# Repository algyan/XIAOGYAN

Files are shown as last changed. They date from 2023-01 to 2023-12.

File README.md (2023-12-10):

# XIAOGYAN

IoT ALGYAN 8周年 オリジナルIoTデバイス「XIAOGYAN」のリポジトリです。

IoTをやってみたい人から、バリバリのベテランにも楽しんでもらえるIoTデバイスを目指しています。

* デバイス、ソフトウェア、クラウドの全てにおいて、完成品（クラウドはお試しする場所）を提供するとともに、全てをオープン、カスタマイズ可能に
* 入手しやすい部品（ほぼ全ての部品を秋月電子通商で入手できる）
* 部品代は3000円以内
* 開発PCはWindows, macOS, Linux

ご質問、ご意見は[Discussions](https://github.com/algyan/XIAOGYAN/discussions)や[Issues](https://github.com/algyan/XIAOGYAN/issues)へ。お気軽にどうぞ。

## 構成

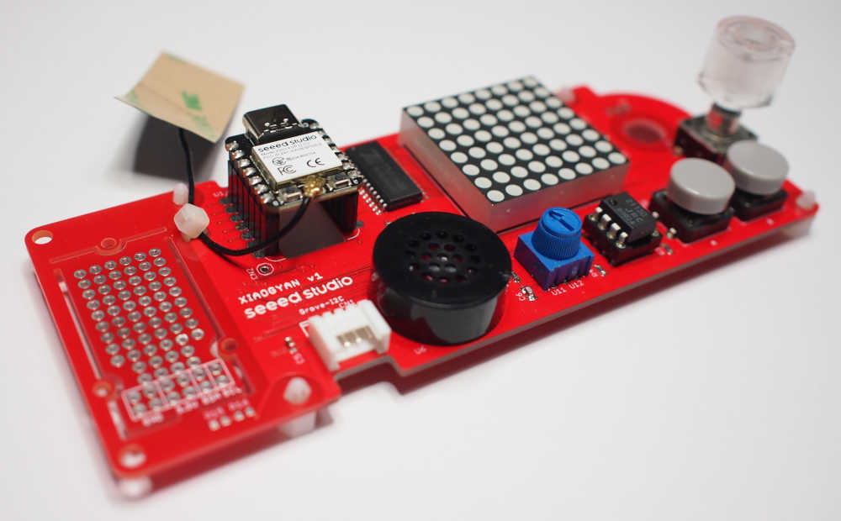
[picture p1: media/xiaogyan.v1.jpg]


```mermaid
flowchart LR
    id1[LEDマトリックス]---id7[LEDドライバ]
    id7-- x2 DO ---id2[マイコン]
    id3[スピーカー]---id11[パワーアンプ]
    id11-- x1 PWM,x1 DO ---id2
    id4[ロータリーエンコーダー]-- x2 DI ---id2
    id8[x1 LED]-- x1 DO ---id2
    id9[x2 ボタン]-- x2 DI ---id2
    id2-- Wi-Fi ---id6[Azure IoT]
    id10[Grove I2C]-- I2C ---id2
```

## マニュアル

* [しおり（手引書）](manuals/guidebook/README.md)
* [部品手配マニュアル](manuals/order/README.md)
* [機材マニュアル](manuals/equipment/README.md)
* [組立マニュアル](manuals/assembly/README.md)
* [動作確認マニュアル](manuals/test/README.md)
* [ソフトウェア開発マニュアル](manuals/software/README.md)

## 事例

* [XIAOGYANやってみたよ！！ユーザー投稿](https://github.com/algyan/XIAOGYAN/discussions/50)
* [XIAOGYANbitLess （XIAOGYANをScratchで使うためのプログラム）](https://github.com/610t/XIAOGYANbitLess)
* [XIAO-ESP32-C3 で AtomVM を動作させたときのメモ](https://gist.github.com/pojiro/ccb9d88dedd0590a8ac6930b37633ee0)
* [XIAOGYANでEagleのグリッド切り替え](https://github.com/lipoyang/GridSwitch)

## リファレンス

* ハードウェア
  * [部品リスト](hardware/xiaogyan.v1.xlsx)
  * [部品貼付台紙](hardware/xiaogyan_pasteboard.v1.pdf)
  * [回路図(v1)](hardware/xiaogyan.v1.pdf)
  * [回路図(v1.1)](hardware/xiaogyan.v1.1.pdf)

* ソフトウェア
  * [サンプルコード](https://github.com/algyan/xiaogyan_examples)
  * [Arduino用ライブラリ](https://github.com/algyan/xiaogyan_arduino)

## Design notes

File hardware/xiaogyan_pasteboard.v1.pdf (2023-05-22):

# 【ALGYAN 8th プリント基板(XIAOGYAN) パーツリスト】

チップ抵抗0Ω
[ R8,R9 ]

チップ抵抗10KΩ
[ R1,R2,R3,R4,R5,R6,R7 ]

チップコンデンサ0.1uF
[ C1 ]

チップコンデンサ1uF
[ C2 ]

チップコンデンサ10uF
[ C3,C4,C5 ]

③
チップコンデンサ1000pF
[ C6 ]
① | ② | ⑯ | ④ | ⑤
LEDドライバIC(TM1640) [ U2 ] 向き注意 ⑥ | アンプIC(NJM2113D) [ U4 ] 向き注意 ⑦ | ボタン・可変抵抗 [ U9,U10,U11 ] ⑧ | スピーカー(UGSM23A) [ U6 ] 向き注意 ⑨ | LEDマトリックス(LTP-12188M-08) [ U3 ] 向き注意 ⑩
Groveコネクタ [ CN1 ] 向き注意 ⑪ | 細ピンヘッダ・分割ロング ピンソケット ⑫ | マイコン(XIAO ESP32C3) [ U1 ] 向き注意 ⑬ | ロータリーエンコーダー (EC12PLRVF) [ U7 ] ⑭ | 基板スペーサー ⑮

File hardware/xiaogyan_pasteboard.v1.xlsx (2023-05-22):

チップ抵抗0Ω [ R8,R9 ] | チップ抵抗10KΩ [ R1,R2,R3,R4,R5,R6,R7 ] | チップコンデンサ0.1uF [ C1 ] | チップコンデンサ1uF [ C2 ] | チップコンデンサ10uF [ C3,C4,C5 ]
 |  | ③
 |  | チップコンデンサ1000pF [ C6 ]
① | ② | ⑯ | ④ | ⑤
LEDドライバIC(TM1640) [ U2 ] | アンプIC(NJM2113D) [ U4 ] | ボタン・可変抵抗 [ U9,U10,U11 ] | スピーカー(UGSM23A) [ U6 ] | LEDマトリックス(LTP-12188M-08) [ U3 ]
向き注意 | 向き注意 |  | 向き注意 | 向き注意
⑥ | ⑦ | ⑧ | ⑨ | ⑩
Groveコネクタ [ CN1 ] | 細ピンヘッダ・分割ロングピンソケット | マイコン(XIAO ESP32C3) [ U1 ] | ロータリーエンコーダー(EC12PLRVF) [ U7 ] | 基板スペーサー
向き注意 |  | 向き注意
⑪ | ⑫ | ⑬ | ⑭ | ⑮

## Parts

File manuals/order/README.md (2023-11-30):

# XIAOGYAN 部品手配マニュアル🛒

XIAOGYANの完成品を入手する方法はありません。ご自身で部品を入手して、組み立てる必要があります。

必要な部品は[部品リスト](../../hardware/xiaogyan.v1.xlsx)に書いてあります。一部の部品を除き、ほとんどの部品は秋月電子通商のWebサイトで購入できます。本マニュアルを参考に、XIAOGYAN基板と部品を入手してください。

---

## 目次

1. [XIAOGYAN基板を入手](#xiaogyan基板を入手)
2. [秋月電子通商から購入](#秋月電子通商から購入)
3. [チップ抵抗（10KΩ）を購入](#チップ抵抗10kωを購入)

---

## XIAOGYAN基板を入手

matsujirushiのBOOTHから購入できます。

* [XIAOGYAN基板（10KΩ抵抗付き）](https://matsujirushi.booth.pm/items/5108023)

> 以前はイベントでXIAOGYAN基板を配布していましたが、[2023/9/2のイベント](https://algyan.connpass.com/event/292100/)を最後に配布は無くなりました。（Seeed株式会社から提供いただいた分が全て配布されました。）

~~XIAOGYAN基板は非売品です。IoT ALGYANコミュニティの特定イベントで配布しています。イベントに参加して入手してください。~~

* ~~[IoT ALGYANコミュニティのイベント](https://algyan.connpass.com/event/)~~

## 秋月電子通商から購入

> ここでは部品を購入しますが、もし機材も購入するなら一緒に注文したほうが送料が抑えられてお得です。  
> 機材について確認、検討いてから注文をオススメします。 -> [機材マニュアル](../equipment/README.md)

1. 秋月電子通商のWebサイトを開いて、部品を買い物かごに入れてください。

    下記リンクをクリックすると、秋月電子通商のWebサイトが表示されて、XIAOGYANの部品が自動的に買い物かごに入ります。

    * [秋月電子通商 部品を買い物かごに入れる](https://akizukidenshi.com/catalog/cart/cart.aspx?goods=R-11619,P-16143,P-16994,P-13161,P-09285,C-12634,M-17454,C-04398,C-10073,I-13225,I-09878,I-11192,P-09797,P-05762,P-09828,P-06110,P-10089,&qty=1,1,1,1,1,1,1,1,1,1,1,1,1,1,2,1,4,)

2. 買い物かごの部品に間違いがないか確認してください。

    商品数は17品、商品小計は2700円（2023/5/9調べ）です。

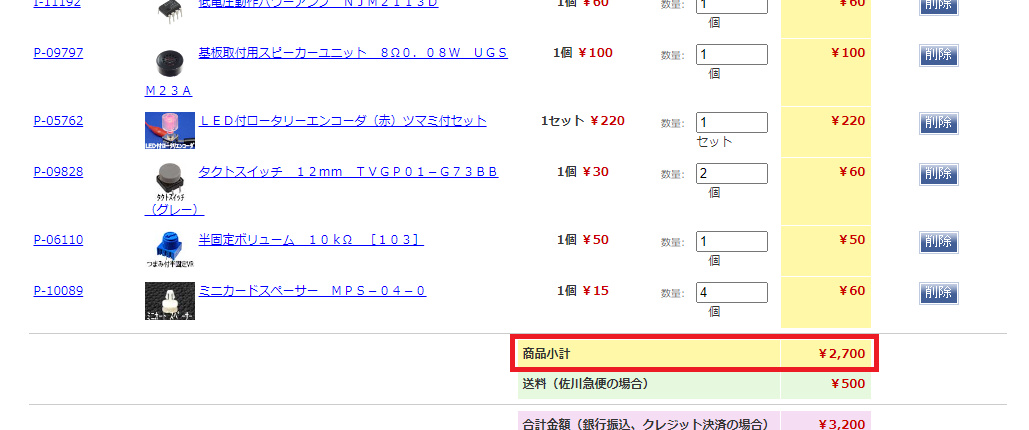
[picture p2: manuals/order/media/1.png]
    

3. 注文してください。

    注文画面へ進み、必要事項を記入して注文してください。

## チップ抵抗（10KΩ）を購入

秋月電子通商はチップ抵抗（10KΩ）をバラ売りしていません。秋月電子通商の5000個入りを購入するか、他店で購入してください。必要数は7個です。

* 秋月電子通商 [チップ抵抗　１／１０Ｗ１０ｋΩ　（５０００個入）](https://akizukidenshi.com/catalog/g/gR-15029/)
* マルツエレック [1608角形チップ抵抗器 RK73H 10kΩ 0.1W ±1%【RK73H1JTTD1002F】](https://www.marutsu.co.jp/pc/i/857775/)
* 共立電子産業 [チップ抵抗(1608) 10kΩ★受注単位有★](https://eleshop.jp/shop/g/gABQ364/)

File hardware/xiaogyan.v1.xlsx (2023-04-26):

 |  |  | 合計 | 2700
Part | Value | 通販コード | 入数 | 価格 | （価格） | 在庫グレード | 通販在庫数(2/2) | 通販在庫数(2/8) | 通販在庫数(3/6) | 通販在庫数(3/27)
R1 | 10K
R2 | 10K | (R1)
R3 | 10K | (R1)
R4 | 10K | (R1)
R5 | 10K | (R1)
R6 | 10K | (R1)
R7 | 10K | (R1)
R8 | 0 | R-11619 | 200 | 100 |  | AAA | 340 | 330 | 306 | 284
R9 | 0 | (R8)
R10 | DNP
R11 | DNP
R12 | DNP
R13 | DNP
R14 | DNP
R15 | DNP
R16 | DNP
C1 | 0.1u | P-16143 | 40 | 110 |  | AAA | 100 | 100 | 100 | 100
 |  | P-05728 | 100 |  | 200 | D,AAA |  | 2437 | 2393 | 2385
C2 | 1u | P-16994 | 20 | 200 |  | AAA | 2960 | 2947 | 2919 | 2898
C3 | 10u | P-13161 | 10 | 150 |  | AAA | 22187 | 22100 | 21869 | 21620
C4 | 10u | (C3)
C5 | 10u | (C3)
C6 | 1000p | P-09285 | 100 | 180 |  | AAA
C7 | DNP
C8 | DNP
CN1 | 4P-2.0 | C-12634 | 10 | 150 |  | AAA | 706 | 690 | 554 | 514
CN2
U1 | XIAO ESP32C3 | M-17454 | 1 | 940 |  | AAA | 2024 | 2005 | 1798 | 1642
 | 細ピンヘッダ | C-04398 | 1 | 20 |  | AA
 | 細ピンソケット | C-10073 | 1 | 80 |  | AAA
U2 | TM1640 | I-13225 | 1 | 80 |  | D,AAA | 3664 | 3664 | 3650 | 3642
U3 | LTP-12188M-08 | I-09878 | 1 | 140 |  | AAA | 561 | 506 | 486 | 482
U4 | NJM2113D | I-11192 | 1 | 60 |  | AA | 257 | 256 | 235 | 232
U5 | NJM2113M | I-10981 | 1 |  | 50 | D,A |  | 2 | 42 | 31
U6 | UGSM23A | P-09797 | 1 | 100 |  | AAA | 2848 | 2844 | 2816 | 2809
U7 | EC12PLRVF | P-05762 | 1 | 220 |  | AAA | 412 | 409 | 399 | 395
U8 | EC12E(Panel) | P-06357 | 1 |  | 80 | A | 0 | 0 | 0 | 0
U9 | TVGP01-G73BB | P-09828 | 1 | 30 |  | AAA | 4278 | 3880 | 2561
U10 | TVGP01-G73BB | P-09828 | 1 | 30 |  | AAA | 4278 | 3880 | 2561
U11 | 10K | P-06110 | 1 | 50 |  | AAA | 2000 | 2000 | 2000
U12 | DNP | P-08012 |  |  | 50 | AAA |  |  | 10454
U13 | DNP
JP1
JP2
JP3
 | MPS-04-0 | P-10089 | 1 | 15 |  | AAA
 | MPS-04-0 | P-10089 | 1 | 15 |  | AAA
 | MPS-04-0 | P-10089 | 1 | 15 |  | AAA
 | MPS-04-0 | P-10089 | 1 | 15 |  | AAA

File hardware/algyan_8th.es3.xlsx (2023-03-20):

 |  |  |  |  |  |  | 合計 | 2360
Part | Value | 通販コード | 在庫グレード | 通販在庫数(2/2) | 通販在庫数(2/8) | 通販在庫数(3/6) | 入数 | 価格 | （価格） | v1
C1 | 10u | P-13161 | AAA | 22187 | 22100 | 21869 | 10 | 150 |  | C3
C2 | 0.1u | P-16143 | AAA | 100 | 100 | 100 | 40 | 110 |  | C1
 |  | P-05728 | D,AAA |  | 2437 | 2393 | 100 |  | 200
C3 | DNP |  |  |  |  |  |  |  |  | C6
C5 | 1u | P-16994 | AAA | 2960 | 2947 | 2919 | 20 | 200 |  | C2
C6 | 10u | (C1) |  |  |  |  |  |  |  | C4
C7 | DNP |  |  |  |  |  |  |  |  | C7
C8 | DNP |  |  |  |  |  |  |  |  | C8
C9 | 10u | (C1) |  |  |  |  |  |  |  | C5
CN1 | 4P-2.0 | C-12634 | AAA | 706 | 690 | 554 | 10 | 150 |  | CN1
JP1 |  |  |  |  |  |  |  |  |  | JP1
JP2 |  |  |  |  |  |  |  |  |  | JP3
JP3 |  |  |  |  |  |  |  |  |  | CN2
JP5 |  |  |  |  |  |  |  |  |  | JP2
LED1 | DNP |  |  |  |  |  |  |  |  | U13
R1 | 10K |  |  |  |  |  |  |  |  | R1
R2 | 10K | (R1) |  |  |  |  |  |  |  | R2
R3 | 10K | (R1) |  |  |  |  |  |  |  | R3
R4 | 10K | (R1) |  |  |  |  |  |  |  | R4
R5 | 0 | R-11619 | AAA | 340 | 330 | 306 | 200 | 100 |  | R7
R7 | 10K | (R1) |  |  |  |  |  |  |  | R5
R8 | DNP |  |  |  |  |  |  |  |  | R10
R9 | DNP |  |  |  |  |  |  |  |  | R11
R10 | 0 | (R5) |  |  |  |  |  |  |  | R8
R11 | 0 | (R5) |  |  |  |  |  |  |  | R9
R12 | DNP |  |  |  |  |  |  |  |  | R12
R13 | DNP |  |  |  |  |  |  |  |  | R13
R14 | DNP |  |  |  |  |  |  |  |  | R14
R15 | DNP |  |  |  |  |  |  |  |  | R15
R16 | DNP |  |  |  |  |  |  |  |  | R16
R18 | 10K | (R1) |  |  |  |  |  |  |  | R6
U1 | XIAO | M-17454 | AAA | 2024 | 2005 | 1798 | 1 | 940 |  | U1
U2 | TM1640 | I-13225 | D,AAA | 3664 | 3664 | 3650 | 1 | 80 |  | U2
U4 | LTP-12188M-08 | I-09878 | AAA | 561 | 506 | 486 | 1 | 140 |  | U3
U5 | NJM2113D | I-11192 | AA | 257 | 256 | 235 | 1 | 60 |  | U4
U3 | NJM2113M | I-10981 | D,A |  | 2 | 42 | 1 |  | 50 | U5
U6 | UGSM23A | P-09797 | AAA | 2848 | 2844 | 2816 | 1 | 100 |  | U6
U7 | EC12PLRVF | P-05762 | AAA | 412 | 409 | 399 | 1 | 220 |  | U7
U10 | EC12E(Panel) | P-06357 | A | 0 | 0 | 0 | 1 |  | 80 | U8
U8 | TVGP01-G73BB | P-09828 | AAA | 4278 | 3880 | 2561 | 1 | 30 |  | U9
U9 | TVGP01-G73BB | P-09828 | AAA | 4278 | 3880 | 2561 | 1 | 30 |  | U10
VR1 | 10K | P-06110 | AAA | 2000 | 2000 | 2000 | 1 | 50 |  | U11
VR2 | 10K | P-08012 | AAA |  |  | 10454 |  |  | 50 | U12

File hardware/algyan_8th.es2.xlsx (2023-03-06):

 |  |  |  |  |  | 合計 | 2480
Part | Value | 通販コード | 在庫グレード | 通販在庫数(2/2) | 通販在庫数(2/8) | 入数 | 価格 | （価格）
C1 | 10u | P-13161 | AAA | 22187 | 22100 | 10 | 150
C2 | 0.1u | P-16143 | AAA | 100 | 100 | 40 | 110
 |  | P-05728 | AAA |  | 2437 | 100 |  | 200
C3 | DNP
C5 | 1u | P-16994 | AAA | 2960 | 2947 | 20 | 200
C6 | 10u | (C1)
C7 | DNP
C8 | DNP
C9 | 10u | (C1)
CN1 | 4P-2.0 | C-12634 | AAA | 706 | 690 | 10 | 150
JP1
JP2
JP3
JP5
LED1 | LED5MM | I-11580 | AAA | 2411 | 2406 | 10 | 120
R1 | 100K
R2 | 100K | (R1)
R3 | 10K
R4 | 10K | (R3)
R5 | 0 | R-11619 | AAA | 340 | 330 | 200 | 100
R6 | 0 | (R5)
R7 | ?
R8 | DNP
R9 | DNP
R10 | 0 | (R5)
R11 | 0 | (R5)
R12 | 10K | (R3)
R13 | DNP
R14 | DNP
R15 | DNP
R16 | DNP
R17 | 0 | (R5)
U1 | XIAO | M-17454 | AAA | 2024 | 2005 | 1 | 940
U2 | TM1640 | I-13225 | D,AAA | 3664 | 3664 | 1 | 80
U3 | NJM2113M | I-10981 | D,A |  | 2 | 1 |  | 50
U4 | LTP-12188M-08 | I-09878 | AAA | 561 | 506 | 1 | 140
U5 | NJM2113D | I-11192 | AA | 257 | 256 | 1 | 60
U6 | UGSM23A | P-09797 | AAA | 2848 | 2844 | 1 | 100
U7 | EC12PLRVF | P-05762 | AAA | 412 | 409 | 1 | 220
U8 | TVGP01-G73BB | P-09828 | AAA | 4278 | 3880 | 1 | 30
U9 | TVGP01-G73BB | P-09828 | AAA | 4278 | 3880 | 1 | 30
U10 | EC12E(Panel) | P-06357 | A | 0 | 0 | 1 |  | 80
VR1 | 10K | P-06110 | AAA | 2000 | 2000 | 1 | 50
VR2 | 10K | P-08012 | AAA

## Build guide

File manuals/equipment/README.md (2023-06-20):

# XIAOGYAN 機材マニュアル

## 1. 機材（極力、お安い構成） - 6000円未満

| 品名 | 型番 | 販売店 |
| :-- | :-- | :-- |
| はんだごて | CXR-41 | 秋月電子通商 T-02542 |
| こて台 | ST-77 | 秋月電子通商 T-06870 |
| 糸はんだ | SD-62 | 秋月電子通商 T-02594 |
| はんだ吸い取り線 | CP-3015 | 秋月電子通商 T-02539 |
| ニッパー | | 100円ショップ |
| ピンセット | | 100円ショップ |
| マスキングテープ | | 100円ショップ |
| テスター | DT-830B.3L | 秋月電子通商 M-08366 |

## 2. 機材（少し良いモノ構成） - 10000円未満

| 品名 | 型番 | 販売店 |
| :-- | :-- | :-- |
| はんだごて | FX600-02 | 秋月電子通商 T-14456 |
| こて台 | FH300-81 | 秋月電子通商 T-14458 |
| 糸はんだ | SD-62 | 秋月電子通商 T-02594 |
| はんだ吸い取り線 | CP-3015 | 秋月電子通商 T-02539 |
| はんだ吸い取り器 | GS-158 | 秋月電子通商 T-17386 |
| ニッパー | | 100円ショップ |
| ピンセット | TS-15 | 秋月電子通商 T-02541 |
| マスキングテープ | | 100円ショップ |
| テスター | DT-830B.3L | 秋月電子通商 M-08366 |

## 3. 機材（松岡の場合）

| 品名 | 製品 | こだわり |
| :-- | :-- | :-- |
| はんだごて | FX-600 + T18-C08 + M19-03 | 温調付き。 |
| こて台 | 不明 |  |
| 糸はんだ | SF-A0404 + FS600-02 | 0.4mmと0.8mm。付けにくいけど安心な鉛フリー。 |
| はんだ吸い取り線 | CP-2515 |  |
| はんだ吸い取り器 | SC-7000 | 電動。 |
| ニッパー | NS-03 | 開き量が設定できるので手が疲れない。 |
| ピンセット | PT-21 + P-640-J + 不明 | SMDチップ部品対応品。 |
| マスキングテープ | 243J Plus + MT-15P | プッシュカット便利。 |
| テスター | 753603 | |

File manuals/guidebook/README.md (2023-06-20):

# XIAOGYAN しおり🔖

ようこそ！XIAOGYANプロジェクトへ！

近年、電子工作がマジでお手軽になりましたね。ネットでポチれば数日で手元にくるし、高機能なマイコンやセンサーなども1個でも買うことができるようになりました。しかもお小遣い程度の金額で。数百万円出さないと使えなかった開発ツールは同等のものがタダで手に入ります。やる気と行動力さえあれば「わたしの欲しかったわたしのためのデバイス」を作って動かすことができちゃいます。
最近は、M5StackやreTerminalのようなディスプレイやボタンが付いているケース入りの製品で、センサーなどをコネクタで繋いでソフトウェアをチョイと書いてパッと仕上げること可能です。

便利になった反面、ちょっと寂しいなと思うところがあります。はんだ付けがうまくできたとかできなかったとか、部品壊れた悲しいとか。一喜一憂する電子工作の楽しさが減ってしまっているような気がしています。

そこで、オリジナルIoTデバイス**XIAOGYAN**をALGYANコミュニティで先導（扇動？）することにしました。

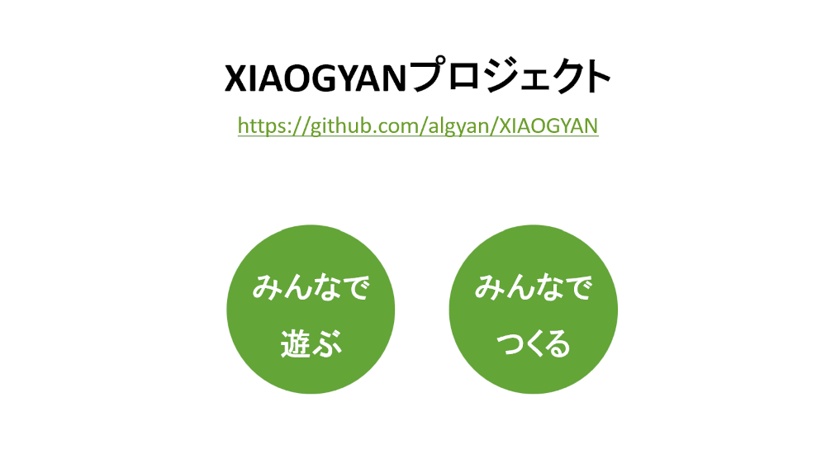
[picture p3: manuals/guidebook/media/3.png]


[「XIAOGYAN」への思い（動画）](https://www.youtube.com/watch?v=LFgrQTpkMbk&t=739s)

* デバイス、ソフトウェア、クラウドの全てをオープン、カスタマイズ可能に
* 入手しやすい部品
* 部品代は3000円以内
* 開発PCはWindows, macOS, Linux
* プロジェクトの進行もオープンに

見ているだけではダメです！
XIAOGYANプロジェクトに参加して、ぜひ一緒に楽しみましょう。

## XIAOGYANデバイス

XIAOGYANプロジェクトで用意したデバイスがこちらです。

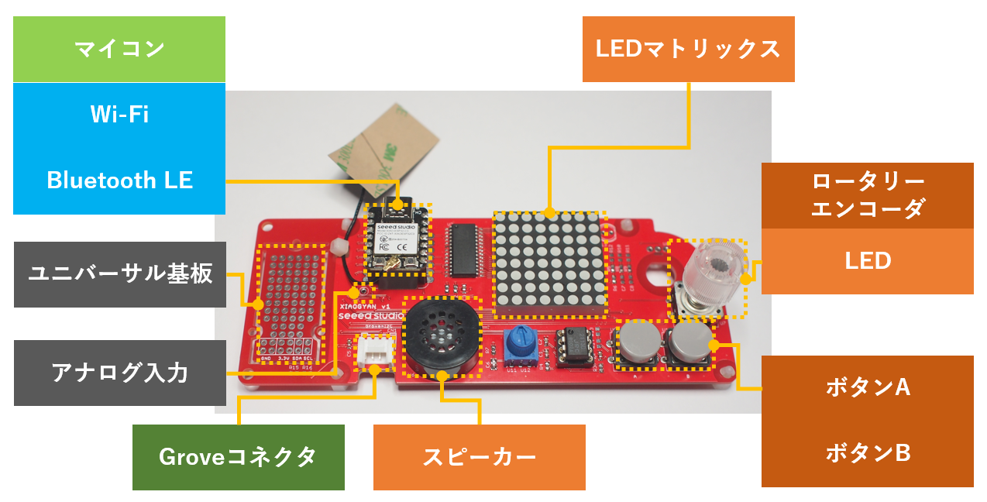
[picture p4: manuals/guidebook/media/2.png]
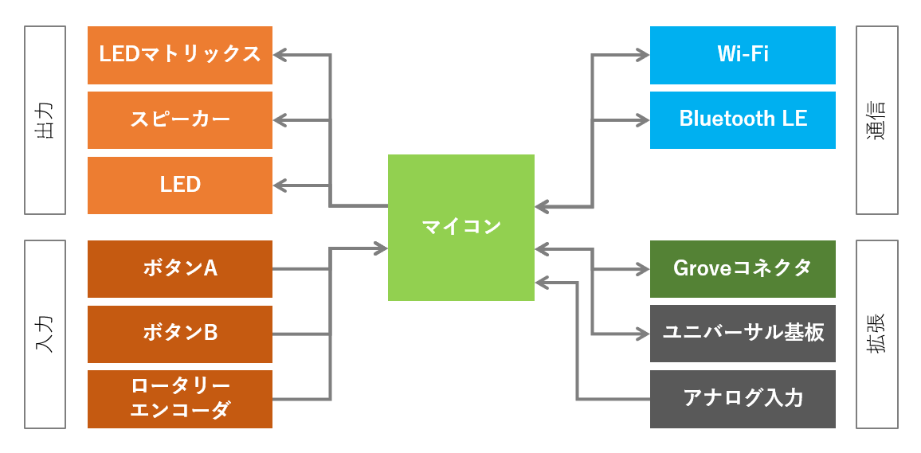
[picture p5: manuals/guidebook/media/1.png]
 

心臓部となるマイコンに[Seeed Studio XIAO ESP32C3](https://wiki.seeedstudio.com/XIAO_ESP32C3_Getting_Started)を採用しました。
このマイコンはWi-FiやBluetooth LEでクラウドやスマートフォンと通信することができます。アンテナが外付けなのでやり場に困るのですが、基板に結束バンドで固定できるようにしました。

そして、マイコンにそこそこ楽しめそうな電子部品を追加しました。

* 出力
    * LEDマトリックス

        ちょっとした表示（8x8ドットのLED）ができます。  
        液晶ディスプレイのほうがドットが多くて表示の自由度が高いのですが、ここはあえてLEDマトリックスにしました。このLEDマトリックスは各ドットに赤と緑のLEDが内蔵されていて、赤色,緑色,オレンジ色,消灯の4つを状態を表示できます。

    * スピーカー

        音が出せます。  
        オーディオパワーアンプを付けたので、結構な音量で出せます。FM音源LSIなどは載せていませんが、ソフトウェアをがんばって作れば凝った音が出せるかも？

    * LED

        ロータリーエンコーダの中央を赤色に点灯できます。  
        ソフトウェアのデバッグ用。

* 入力
    * ボタンA, ボタンB

        ボタン入力できます。2個。

    * ロータリーエンコーダ

        グルグルとノブを回す入力ができます。  
        この電子部品が好きなので載せました。グルグル回せるのが気持ちいいですね。右/左とか、増やす/減らすといった操作に最適です。

## 楽しみ方

### XIAOGYANを作って、動かして、改造する

1. はんだ付け🌶️
    * 電子部品販売店に部品を注文して入手
    * 基板に部品をはんだ付けして組み立て
    * ソフトウェアを書き込んで動作確認
2. ケースに入れる🌶️
    * 既製品のケースに収納、固定する
3. 部品を変える🌶️🌶️
    * 互換性を維持しつつ部品を交換する
4. ソフトウェアを入れる🌶️
    * サンプルのソフトウェアを入れる
5. ソフトウェアをいじる🌶️🌶️
    * ソフトウェアのソースコードを変更する
    * 新しくソフトウェアを作る
6. 機能を拡張する🌶️🌶️🌶️
    * Groveモジュールにセンサーを接続する
    * ソフトウェアを変更する

### XIAOGYANをやってみて感じたこと、得たことを発信する

1. SNS（Facebook, Twitter, Instagramなど）🌶️
2. 情報共有サイト（Qiita, Zennなど）🌶️🌶️
3. イベント登壇（ALGYANなど）🌶️🌶️🌶️

### XIAOGYANを報告、提案、改善する

1. [Discussions](https://github.com/algyan/XIAOGYAN/discussions)🌶️
2. [Issues](https://github.com/algyan/XIAOGYAN/issues)🌶️🌶️
3. [Pull requests](https://github.com/algyan/XIAOGYAN/pulls)🌶️🌶️🌶️

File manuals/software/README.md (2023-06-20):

# XIAOGYAN ソフトウェア開発マニュアル

## 1. はじめに

XIAOGYANのサンプルのソフトウェアは[PlatformIO](https://platformio.org/)で開発しています。
PlatformIO開発環境はみんな大好きVisual Studio Codeの拡張機能でも提供されていて、これを使うと簡単に開発環境を用意できます。

* [Visual Studio Code](https://azure.microsoft.com/ja-jp/products/visual-studio-code)
* [PlatformIO IDE for VSCode](https://marketplace.visualstudio.com/items?itemName=platformio.platformio-ide)

また、XIAOGYANのサンプルのソフトウェアはGitHubで管理しています。GitとVisual Studio Code拡張機能のGit Graphも使えるようになりましょう。

* [Git](https://git-scm.com/)
* [Git Graph extension for Visual Studio Code](https://marketplace.visualstudio.com/items?itemName=mhutchie.git-graph)

## 2. 開発ツールのインストール

### 2.1. Visual Studio Code

1. ブラウザで[Download Visual Studio Code](https://code.visualstudio.com/download)ページを開いてください。
2. `Windows`をクリックしてください。インストールファイルがダウンロードされます。
3. インストールファイルを実行してください。Visual Studio Codeのセットアップ画面が表示されます。
4. 画面の指示にしたがってセットアップを完了してください。
    * **使用許諾契約書の同意** - `同意する`を選択
    * **追加タスクの選択** - `PATHへの追加(再起動後に使用可能)`を選択

> [画面ショット](screenshot/install/vscode.md)

### 2.2. Git

1. ブラウザで[Download Git](https://git-scm.com/downloads)ページを開いてください。
2. `Windows`をクリックしてください。Download for Windowsページが表示されます。
3. `64-bit Git for Windows Setup`をクリックしてください。インストールファイルがダウンロードされます。
4. インストールファイルを実行してください。Gitのセットアップ画面が表示されます。
5. 画面の指示にしたがってセットアップを完了してください。
    * **Select Components** - `Git LFS`と`Scalar`を選択
    * **Choosing the default editor used by Git** - `Use Visual Studio Code as Git's default editor`を選択
    * **Adjusting your PATH environment** - `Git from the command line and also from 3rd-party software`を選択

> [画面ショット](screenshot/install/git.md)

### 2.3. Visual Studio Code拡張

1. Visual Studio Codeを起動してください。
2. EXTENSIONS画面で`MS-CEINTL.vscode-language-pack-ja`（Japanese Language Pack for Visual Studio Code）を検索してインストールしてください。
3. Visual Studio Codeを再起動してください。
4. 拡張機能画面で`mhutchie.git-graph`（Git Graph）を検索してインストールしてください。
5. 拡張機能画面で`platformio.platformio-ide`（PlatformIO IDE）を検索してインストールしてください。
6. Visual Studio Codeを再起動してください。

> [画面ショット](screenshot/install/vscodeext.md)

## 3. サンプルのソフトウェアをビルド、書き込み

1. ソース管理画面で`リポジトリのクローン`をクリックして実行してください。
    * **リポジトリのURL** - `https://github.com/algyan/xiaogyan_examples`
    * **複製するフォルダー** -- デスクトップを指定
2. 「クローンしたリポジトリを開きますか？画面で`開く`をクリックしてください。
3. ファイルの作成者を信頼する確認画面が表示されたときは`はい、作成者を信頼します`をクリックしてください。
4. ソース管理画面にある`View Git Graph`ボタンをクリックして、コミット一覧が表示されることを確認してください。
5. PLATFORMIO画面で`Pick a folder`をクリックして、`platformio/HardwareTest`フォルダーを選択してください。
6. XIAOGYANをUSB接続しておき、PLATFORMIO画面で`seeed_xiao_esp32c3/General/Upload`をクリックしてください。

> [画面ショット](screenshot/install/upload.md)

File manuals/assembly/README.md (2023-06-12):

# XIAOGYAN 組立マニュアル

「XIAOGYAN」の組立手順です．

## 1. はじめに

ハードウェア構成のイメージを持った後に，**部品の確認**と**機材の確認**を行いましょう！

### 1.1. ハードウェア構成の理解

  

XIAOGYANの構成は，マイコン(XIAO ESP32C3)を中心に，入力としてロータリーエンコーダー，ボタン×2と，出力としてLEDマトリックス，スピーカーを有します．
また，ロータリーエンコーダーには，LEDが内蔵されています．この内蔵LEDの制御信号(D6)は分岐しており，基板上のLED(U13・未実装)にも接続されています．

加えて，I2Cの信号線が繋がるGroveコネクタも用意されており，任意のGroveモジュール(3.3V駆動品)を拡張する事も可能です．
I2Cの制御信号は，基板左のユニバーサル基板の区画にも伸びています．このユニバーサル基板に回路を拡張すればすべてオンボードとすることも可能です．

### 1.2. 完成品を見ておこう

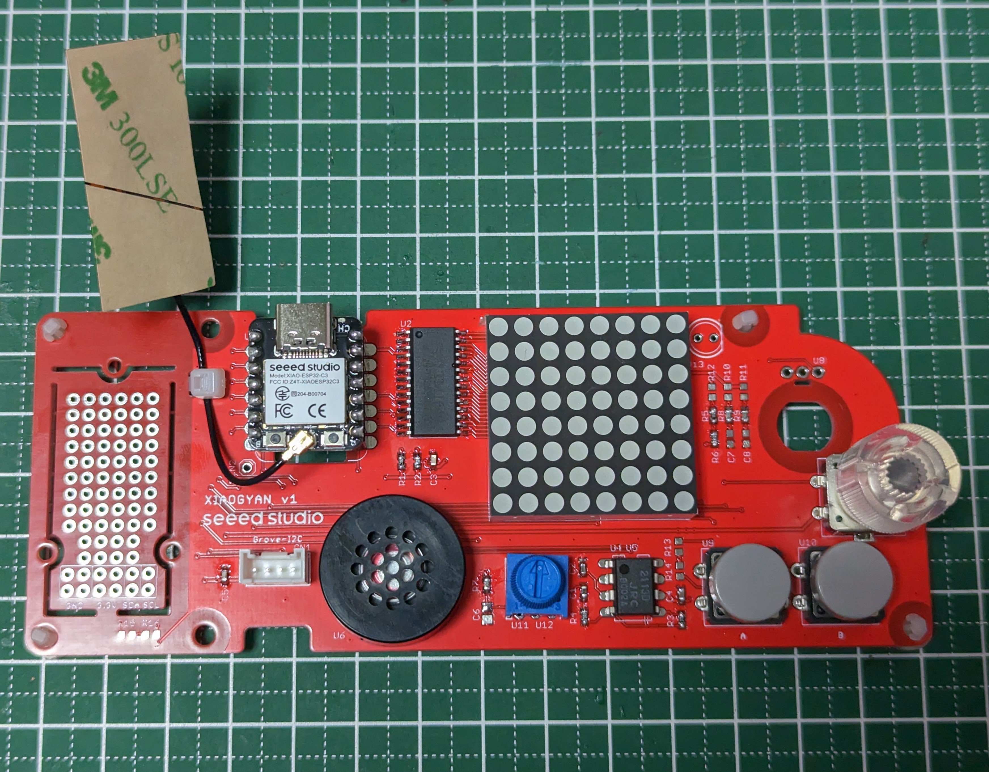
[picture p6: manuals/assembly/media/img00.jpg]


先に完成したXIAOGYANを見ておきましょう！
沢山，はんだ付けする部品があるように見えますが，1つ1つ取り組んでいけばバッチリ組み上がります．頑張っていきましょう！

### 1.3. 部品の確認

それでは，まず上記の[部品貼付台紙](../../hardware/xiaogyan_pasteboard.v1.pdf)をダウンロード＆印刷し，部品を並べることで部品の不足が無いことを確認しましょう．

1. チップ抵抗やチップコンデンサは，袋から取り出すと，容量の確認が非常に困難です．袋から取り出す際には必ず容量(10KΩ，0.1uFなど)を紙テープに書き込みましょう．
2. 部品の確認表に**赤字で「向き注意」** と書かれている部品は，**取り付けに向きがあります．** はんだ付けの際には注意しましょう．
3. それでは部品貼付台紙に部品を並べましょう！



実際に並べると上記のようになります．

### 1.4. 機材の確認

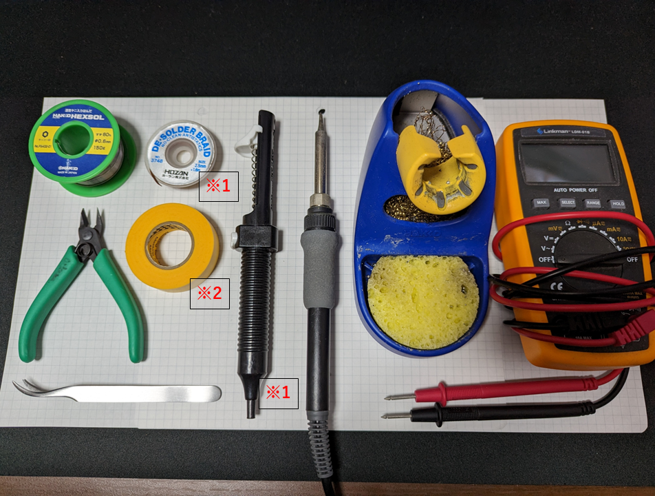
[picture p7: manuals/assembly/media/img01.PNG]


上記に組立に必要な機材のリストを示します．機材は手元に揃っていますか？
**※** マークのついた部品は，オプションです．手元に無くとも組立は可能です．

| 必須／オプション | 品名 | メモ |
| :---: | --- | --- |
| 必須 | はんだごて，こて台 |  |
| 必須 | 糸はんだ | 今回は鉛入り，ヤニ入り，φ0.6mmを使用 |
| 必須 | ニッパー，ピンセット | 部品の足をカットしたり，細かい部品を掴んだり |
| 必須 | テスター | 主に動作確認で使用 |
| ※1 | はんだ吸い取り線 or はんだ吸い取り器 | はんだを付け間違えた際のリカバリで使用します．どちらかあった方が無難 |
| ※2 | マスキングテープ | はんだ付け時に，部品の固定が難しい場合に使いましょう！ |

### 1.5. 組立＆動作確認の流れ

以降でXIAOGYANの組立＆動作確認を行います．組立は手慣れた人で1～2時間程度かと思われます．
流れは以下の通りです．

* 組立作業
    * 基板表面：表面実装品のはんだ付け
    * 基板裏面：ショートジャンパのはんだ付け
    * 基板表面：挿入実装品のはんだ付け
    * 足の取り付け
    * アンテナの固定
* チェック
    * ショートチェック

## 2. 組立作業

### 2.1. はんだ付けの経験が無い/浅い方へ

ichiken_handa (https://www.youtube.com/watch?v=dQ7AUjb1tkA)

YouTuberのイチケンさんの[はんだ付け動画](https://www.youtube.com/watch?v=dQ7AUjb1tkA)が分かりやすいです．
はんだ付けの経験が無い/浅い方は，一度ご覧の上で以降の作業に進むことをオススメします．表面実装の経験が無い方もぜひ！

### 2.2. 基板の確認

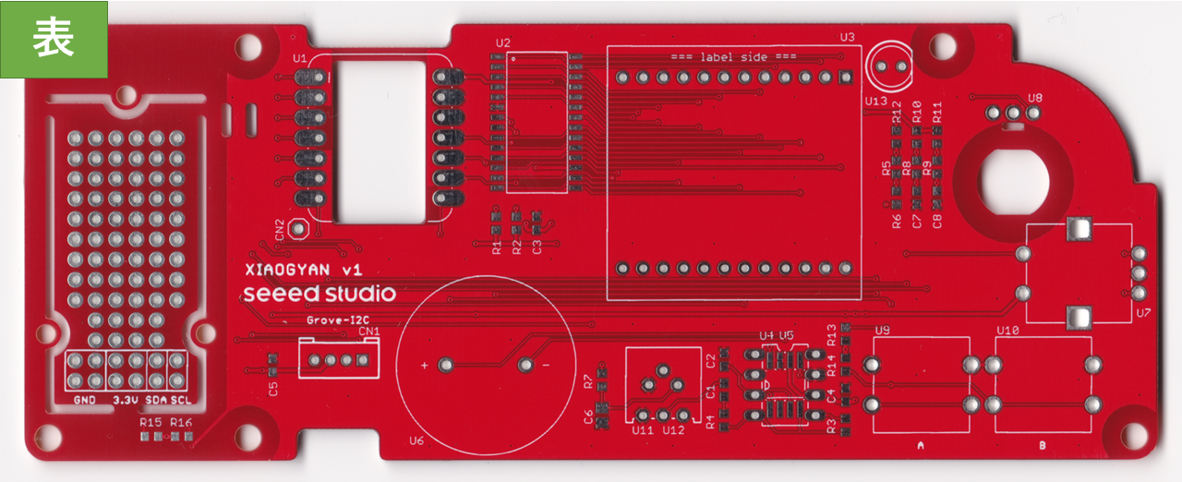
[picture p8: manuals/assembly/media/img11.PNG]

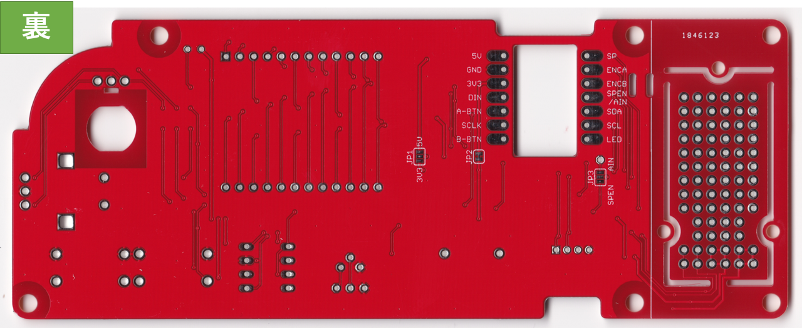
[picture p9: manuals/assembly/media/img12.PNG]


基板の表裏を確認します．部品はすべて表面に乗ることになります．

### 2.3. 基板表面：表面実装品のはんだ付け

基板の**表面**へのはんだ付けからスタートです．まずは表面実装品です．

表面実装品でも挿入実装品でも **背の低い部品** からはんだ付けしていく事が鉄則です．以下の流れに沿って進めましょう．

#### 2.3.1. チップ抵抗・チップコンデンサのはんだ付けの仕方

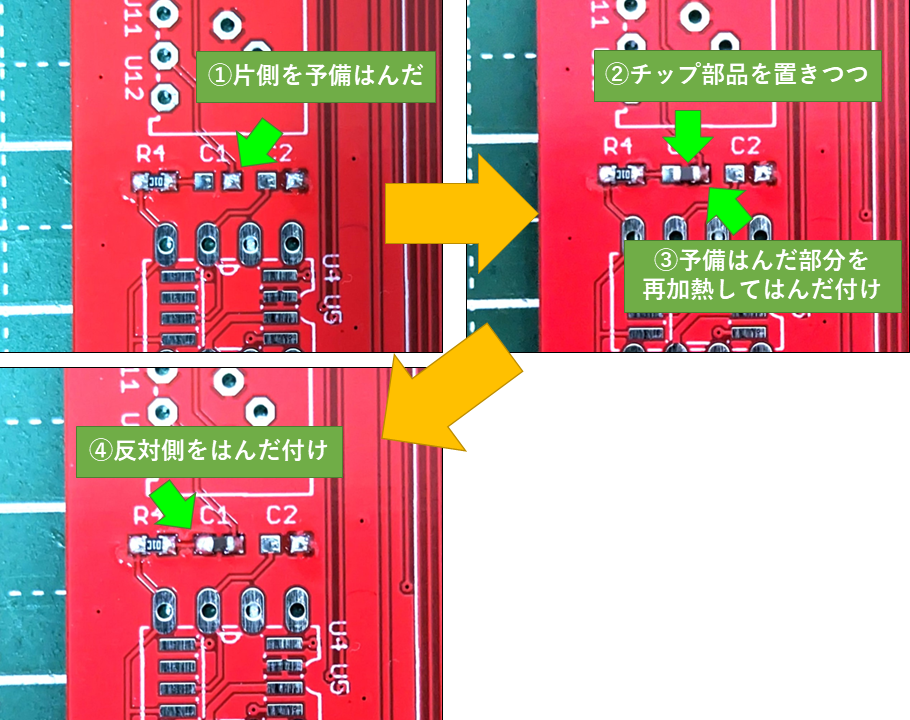
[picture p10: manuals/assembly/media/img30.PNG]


上記のように，手順を踏んではんだ付けすると綺麗にはんだ付けできます．
②と③は，ピンセットでチップ部品を持ちつつ，もう片方の手ではんだごてを扱うことで実現できます．（難しいですね

#### 2.3.2. チップ抵抗(0Ω)のはんだ付け

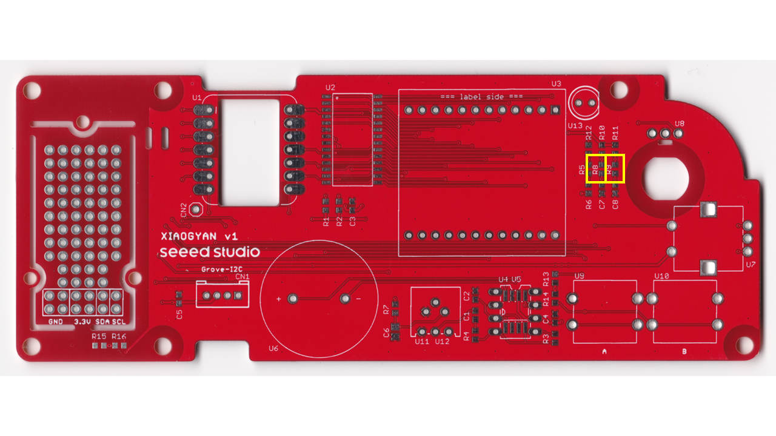
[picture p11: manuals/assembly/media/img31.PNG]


リスト①のチップ抵抗(0Ω)のはんだ付けを行います．黄枠で囲った箇所 **[R8,R9]** にはんだ付けを行って下さい．

#### 2.3.3. チップ抵抗(10KΩ)のはんだ付け

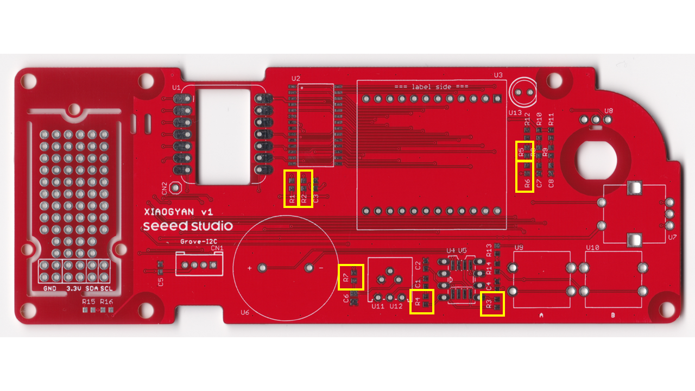
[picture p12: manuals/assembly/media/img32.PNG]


リスト②のチップ抵抗(10KΩ)のはんだ付けを行います．黄枠で囲った箇所 **[R1,R2,R3,R4,R5,R6,R7]** にはんだ付けを行って下さい．

#### 2.3.4. チップコンデンサ(0.1uF)のはんだ付け

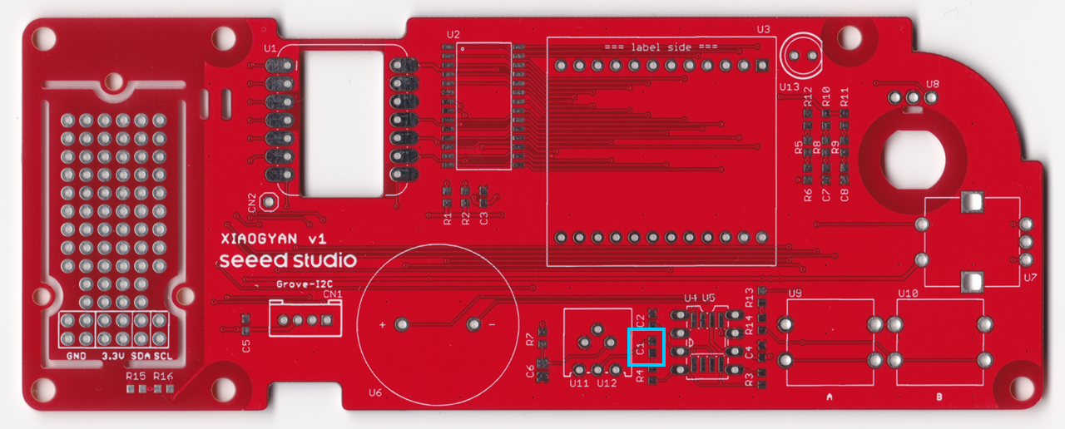
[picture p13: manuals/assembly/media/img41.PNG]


続いてチップコンデンサを実装します．0.1uF, 1uF, 10uF, 1000pFの4種類のチップコンデンサを使用します．
まずはリスト③の0.1uFのコンデンサ **[C1]** を実装します．青枠で囲った箇所にはんだ付けして下さい．

#### 2.3.5. チップコンデンサ(1uF)のはんだ付け

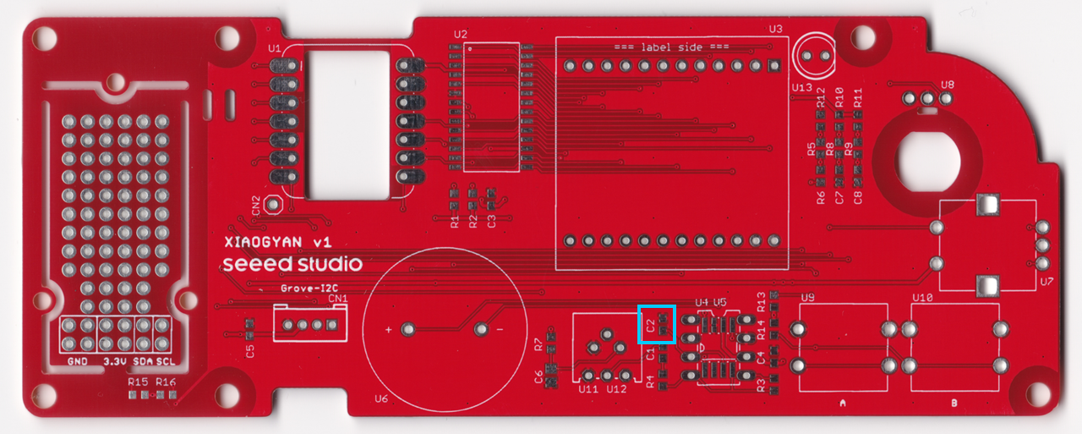
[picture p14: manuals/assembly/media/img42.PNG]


リスト④の1uFのコンデンサ **[C2]** を実装します．青枠で囲った箇所にはんだ付けして下さい．

#### 2.3.6. チップコンデンサ(10uF)のはんだ付け

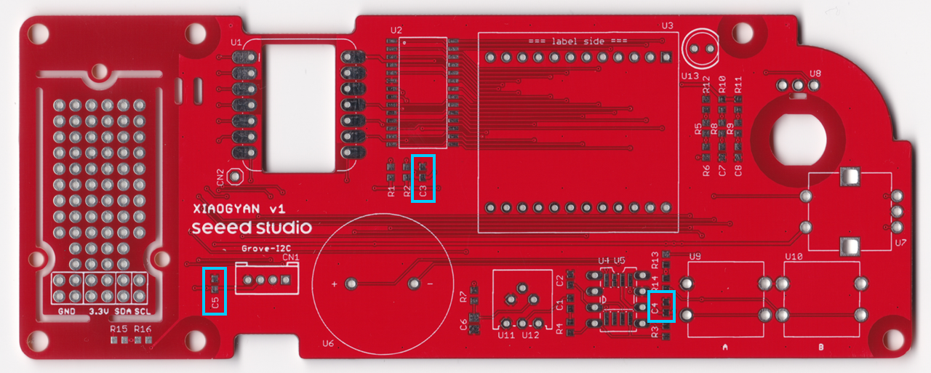
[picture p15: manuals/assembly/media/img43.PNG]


リスト⑤の10uFのコンデンサ **[C3,C4,C5]** を実装します．青枠で囲った箇所にはんだ付けして下さい．

#### 2.3.7. チップコンデンサ(1000pF)のはんだ付け

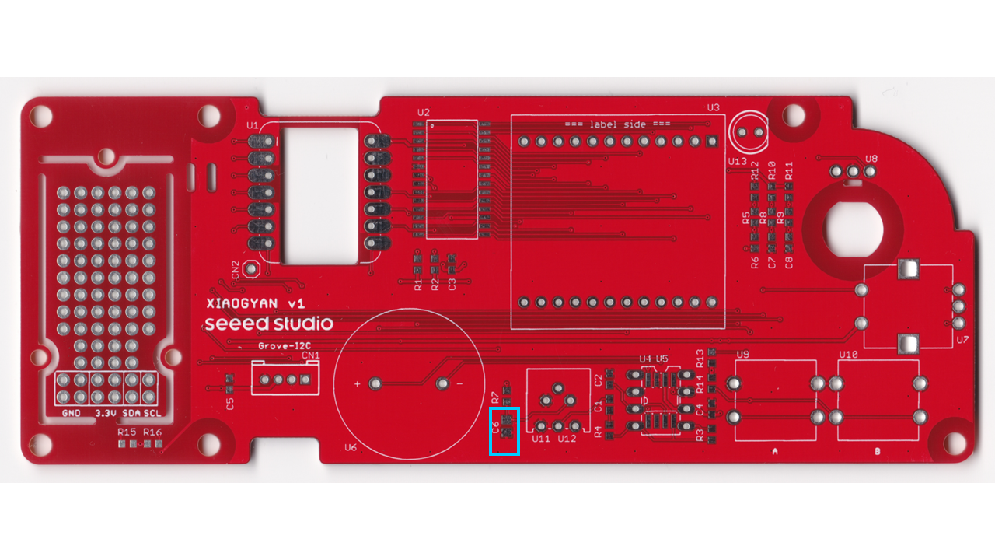
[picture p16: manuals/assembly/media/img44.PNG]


リスト⑯の1000pFのコンデンサ **[C6]** を実装します．青枠で囲った箇所にはんだ付けして下さい．

#### 2.3.8. チップ抵抗＆チップコンデンサの実装確認

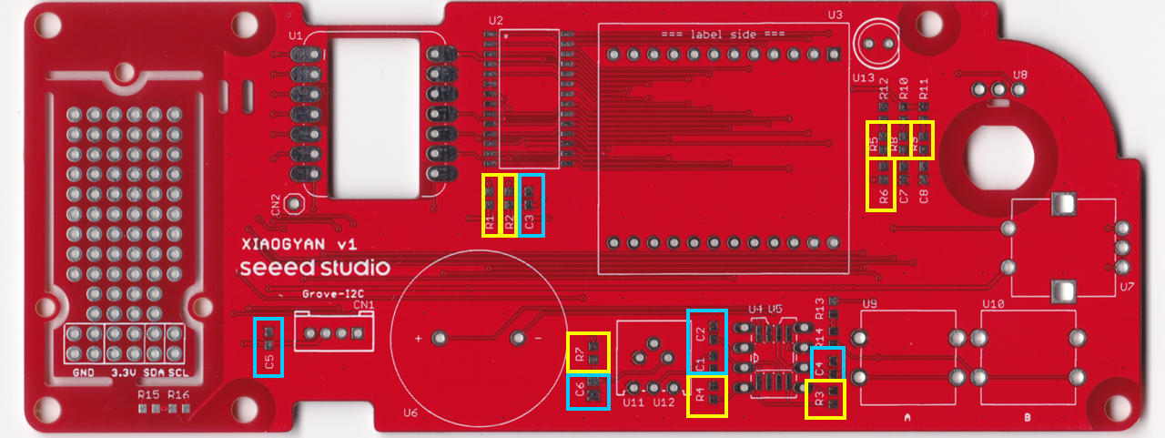
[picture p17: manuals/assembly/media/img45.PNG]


実装漏れはありませんか？あとで漏れに気づいてはんだ付けするには大変です．上図のマークアップ部分にチップ抵抗orチップコンデンサが実装されているか確認をしましょう！

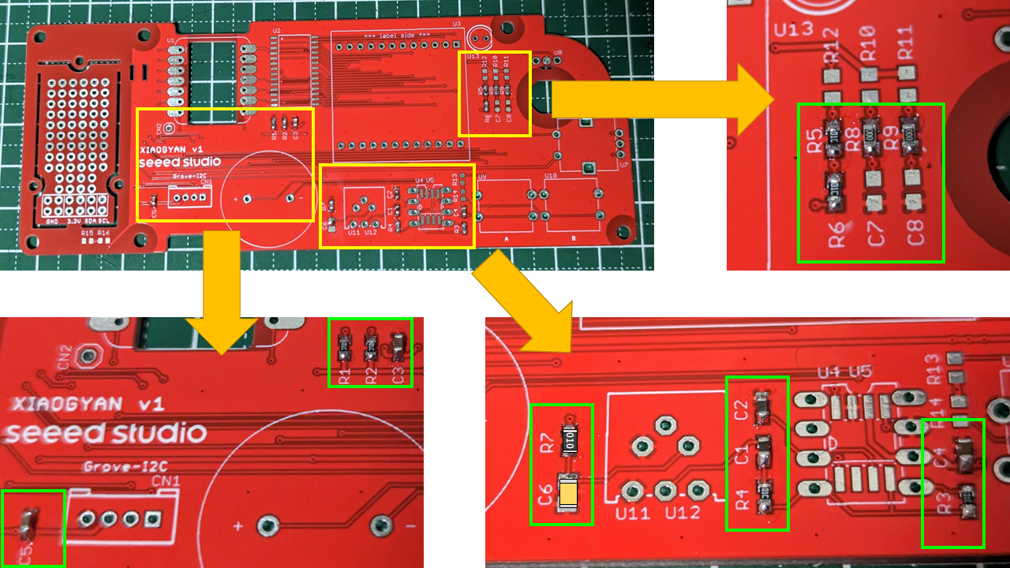
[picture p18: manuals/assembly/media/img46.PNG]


実際には上記のようにはんだ付けがなされていればOKです．

#### 2.3.9. LEDドライバIC(TM1640)のはんだ付け

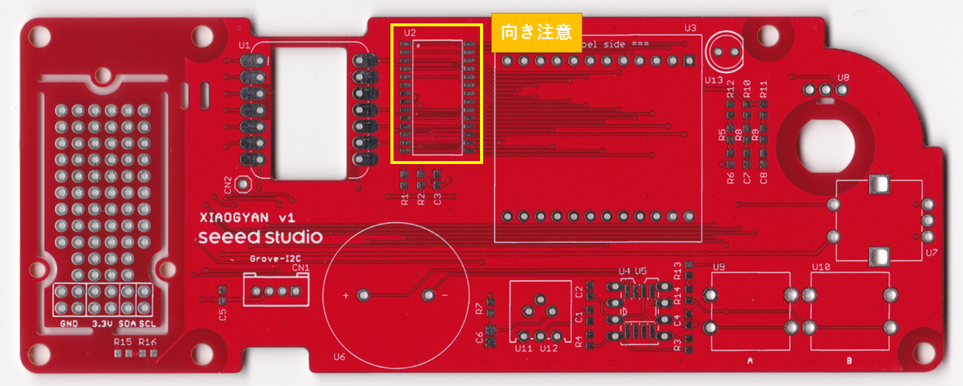
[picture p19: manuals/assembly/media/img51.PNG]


最後の表面実装です．リスト⑥のLEDドライバIC **[U2]** を実装します．黄枠で囲った箇所にはんだ付けして下さい．
尚，**本部品には取り付け向きがあります．** 注意してください．

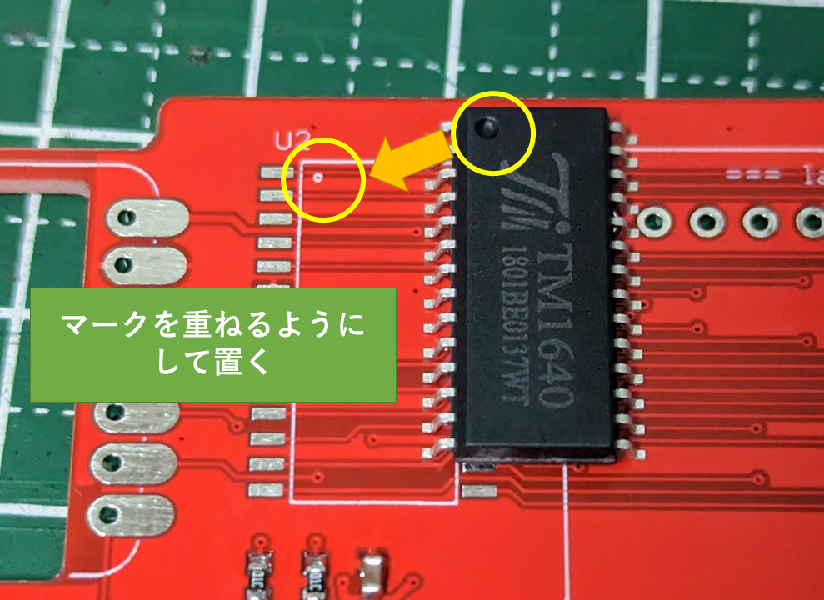
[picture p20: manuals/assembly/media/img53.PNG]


基板のU2の●にICの●が重なるように配置してください．

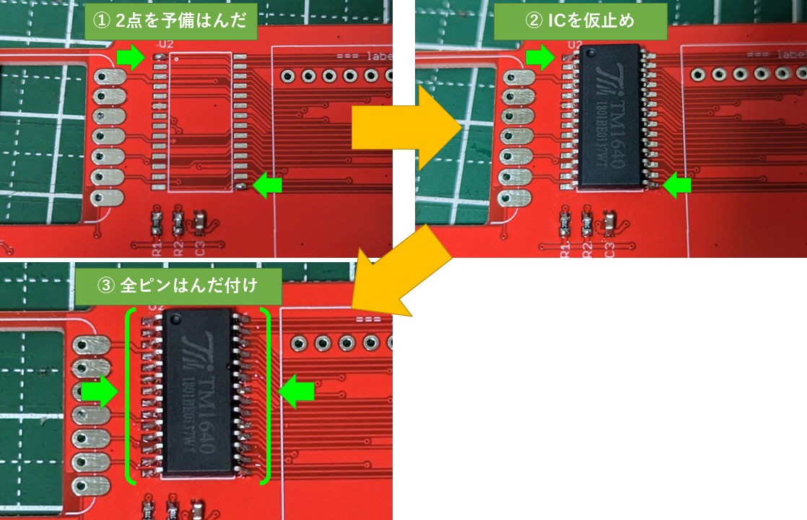
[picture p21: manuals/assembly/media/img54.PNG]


表面実装のICは上記のような手順ではんだ付けを行うと，はんだ付けが行いやすいです．

### 2.4. 基板裏面：ショートジャンパのはんだ付け

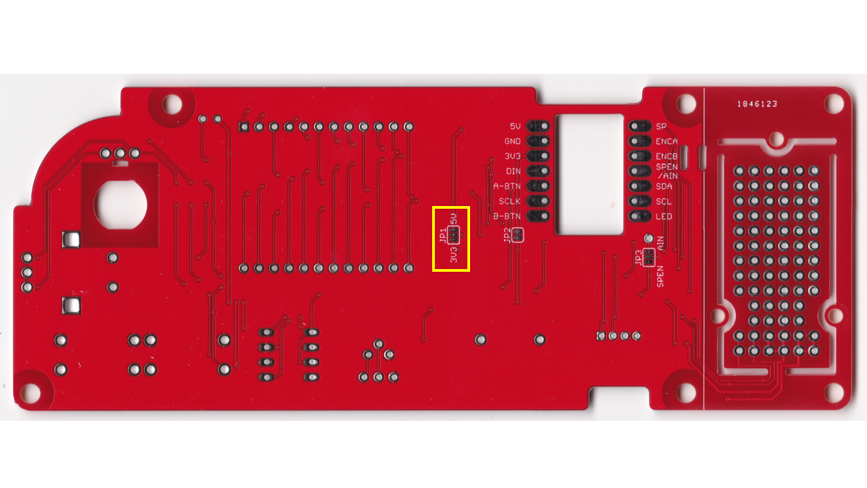
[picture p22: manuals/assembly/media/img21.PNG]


続いて基板の**裏面**へのはんだ付けです．

基板の裏面には3箇所(JP1～JP3)ほど，はんだ付けでショートさせる事によって回路を変更できる箇所があります．

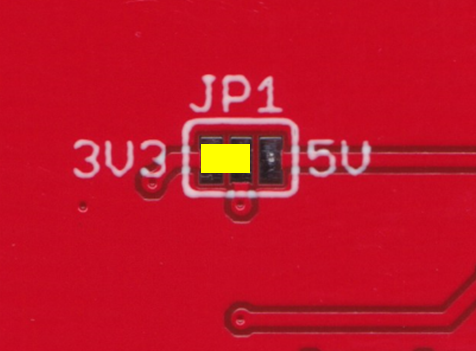
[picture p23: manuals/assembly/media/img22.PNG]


今回の組立では，**JP1のみショート**させます．
JP1は，LEDマトリックスを制御するドライバIC(TM1640)の動作電圧を選択する為のものです．
今回は3.3Vで動作させますので，3V3側にショートさせます．黄色の部分をはんだでショートさせて下さい．

以上で表面実装部品のはんだ付けは完了です．
ひとやすみした後に挿入実装品のはんだ付けへ進んで下さい．

### 2.5. 基板表面：挿入実装品のはんだ付け

再び基板の**表面**へのはんだ付けになります．今度は挿入実装品です．

挿入実装品でも **背の低い部品** からはんだ付けしていく事が鉄則です．以下の流れに沿って進めましょう．

#### 2.5.1. アンプIC(NJM2113D)のはんだ付け

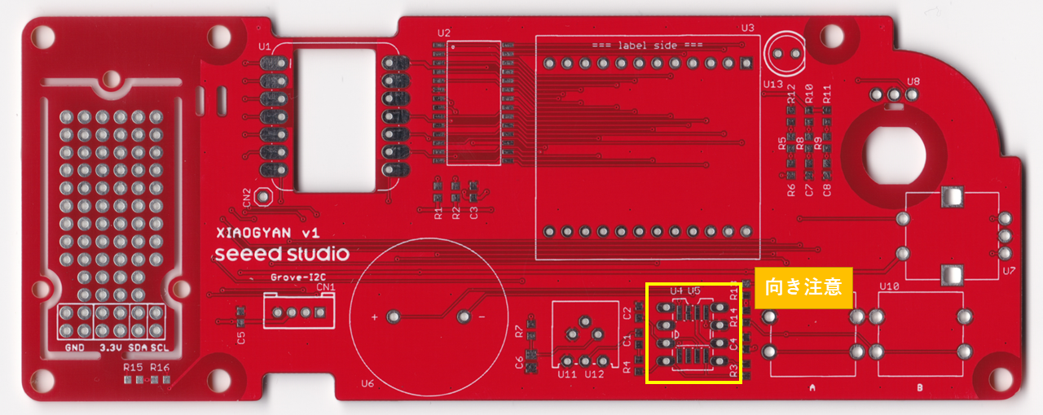
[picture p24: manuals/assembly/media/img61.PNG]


リスト⑦のアンプIC **[U4]** を実装します．黄枠で囲った箇所にはんだ付けして下さい．
尚，**本部品には取り付け向きがあります．** 注意してください．

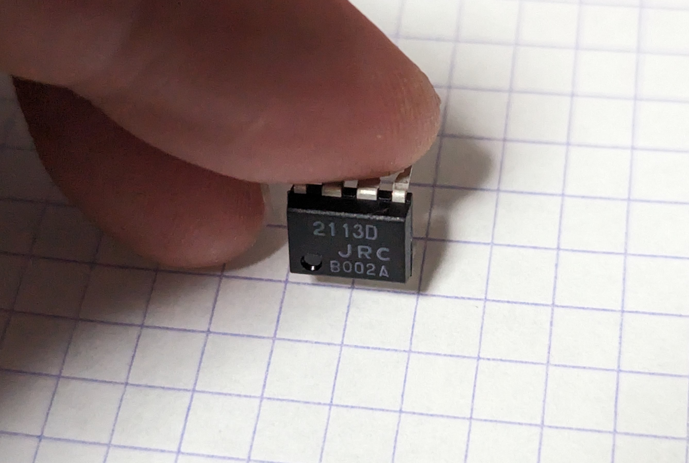
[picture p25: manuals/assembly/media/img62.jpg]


新品のICは，足がハの字に広がっている為に基板へ挿しづらいです．上記の図のように平らな面に指で押しつけて両足をやや内側に曲げた後に挿してください．

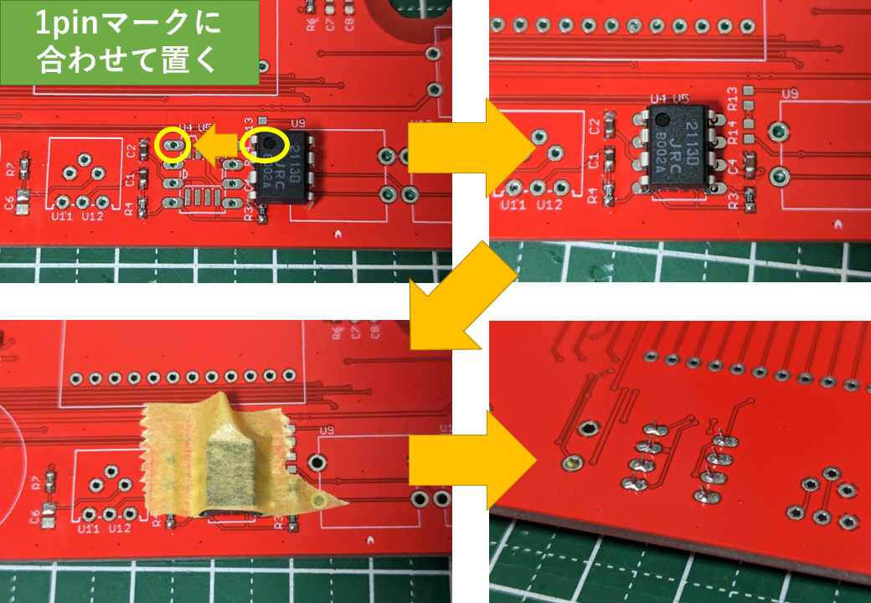
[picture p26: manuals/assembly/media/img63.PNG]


ICには取り付け向きがあります．切り欠きの向きが一致するように取り付けてください．
はんだ付けの時に，ICが抜け落ちてしまう場合は，マスキングテープで固定するとはんだ付けがやりやすいです．

#### 2.5.2. ボタン・可変抵抗のはんだ付け

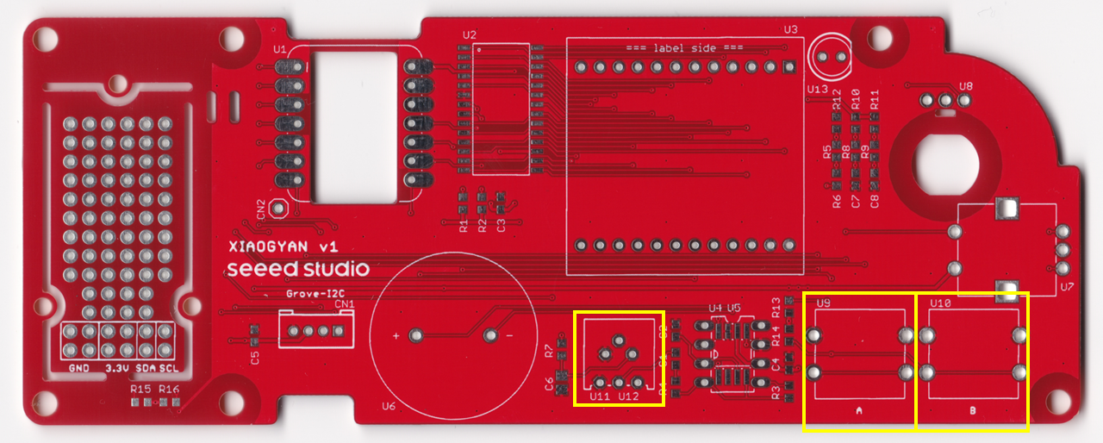
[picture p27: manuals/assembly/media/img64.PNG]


リスト⑧のボタン **[U9,U10]** ・可変抵抗 **[U11]** を実装します．黄枠で囲った箇所にはんだ付けして下さい．

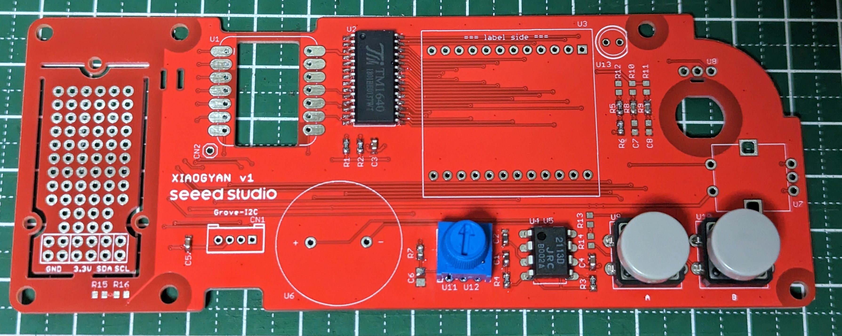
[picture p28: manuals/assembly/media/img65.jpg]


実際に取り付けると，上記の図のようになります．

#### 2.5.3. スピーカー・LEDマトリックスのはんだ付け

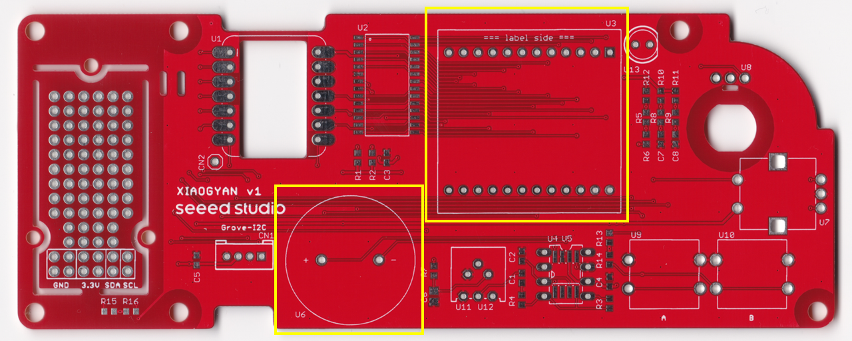
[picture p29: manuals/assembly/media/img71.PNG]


リスト⑨のスピーカー **[U6]** とリスト⑩のLEDマトリックス **[U3]** を実装します．黄枠で囲った箇所にはんだ付けして下さい．
尚，**2つの部品には取り付け向きがあります．** 注意してください．

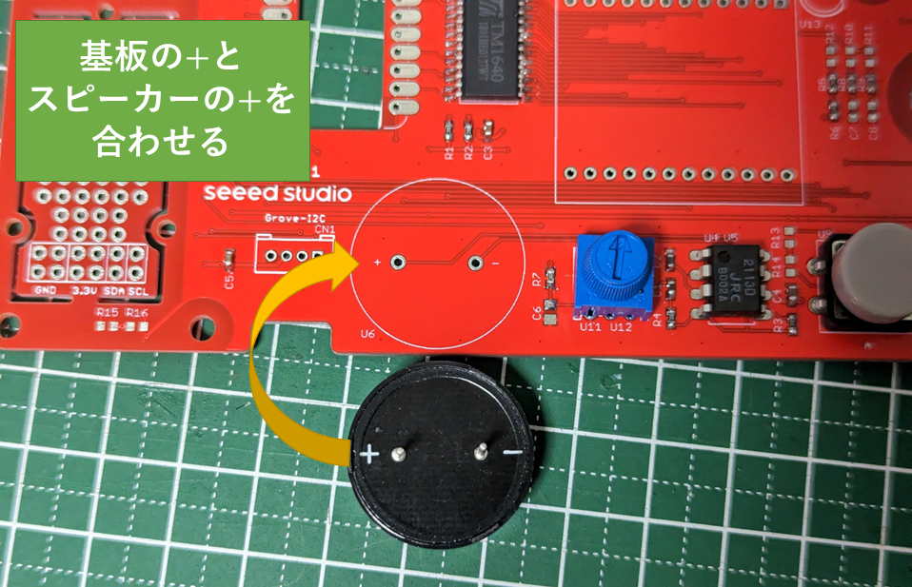
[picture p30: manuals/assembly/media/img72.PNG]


スピーカーの場合，部品裏面にある+と-が，基板の+と-に一致するように取り付けてください．
また，はんだ付け時に固定が難しい場合はマスキングテープを使いましょう！

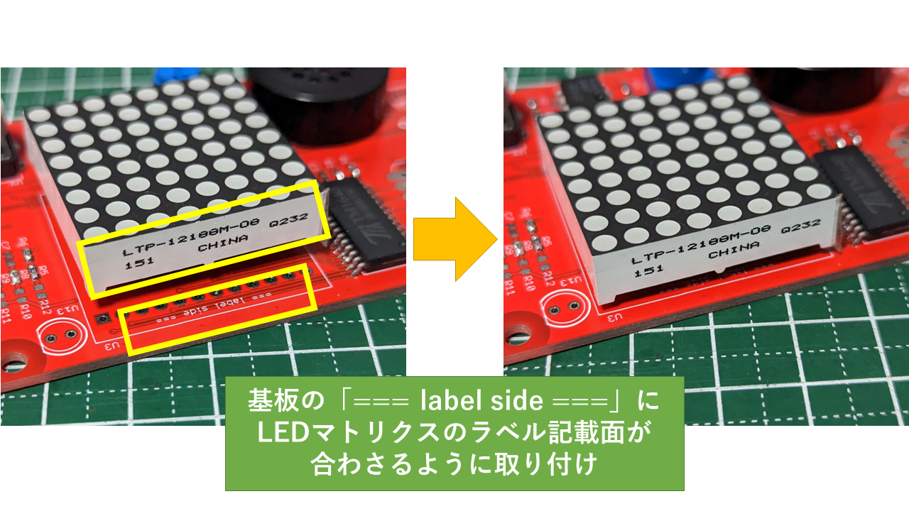
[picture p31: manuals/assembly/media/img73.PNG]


LEDマトリックスの場合，側面に印字された「型番ラベル」と基板に印字された「=== label side ===」が，一致するように取り付けてください．
また，はんだ付け時に固定が難しい場合はマスキングテープを使いましょう！

#### 2.5.4. Groveコネクタのはんだ付け

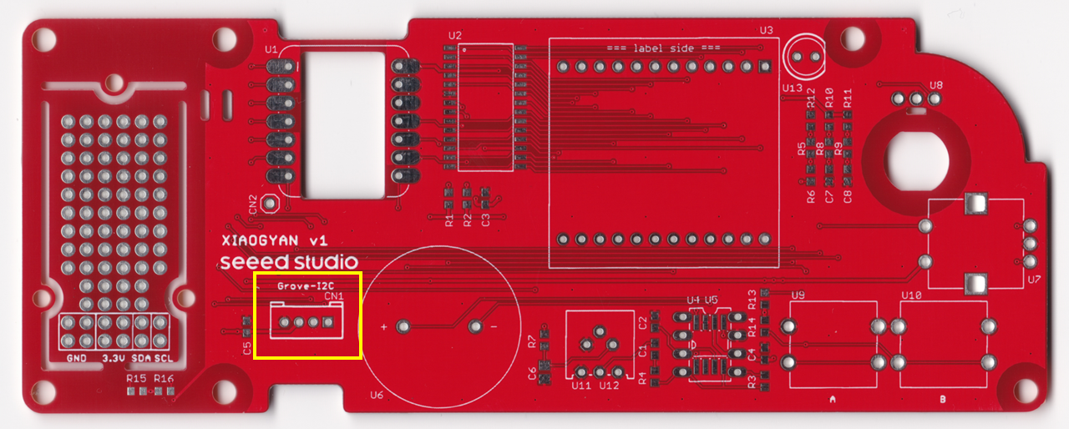
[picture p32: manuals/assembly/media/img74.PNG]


リスト⑪のGroveコネクタ **[CN1]** を実装します．黄枠で囲った箇所にはんだ付けして下さい．
尚，**本部品には取り付け向きがあります．** 注意してください．

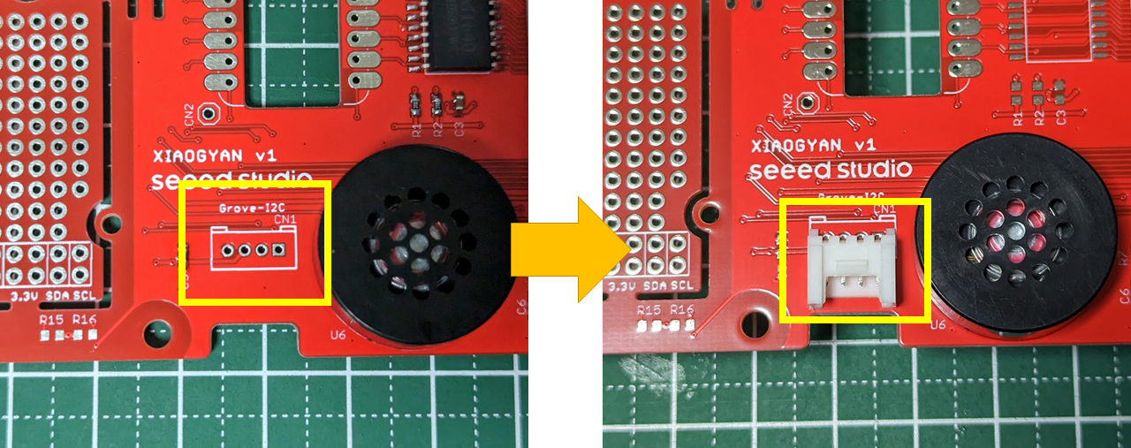
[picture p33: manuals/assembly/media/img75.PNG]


コネクタの突起が基板のシルクと一致するような向きで取り付けてください．
また，はんだ付け時に固定が難しい場合はマスキングテープを使いましょう！

#### 2.5.5. マイコンの取り付け

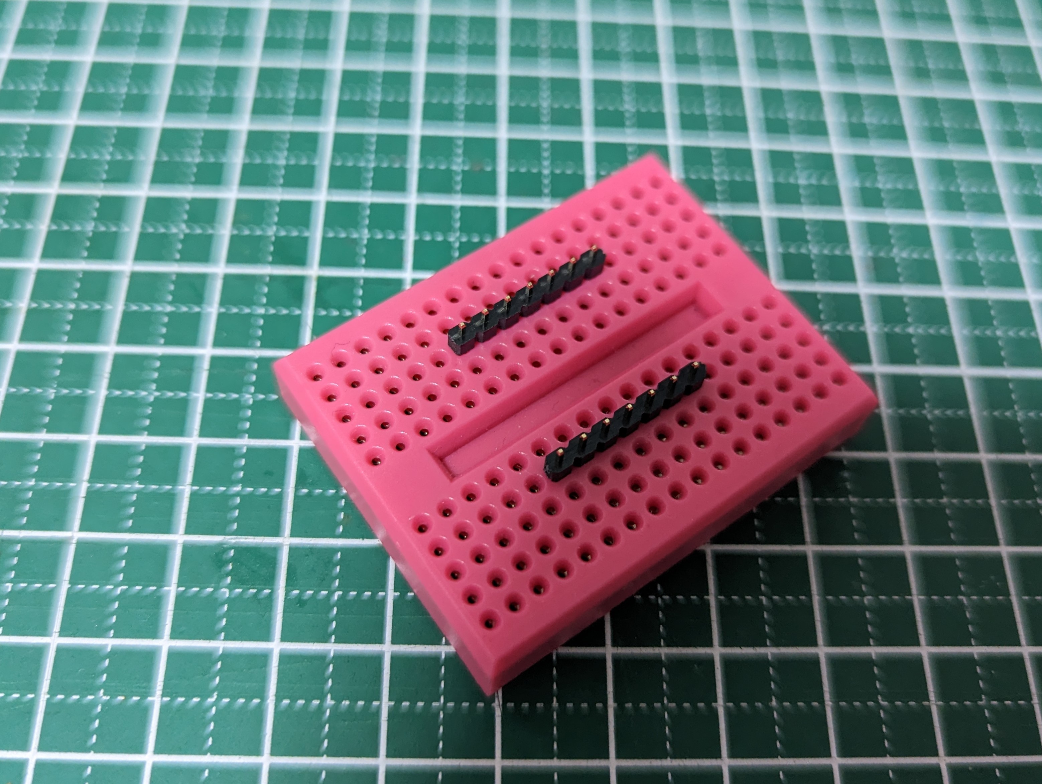
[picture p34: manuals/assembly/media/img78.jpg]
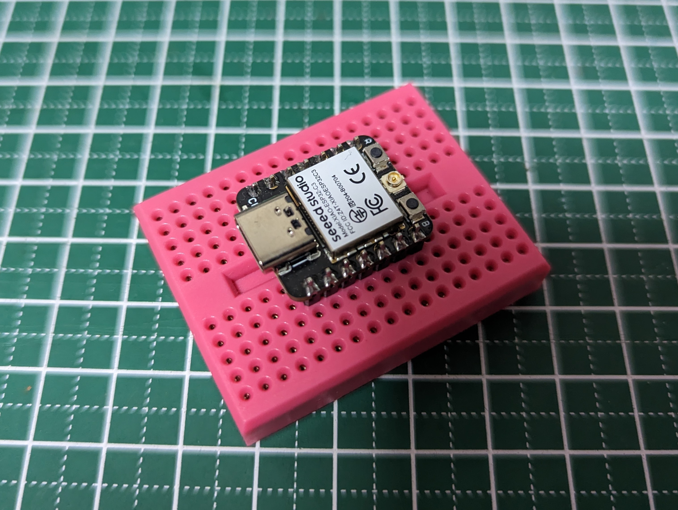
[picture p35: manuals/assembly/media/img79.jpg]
  

リスト⑬のマイコンに対して，リスト⑫の細ピンヘッダを実装します．上記の図のようにお手持ちのブレッドボードに細ピンヘッダを挿して固定した後にはんだ付けを行うと楽です．
尚，この細ピンヘッダを実装する事により，マイコンをXIAOGYANから取り外すことが可能となり他のXIAOシリーズのマイコンに置き換えることが可能となります．

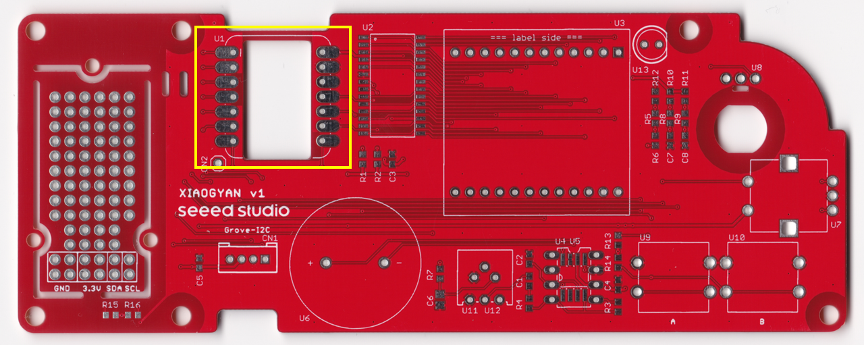
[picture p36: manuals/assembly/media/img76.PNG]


リスト⑫の分割ロングピンソケットを実装します．黄枠で囲った箇所にはんだ付けして下さい．
はんだ付け時に固定が難しい場合はマスキングテープを使いましょう！

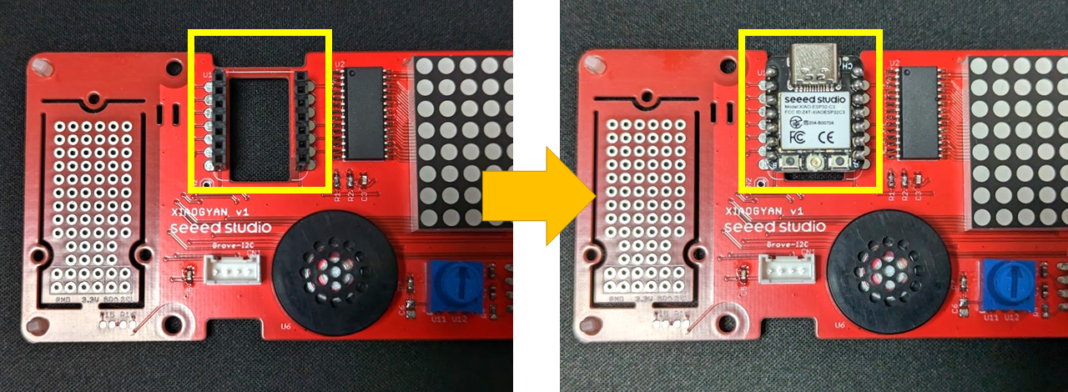
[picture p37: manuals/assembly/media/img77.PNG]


はんだ付けの終了後は，ピンソケットにマイコンを刺して下さい．

#### 2.5.6. ロータリーエンコーダーのはんだ付け

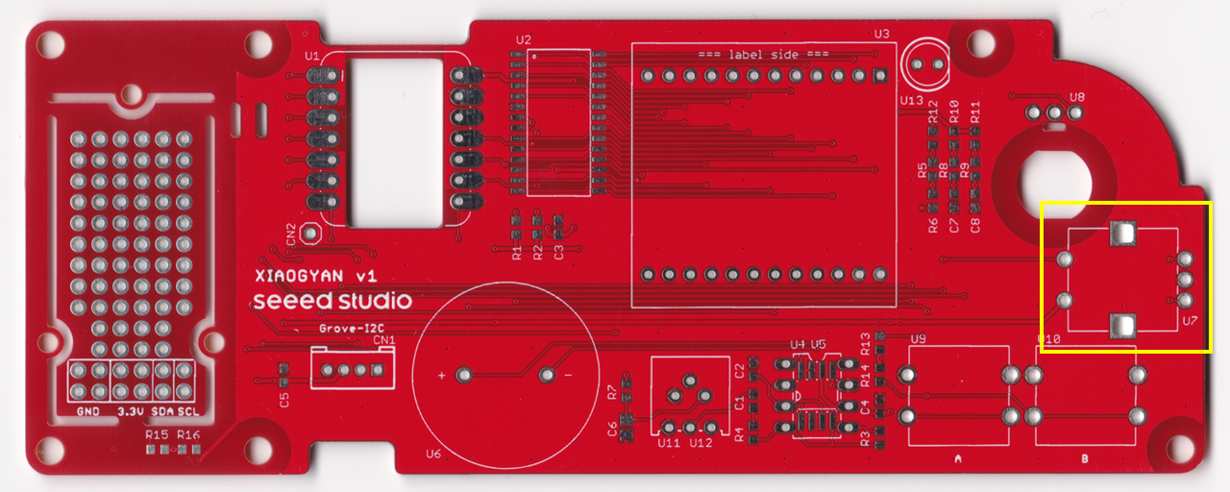
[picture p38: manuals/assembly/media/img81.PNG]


リスト⑭のロータリーエンコーダー **[U7]** を実装します．黄枠で囲った箇所にはんだ付けして下さい．

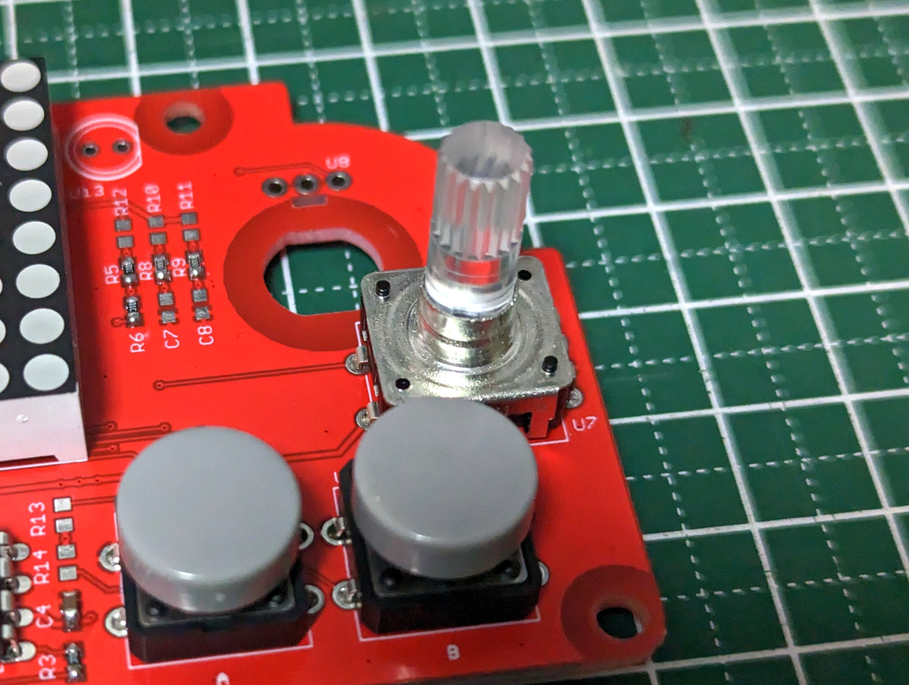
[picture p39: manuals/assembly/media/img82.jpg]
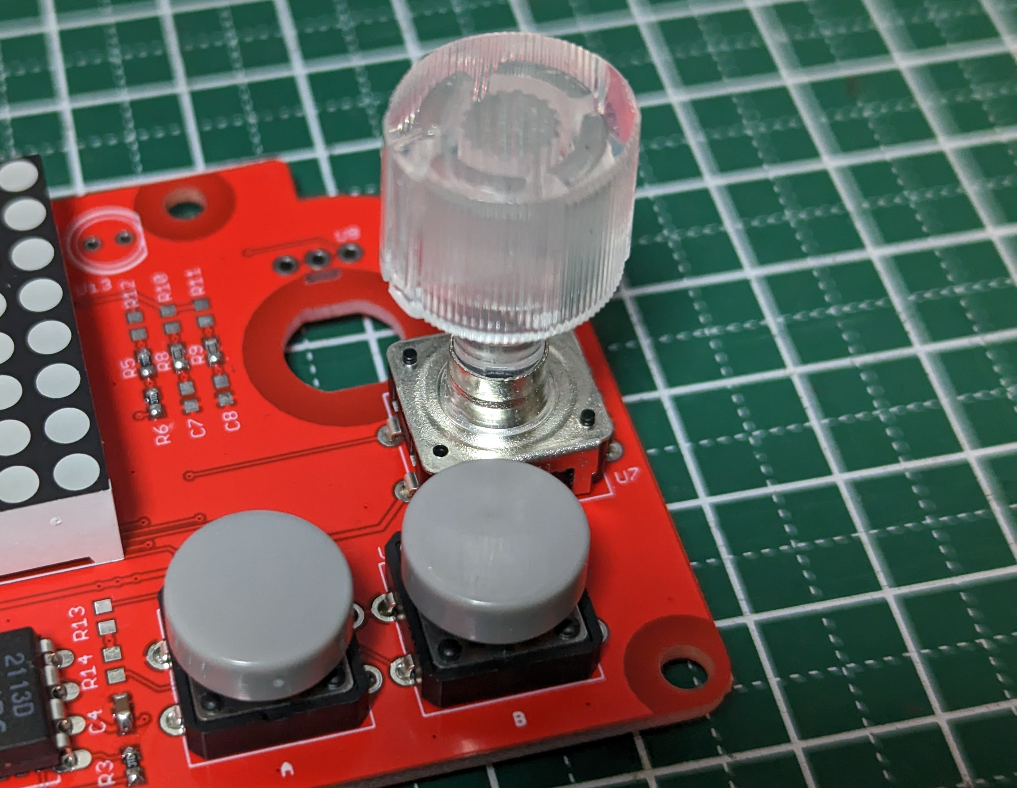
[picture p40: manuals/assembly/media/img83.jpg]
  

実際の取り付けると上記の図のようになります．
キャップは最後に取り付けると良いでしょう．(キャップは一度取り付けると，取り外しが困難である為，注意ください）

### 2.6. 足の取り付け

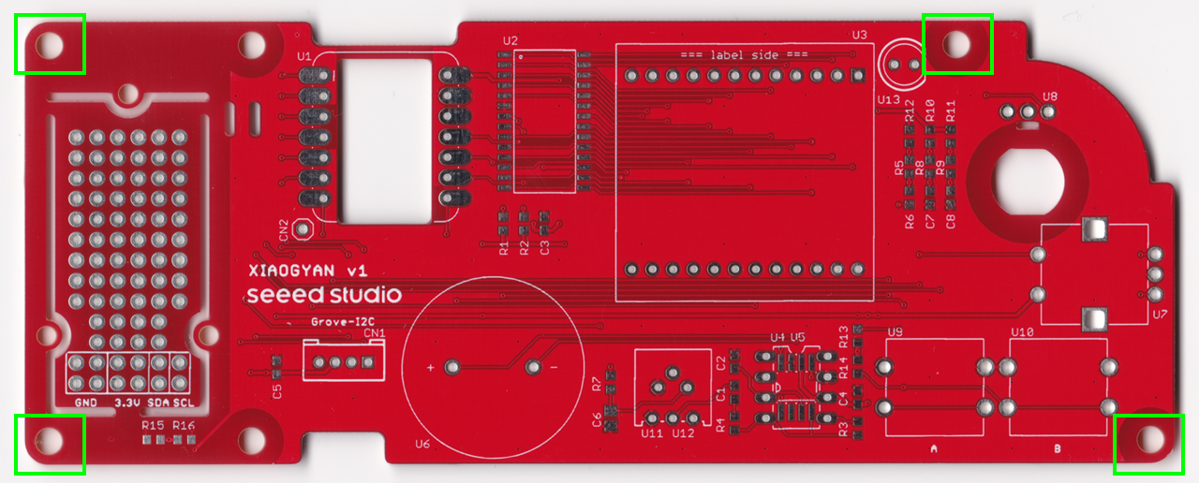
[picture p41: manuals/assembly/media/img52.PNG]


基板の裏面が不用意にショートして故障とならないよう足を取り付けましょう．
リスト⑮の基板スペーサ―を，黄枠で囲った4箇所に取り付けて下さい．

### 2.7. アンテナの固定

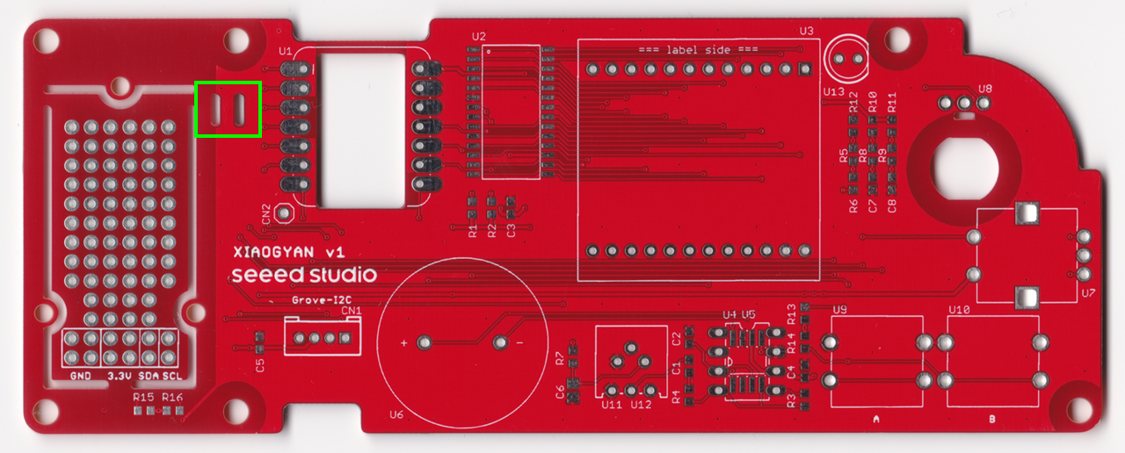
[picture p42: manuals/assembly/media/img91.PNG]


緑枠の箇所にケーブルタイを通すことで，マイコン(Seeeduino XIAO ESP32C3)のアンテナを固定する事ができます．
お好みで固定してください．



このように固定できます．

### 2.8. 基板の左部分のユニバーサル基板について



XIAOGYANにセンサ等を拡張したい時に使用できるユニバーサル基板です．
自由に活用ください．



以上で組立作業は完了です．お疲れ様でした．
再度ひとやすみをした後に，基板の動作確認を行っていきます．

## 3. チェック

### 3.1. ショートチェック

基板に火を入れる(通電する)前に，致命的なミスが無いか最低限のチェックを行います．

これより電源ラインのショートチェックを行います．
マイコンのXIAO ESP32C3には5Vおよび3.3Vの2つの電源系統が存在します．(XIAOGYANでは3.3V電源しか使用していませんが)

電源とGND間の抵抗値が低い場合，基板のどこかに短絡の可能性があり，このまま通電すると高い確率で壊れます．

そこで，テスターを抵抗レンジに設定し，測定ポイントのA～Cの抵抗値をそれぞれ計測します．



| 測定ポイント | 参考値 |
| --- | --- |
| A-B(5V-GND) | 数十kΩ以上 |
| C-B(3.3V-GND) | 数MΩ以上 |
| A-C(5V-3.3V) | 数十kΩ以上 |

測定ポイント間の抵抗値が参考値を大幅に下回る場合は，はんだ付けを見直してみて下さい．
(部品の取り付け向きや，意図しないショートなど)

## 4. 完了

以上でXIAOGYANの組立は完了です．お疲れ様でした！！１































































































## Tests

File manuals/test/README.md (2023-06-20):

# XIAOGYAN 動作確認マニュアル

## 書き込みツールesptoolをインストール

* Windows

    1. 下記リンクにある最新の`esptool-vX.X.X-win64.zip`をダウンロードして解凍してください。

        * [espressif / esptool / Releases / latest](https://github.com/espressif/esptool/releases/latest)

* Linux

    1. Python 3.7以降が必須です。バージョンを確認して、必要に応じてインストール、アップグレードしてください。

        ```
        python3 --version
        ```

    2. esptoolをインストールしてください。

        ```
        sudo pip3 install esptool
        ```

    3. esptoolが起動できるか確認してください。

        ```
        sudo esptool version
        ```

* macOS

    1. Python 3.7以降が必須です。バージョンを確認して、必要に応じてインストール、アップグレードしてください。

        ```
        python3 --version
        ```

    2. esptoolをインストールしてください。

        ```
        pip3 install esptool
        ```

    3. esptoolが起動できるか確認してください。

        ```
        esptool version
        ```

## サンプルのソフトウェアをダウンロード

サンプルのソフトウェア`HardwareTest.bin`をダウンロードしてください。

* [HardwareTest.bin](HardwareTest.bin)

## サンプルのソフトウェアを書き込む

XIAOGYANとPCをUSBで接続しておき、下記コマンドを実行してください。  
書き込みでエラーが発生したときは、XIAO ESP32C3をブートローダーモードに変更（BOOTボタンを押さえながらRESETボタンをクリック）して、下記コマンドを実行してみてください。

* Windows

    ```
    esptool write_flash 0x0 HardwareTest.bin
    ```

* Linux

    ```
    sudo esptool.py write_flash 0x0 HardwareTest.bin
    ```

* macOS

    ```
    esptool.py write_flash 0x0 HardwareTest.bin
    ```

## 動作確認

1. LEDマトリックスが、赤、緑、オレンジ色が流れるように点灯します。
2. ロータリーエンコーダの中央のLEDが点滅します。
3. ロータリーエンコーダを回すと、LEDマトリックスの点灯の速さが変わります。
4. ボタンAやボタンBを押すと、スピーカーから音が出ます。（音が出ないときは、可変抵抗（青色）を回してみてください。）

## Appendix

<details>
<summary>マージバイナリの作成</summary>

```
esptool --chip esp32c3 merge_bin -o HardwareTest.bin -ff 80m -fm dio -fs 4MB 0x0000 bootloader.bin 0x8000 partitions.bin 0xe000 boot_app0.bin 0x10000 firmware.bin
```

</details>

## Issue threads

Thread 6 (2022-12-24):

ES基板のIssue

matsujirushi, 2022-12-24:
## 動作確認

- [x] LEDマトリックス（黄色、3.3V）
- [x] LEDマトリックス（2色、3.3V）
- [x] スピーカー
- [x] エンコーダー
- [x] LED
- [x] ボタン
- [x] Grove I2C

## 気になったこと

### LEDマトリックス

- [ ] U2のパッド幅が小さい？
- [x] C1がU2に近すぎる
- [x] C1=10u(P-13161)
- [x] C1のパッドが大きすぎる
- [x] R1=100K
- [x] R2=100K

### スピーカー

- [x] C5のパッドが大きすぎる
- [x] R5=0
- [x] C6のパッドが大きすぎる
- [x] C3=DNP
- [x] VR1=10K
- [ ] パワーアンプENABLE時に破裂音がする（ https://github.com/algyan/algyan_8th/discussions/14 ）

### ロータリーエンコーダー

- [x] R8=DNP
- [x] R9=DNP
- [x] R10=0
- [x] R11=0
- [x] C7=DNP
- [x] C8=DNP

### LED

- [x] LED1=I-11580 + I-00641
- [x] R12=10K（ちょっと暗いけど、部品種類を減らすためにこれ）
- [x] リセット直後、LED1が点灯してしまう（U0TXDはリセット直後、output enabled, pull-up registor enabled）
- [x] LED1をアクティブLOWに変更（ https://github.com/algyan/algyan_8th/issues/6#issuecomment-1367884332 ）→ES2を改修

### ボタン

- [x] R13=DNP
- [x] R14=DNP
- [x] ボタンはアクティブLOWに変更（U1.D9はBOOTボタンと併用で、10Kでプルアップされている（ https://github.com/algyan/algyan_8th/issues/6#issuecomment-1366648034 ））→ES2を改修
- [ ] **ES基板のU9は実装するな！**（BOOTボタンと同時押しすると3V3-GND貫通）

### Grove I2C

- [x] C9=10u(P-13161)
- [x] 省電力向けの電源カット回路を忘れてた
  * 電源カット回路は改造して遊んでもらう事項に

### その他

- [x] JP3の下に、不要なVIA

matsujirushi, 2022-12-25:
### LEDマトリックス

**SCLK:**

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

**GRID1:**

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

tatsu1225, 2022-12-27:
ES1基板を頂きましたので，とりま手持ちの部品で可能な所まで組み立てました．
・VRの抵抗値はいくつがベターですか？-VINを0～1.15Vで変化させたいと思われましたので，とりあえず10K～100KでOKですかね？
・チップ抵抗・コンデンサの大きさは，0603/0804だと初学者には厳しそうｗ が，あえて小さいパーツで楽しんでもらうという趣向であればOKだと思いました

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

matsujirushi, 2022-12-28:
@tatsu1225

> VRの抵抗値はいくつがベターですか？

記入漏れていました。ご指摘ありがとうございます。手元は**VR1=10K**にしています。（ https://github.com/algyan/algyan_8th/issues/6#issue-1510063566 に追加しました）

> チップ抵抗・コンデンサの大きさは，0603/0804だと初学者には厳しそうｗ

入手性考えると、リード部品かチップ部品1608(mm)と思いますが、手元在庫が1608なのでw
Discussionページ立てました。
https://github.com/algyan/algyan_8th/discussions/10

tatsu1225, 2022-12-28:
あー、eagleだとinch表記で表示されるんで0603(1608(mm))すね。ふだん、チップ抵抗使わないので勘違いしとりました🙇(お恥ずかしい、pad見ればわかるやん😇

matsujirushi, 2022-12-28:
@tatsu1225
あるあるですねw（インチ<->ミリ）

あと、LEDマトリックスは2種類を動かしてみた感触では、2色のほうが良さそうなのでそちらを採用しようと思っています。（フットプリントはコスト上がらないので両方用意）

1. そちらで使っているボタンの通販コード、教えてもらえませんか？（秋月じゃない？）
2. XIAO SAMD21ってことは、もしかしてスピーカー辺りを試してくれようとしている？😍

tatsu1225, 2022-12-28:
LEDマトリックスは2色ありだと思います。弊学でも(別の先生が)実習で使っている様子を見てますが、表現の幅が広がる印象持ってます。

タクトスイッチは秋月ですが10個パックです。
通販コードは P-02561

XIAO ESP32の手持ちが尽きてしまったので、ひとまず無印XIAOを刺してみただけ。なんて言えない😇
(スピーカーは同じものが手元にない&秋月も年末年始モードなので、 P-12494 でひとまず試してみようかと。

matsujirushi, 2022-12-28:
### U1.D7はPULLDOWNできるが、U1.D9はPULLDOWNできない

* U1.D7 ... ESP32C3のPin27(U0RXD)
* U1.D9 ... ESP32C3のPin15(GPIO9) - BOOTボタンにも接続、BOOTボタンが10Kでプルアップされている。

matsujirushi, 2022-12-30:
### LED1をアクティブLOWに変更

1. LED1のアノードとカソードを反対にする（R12側がアノード）
2. R12を左パッドだけに付ける
3. R12の空き側を3V3に接続

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

matsujirushi, 2022-12-30:
### パワーアンプENABLEの効果

DISABLEにすると、2.78mA -> 167uAに下がる。（つまり、効果あり）

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

matsujirushi, 2022-12-31:
### Grove I2Cの波形

ちょっと立ち上がりが遅いのが気になるけど、Groveモジュール側の話なので、、、問題ないと判断。

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

tatsu1225, 2023-01-29:
・JP4のピンヘッダは実装＆ショートジャンパ必須
→ 3.3Vが各回路へ供給されない．どうも電流計測用のジャンパとのこと
　 ES2では削除予定(と聞きました
・以下のサンプルの動作確認ができました:-)
　－ButtonAndLed
　－Encoder
　－LedMatrixTM1640
　－Speaker2

matsujirushi, 2023-02-02:
> JP4のピンヘッダは実装＆ショートジャンパ必須

PADにして、デフォルトをショートにしました。

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

Closed 2023-03-19.

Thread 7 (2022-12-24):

お手伝い募集

matsujirushi, 2022-12-24:

610t, 2022-12-24:
ハードウエアはあまり強くありません。
XIAOシリーズは好きで、よく使っています。
XIAO ESP32C3を使うのであれば、Scratchと一緒に遊べればいいなと思っています。
よろしくお願いします。

tatsu1225, 2022-12-25:
お、最近，ESP32 XIAOに手を出してるのもある＆matsujirushi さんの仕事っぷりを間近で眺めたいので手伝いまっす！
ハード，ファーム周りが生業ですが， matsujirushi さんと比べると浅めです
手伝いやすいところでいえば，手元に電子パーツ類や実装の為の環境はそこそこあるので，検証用の回路試作やら動作確認用ファームなど

motojinc25, 2022-12-26:
IoT Edge系があれば、どうですか？
よろしくお願いいたします。

atkogure, 2022-12-27:
企画＆設計の全体像・方向性に関する意見、電子部品の選定や入手性などなど、私でお役に立てそうな場面があれば、何なりとお声かけくださいませ。

matsujirushi, 2022-12-28:
https://github.com/algyan/algyan_8th/issues/7#issuecomment-1364596872
@610t さん、ご連絡ありがとうございます！
Scratchと連動いいですね！（わたし自身、やったことない．．．）
現時点は、機能面を見ていただいて、Discussionにご意見いただけると嬉しいです。（○○はいらないとか、○○がほしいとか）
ハード周りが落ち着いたら、サンプル基板を送ろうと思います。しばしお待ちを。

https://github.com/algyan/algyan_8th/issues/7#issuecomment-1364651277
@tatsu1225 さん、ご連絡ありがとうございます！
マニュアル作りとアプリケーションあたりで手伝ってもらいたいです。
動作確認も手伝っていただけるようなので、、、ES基板を送りました。気づいた点があれば https://github.com/algyan/algyan_8th/issues/6 にコメント願います。

https://github.com/algyan/algyan_8th/issues/7#issuecomment-1364863945
@motojinc25 さん、ご連絡ありがとうございます！
クラウド側は、、、まだイメージできていない状況です（汗）
IoT Edge絡めて、どんな使い方ができそうか考えてもらえないでしょうか？（可能なら、Discussionに投稿ください。）

https://github.com/algyan/algyan_8th/issues/7#issuecomment-1365691205
@atkogure さん、ご連絡ありがとうございます！
パーツセットや完成品の販売を確立してほしいです！！！
（Seeedでやれよと思うところはありますが、なかなかに難しいのでお手伝いいただきたく）

y-ohe, 2022-12-28:
得意なことを考えているうちに出遅れてしまいました。
一応、回路設計、基板設計から簡単なソフト実装や3Dプリンタでのケース設計まで一通り何でもこなせるつもりです(クラウドまわりはあまり強くないですが、なんとなくぐらいはできます)。
EAGLEの部品ライブラリ整備なんて所もお手伝いできます。
何かお手伝いすることがあれば、割り振って下さい。

matsujirushi, 2022-12-28:
https://github.com/algyan/algyan_8th/issues/7#issuecomment-1366556129
@y-ohe さん、ご連絡ありがとうございます！
早速で恐縮なのですが、、、Seeed Studio XIAO ESP32C3の、裏のパッド付きのEAGLEライブラリが欲しいです！！（スタンパーの信号は、表面実装とスルーホールの両方実装できる感じで）

TakSan0, 2023-01-01:
見た時、ウルトラビジー状態だったので、後で回答と思っててすっかり出遅れました。
組み込み系 SE なので、ハード周りのソフトなら手伝えますかね。
時期によっては忙しいかもですが…
ちなみに、ANGYAN５周年及び６周年基板で、はんだ付けもくもく会用のハードチェックソフトとか作った実績あります。

KentaMatsumoto-2021, 2023-01-03:
nRF52840 なら手伝っても良いよ。

matsujirushi, 2023-01-07:
https://github.com/algyan/algyan_8th/issues/7#issuecomment-1368525541
@TakSan0 さん、ご連絡ありがとうございます！
ES2基板が出来上がったタイミングに、ES2基板+Seeed Studio XIAO nRF52840の組み合わせで一通り動作するか確認してほしいです！（2月中旬頃の見込み）
出来そうでしょうか？

https://github.com/algyan/algyan_8th/issues/7#issuecomment-1369755449
@KentaMatsumoto-2021 さん、ご連絡ありがとうございます！
nRF52840はちょっと先になりますが、そのときに相談させていただきます。

TakSan0, 2023-01-09:
@matsujirushi さん、了解です。
２月中くらいまで別件で忙しく、微妙にそれが伸びる気もしますが、その後３月にかけては大丈夫かと思います。
XIAOシリーズは、AMD21、nRF52840、 ESP32C3 いずれも持っていますが、積んでいる（放置）状態になっているので、それまでに、ちょっといじってみようかなと思います。

matsujirushi, 2023-03-06:
ES3基板で、ようやく改変が収まりました。
https://github.com/algyan/XIAOGYAN/blob/main/hardware/algyan_8th.es3.pdf

@610t @tatsu1225 @y-ohe @TakSan0
試してもらいたいので、ES3基板を郵送しようと思います。
matsujirushi@live.jp まで、送付先を送っていただけませんか？

matsujirushi, 2023-03-10:
@610t @tatsu1225 @y-ohe @TakSan0
配布基板の製造着手を4/3に決めました。
https://github.com/algyan/XIAOGYAN#%E3%82%BF%E3%82%A4%E3%83%A0%E3%83%A9%E3%82%A4%E3%83%B3

そのため、**ES3基板のフィードバック受付期限が3/26**です。
よろしくお願いします。

TakSan0, 2023-03-15:
ハード大体組みあがったので試してみようかと意気込んでましたが、
githubにある ALGYAN 8周年基板用のデモソフト  [xiaogyan_examples](https://github.com/algyan/xiaogyan_examples) は XIAO ESP32C3 向けなのですね。アナログ出力のところで ledc とか ESP32 にしかないライブラリを使っていますし。

なので、XIAO nRF52840 で試すとそこでエラーとなり、そこをコメントアウトしても、他にライブラリ側で大量にエラーが出てコンパイル通りませんでした。
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
まぁ、コンパイルスイッチもないので ESP32C3 専用にしか整備できていないんだと思っていますが、
一つ一つ解決していく必要ありそうです。

長い闘いになりそうです・・・

とりま、実績のありそうな XIAO ESP32C3 でハードが問題無いかだけ動かしてみようかなと、
コンパイルかけてみるとなんか D10 が無いとか？のピン定義でそんなエラーを見たことないのでちょっとよくわかりませんが…

こちらも、はまりそうな予感です・・・
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

以上、初見の状況でした。いきなりの地雷でつまづきつつあります。

TakSan0, 2023-03-15:
> コンパイルかけてみるとなんか D10 が無いとか？のピン定義でそんなエラーを見たことないのでちょっとよくわかりませんが…

単に D10 -> 10 の様に数値にするだけでコンパイルは通りました。
とりあえず、MATRIX LED が付くのは確認できました。
なぜか音の出力とスイッチ入力がまだ確認できません。部品付け忘れか何かか、調べてみます。

matsujirushi, 2023-03-16:
@TakSan0
お試しありがとうございます！

issueを2つ起票しました。
不足があれば、issueを起票願います。

matsujirushi, 2023-03-16:
@TakSan0
以下のissueをご確認願います。
#32 #33

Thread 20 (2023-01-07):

ES->ES2基板のリワーク

matsujirushi, 2023-01-07:
1. [U8とU9をアクティブLOWに変更](https://github.com/algyan/algyan_8th/issues/6#issuecomment-1366648034)
2. [LED1をアクティブLOWに変更](https://github.com/algyan/algyan_8th/issues/6#issuecomment-1367884332)
3. U1のD3とD6を入れ替え
4. U1のD7とD9を入れ替え

Closed 2023-03-19.

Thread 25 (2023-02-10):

[ES2] 回路図のU5-1、Pin2接続が間違っている

matsujirushi, 2023-02-10:
### Discussed in https://github.com/algyan/algyan_8th/discussions/24

<div type='discussions-op-text'>

<sup>Originally posted by **y-ohe** February 10, 2023</sup>
es2基板のスピーカー用オペアンプ部の回路図ですが、U5-1のピン4とピン2がショートしています。
誤記じゃないでしょうか？
基板のパターンとガーバーデータでは繋がっていないので、大丈夫だと思われます。
(DRCチェックでAirWireのエラーが出ます。)
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
</div>

matsujirushi, 2023-02-10:
### 調査

**ES2 EAGLE .schファイル:**

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

**ES2 EAGLE .brdファイル:**

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

**ES1 EAGLE .schファイル:**

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

### 結論

* ES2 .schのU5-1、Pin2接続が間違い。（余分）
* ES2 PCBへの影響は無し。（ES2 .brdのPin2接続が未結線なので。）

Closed 2023-02-10.

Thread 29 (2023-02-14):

[ES2] プログラム書き込み時にスピーカーから雑音

matsujirushi, 2023-02-14:
* プログラム書き込み時にD6/A6/TXピンを使用している
* D6/A6/TXピンはSPEAKER-ENABLEに割り当て
* SPEAKER-ENABLEがHIGH時に破裂音( #14 )

ダサい。なんとかしたい。

matsujirushi, 2023-02-15:
D6/A6/TXピンをLEDに変更する。（つまり、ESの配線に戻す。）

**ES:**
* D3/A3 ... SPEAKER-ENABLE
* D6/A6/TX ... ENC-LED or LED1

**ES2:**
* D3/A3 ... LED or AnalogIn
* D6/A6/TX ... SPEAKER-ENABLE

**変更後:**
* D3/A3 ... SPEAKER-ENABLE or AnalogIn
* D6/A6/TX ... LED

（SPEAKER-ENABLEが常設にならないが、、、代案が無いのでこれで。）

matsujirushi, 2023-02-16:
ES3に反映した。

Closed 2023-02-16.

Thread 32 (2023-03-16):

デモソフトxiaogyan_examplesが対象にしているXIAOがどれか分からない

matsujirushi, 2023-03-16:
> [元記事](https://github.com/algyan/XIAOGYAN/issues/7#issuecomment-1470078660)

githubにある ALGYAN 8周年基板用のデモソフト [xiaogyan_examples](https://github.com/algyan/xiaogyan_examples) は XIAO ESP32C3 向けなのですね。アナログ出力のところで ledc とか ESP32 にしかないライブラリを使っていますし。

matsujirushi, 2023-03-16:
現状、ハードウェア、ソフトウェアとも、マイコンは**Seeed Studio XIAO ESP32C3**で動作確認しています。
他のXIAOによる確認は、

* Seeed Studio XIAO SAMD21 ... ESの頃に、アナログ出力を確認したのみ。ES3は未確認。
* Seeed Studio XIAO RP2040 ... 未確認。
* Seeed Studio XIAO nRF52840 ... 基板設計時に机上で考慮。実機では未確認。

です。

当面、わたしはSeeed Studio XIAO ESP32C3についてフォローしようと考えています。
他のXIAOも出来れば対応したいので、issueやpull requestをお願いします。

TakSan0, 2023-03-16:
了解しました。
ESP32C3版のサンプルプログラムがどのような動きをするかの確認が出来次第、他のシリーズへのポーティング試してみます。
まずは nRF52840 から。コンパイルエラー対処からボチボチと。

Seeed Studio XIAO RP2040 は持っていませんが、 SAMD21 はどこかにあったはずですね。探せば出てくるかも。余裕あれば。

TakSan0, 2023-03-16:
XIAO_nRF52840 で使う際の問題点２か所特定できました。

### 1. 線形代数ライブラリ [Eigen](http://eigen.tuxfamily.org/index.php?title=Main_Page) がXIAO nRF52840 に未対応
　　D0 ～ D3 を使用している箇所でコンパイルエラーが多数出ていました。
　　これらはピン定義なので XIAO nRF52840 では数値で定義しているのに、ライブラリ側は '&' をつけて数値の入った変数の
　　アドレスを参照する造りとなっていたからでした。
　　ライブラリの git 更新差分で似たようなエラーを修正した差分があったのでそれをまねることで治りました。
　　具体的には
`<Library Path>/ArduinoEigen/ArduinoEigenCommon.h`
の最後の方に、

```
#ifdef D0
#undef D0
static constexpr size_t D0 {0};
#endif
#ifdef D1
#undef D1
static constexpr size_t D1 {1};
#endif
#ifdef D2
#undef D2
static constexpr size_t D2 {2};
#endif
#ifdef D3
#undef D3
static constexpr size_t D3 {3};
#endif

```
を追加しました。
但し、ライブラリ内のことなので、皆がコンパイルできるようにする為には、
ライブラリ作者に pullリク 出すか、正式に対応依頼しないといけないと思います。　　

### 2. Speaker.cpp のサイン波出力部　
ESP32 系 では Tone() 関数が使えないのが理由で、ledcWriteTone() 関数を使って出力しているかと思いますが、
逆に ESP32 ではない場合は、Arduino標準の Tone() の方が使えるはずと思ってやってみたら、ちゃんと出力できました。
▽こんな感じで修正してみました。

```
void Speaker::begin()
{
    pinMode(speakerEnablePin_, OUTPUT);
    digitalWrite(speakerEnablePin_, HIGH);
#if defined(ARDUINO_XIAO_ESP32C3)
    ledcAttachPin(speakerPin_, ledControlChannel_);
#endif
}

void Speaker::setPowerSupply(bool on)
{
    digitalWrite(speakerEnablePin_, on ? LOW : HIGH);
}

void Speaker::setTone(int frequency)
{
#if defined(ARDUINO_XIAO_ESP32C3)
    ledcWriteTone(ledControlChannel_, frequency);
#elif defined(ARDUINO_Seeed_XIAO_nRF52840) || defined(ARDUINO_Seeed_XIAO_nRF52840_Sense)
    if (frequency) tone(speakerPin_, frequency);
    else noTone(speakerPin_);
#endif
}

```

一応両方できるようにコンパイルスイッチで分けてみてます。

本来 pullリク出さないといけないのですが、大昔にやったっきりしばらく pullリク出していないので、
ちょっとリハビリ必要な感じです。明日できたらやってみます。
特に 1. の方の pullリクは、ちょっとハードル高いですね ^^

[取り急ぎのご報告まで。[](url)](url)

matsujirushi, 2023-03-16:
@TakSan0
ご確認ありがとうございます。
Seeed Studio XIAO nRF52840対応のDiscussionを起票して転記しました。 #34

TakSan0, 2023-03-17:
XIAO AMD21 ボードはまだ発掘できていないのですが、先ずはコンパイル通るかを確認してみました。
ボード定義 "Seeeduino XIAO" を選択して試しています。

こちらは、ピンの定義自体が無いらしく Xiaogyan 辺りで D0～D10 や A0 ～ A10 の使用箇所でエラーが出るのと、
Eigen ライブラリコンパイル時に、別のエラーが多数出ますね。

#35
でおっしゃっていた 「案3. ArduinoEigenの使用をやめる。」　も検討しないといけないかもですね。
個々にエラーの詳細は確認できていませんが、こんな感じです。

別の issue 立てるべきかなとは思いますが、取り急ぎの報告です。

```
d:\DEVELOP\XXXXXXXXX\Arduino\libraries\ArduinoEigen-master/ArduinoEigen/Eigen/src/SparseLU/SparseLU_gemm_kernel.h: In function 'void Eigen::internal::sparselu_gemm(Eigen::Index, Eigen::Index, Eigen::Index, const Scalar*, Eigen::Index, const Scalar*, Eigen::Index, Scalar*, Eigen::Index)':
d:\DEVELOP\XXXXXXXXX\Arduino\libraries\ArduinoEigen-master/ArduinoEigen/Eigen/src/SparseLU/SparseLU_gemm_kernel.h:31:3: error: expected primary-expression before 'enum'
   enum {
   ^~~~
d:\DEVELOP\XXXXXXXXX\Arduino\libraries\ArduinoEigen-master/ArduinoEigen/Eigen/src/SparseLU/SparseLU_gemm_kernel.h:40:20: error: 'RK' was not declared in this scope
   Index d_end = (d/RK)*RK;    // number of columns of A (rows of B) suitable for full register blocking
                    ^~
d:\DEVELOP\XXXXXXXXX\Arduino\libraries\ArduinoEigen-master/ArduinoEigen/Eigen/src/SparseLU/SparseLU_gemm_kernel.h:41:20: error: 'RN' was not declared in this scope
   Index n_end = (n/RN)*RN;    // number of columns of B-C suitable for processing RN columns at once
                    ^~
d:\DEVELOP\XXXXXXXXX\Arduino\libraries\ArduinoEigen-master/ArduinoEigen/Eigen/src/SparseLU/SparseLU_gemm_kernel.h:41:20: note: suggested alternative: '_N'
   Index n_end = (n/RN)*RN;    // number of columns of B-C suitable for processing RN columns at once
                    ^~
                    _N
d:\DEVELOP\XXXXXXXXX\Arduino\libraries\ArduinoEigen-master/ArduinoEigen/Eigen/src/SparseLU/SparseLU_gemm_kernel.h:58:30: error: 'BM' was not declared in this scope
   for(Index ib=i0; ib<m; ib+=BM)
                              ^~
d:\DEVELOP\XXXXXXXXX\Arduino\libraries\ArduinoEigen-master/ArduinoEigen/Eigen/src/SparseLU/SparseLU_gemm_kernel.h:58:30: note: suggested alternative: 'B'
   for(Index ib=i0; ib<m; ib+=BM)
                              ^~
                              B
d:\DEVELOP\XXXXXXXXX\Arduino\libraries\ArduinoEigen-master/ArduinoEigen/Eigen/src/SparseLU/SparseLU_gemm_kernel.h:61:37: error: 'SM' was not declared in this scope
     Index actual_b_end1 = (actual_b/SM)*SM;                   // actual number of rows suitable for peeling
                                     ^~
d:\DEVELOP\XXXXXXXXX\Arduino\libraries\ArduinoEigen-master/ArduinoEigen/Eigen/src/SparseLU/SparseLU_gemm_kernel.h:61:37: note: suggested alternative: 'SS'
     Index actual_b_end1 = (actual_b/SM)*SM;                   // actual number of rows suitable for peeling
                                     ^~
                                     SS
In file included from d:\DEVELOP\XXXXXXXXX\Arduino\libraries\ArduinoEigen-master/ArduinoEigen/Eigen/SparseLU:28:0,
                 from d:\DEVELOP\XXXXXXXXX\Arduino\libraries\ArduinoEigen-master/ArduinoEigen/Eigen/Sparse:29,
                 from d:\DEVELOP\XXXXXXXXX\Arduino\libraries\ArduinoEigen-master/ArduinoEigen/Eigen/Eigen:2,
                 from d:\DEVELOP\XXXXXXXXX\Arduino\libraries\ArduinoEigen-master/ArduinoEigen.h:10,
                 from D:\DEVELOP\XXXXXXXXX\Arduino\ESP32\ALGYAN_Board\ALGYAN8_ES3_Test\LedMatrix.hpp:11,
                 from D:\DEVELOP\XXXXXXXXX\Arduino\ESP32\ALGYAN_Board\ALGYAN8_ES3_Test\LedMatrixAGFX.cpp:11:
d:\DEVELOP\XXXXXXXXX\Arduino\libraries\ArduinoEigen-master/ArduinoEigen/Eigen/src/SparseLU/SparseLU_gemm_kernel.h: In function 'void Eigen::internal::sparselu_gemm(Eigen::Index, Eigen::Index, Eigen::Index, const Scalar*, Eigen::Index, const Scalar*, Eigen::Index, Scalar*, Eigen::Index)':
d:\DEVELOP\XXXXXXXXX\Arduino\libraries\ArduinoEigen-master/ArduinoEigen/Eigen/src/SparseLU/SparseLU_gemm_kernel.h:31:3: error: expected primary-expression before 'enum'
   enum {
   ^~~~
d:\DEVELOP\XXXXXXXXX\Arduino\libraries\ArduinoEigen-master/ArduinoEigen/Eigen/src/SparseLU/SparseLU_gemm_kernel.h:40:20: error: 'RK' was not declared in this scope
   Index d_end = (d/RK)*RK;    // number of columns of A (rows of B) suitable for full register blocking
                    ^~
d:\DEVELOP\XXXXXXXXX\Arduino\libraries\ArduinoEigen-master/ArduinoEigen/Eigen/src/SparseLU/SparseLU_gemm_kernel.h:41:20: error: 'RN' was not declared in this scope
   Index n_end = (n/RN)*RN;    // number of columns of B-C suitable for processing RN columns at once
                    ^~
d:\DEVELOP\XXXXXXXXX\Arduino\libraries\ArduinoEigen-master/ArduinoEigen/Eigen/src/SparseLU/SparseLU_gemm_kernel.h:41:20: note: suggested alternative: '_N'
   Index n_end = (n/RN)*RN;    // number of columns of B-C suitable for processing RN columns at once
                    ^~
                    _N
d:\DEVELOP\XXXXXXXXX\Arduino\libraries\ArduinoEigen-master/ArduinoEigen/Eigen/src/SparseLU/SparseLU_gemm_kernel.h:58:30: error: 'BM' was not declared in this scope
   for(Index ib=i0; ib<m; ib+=BM)
                              ^~
In file included from d:\DEVELOP\XXXXXXXXX\Arduino\libraries\ArduinoEigen-master/ArduinoEigen/Eigen/SparseLU:28:0,
                 from d:\DEVELOP\XXXXXXXXX\Arduino\libraries\ArduinoEigen-master/ArduinoEigen/Eigen/Sparse:29,
                 from d:\DEVELOP\XXXXXXXXX\Arduino\libraries\ArduinoEigen-master/ArduinoEigen/Eigen/Eigen:2,
                 from d:\DEVELOP\XXXXXXXXX\Arduino\libraries\ArduinoEigen-master/ArduinoEigen.h:10,
                 from D:\DEVELOP\XXXXXXXXX\Arduino\ESP32\ALGYAN_Board\ALGYAN8_ES3_Test\LedMatrix.hpp:11,
                 from D:\DEVELOP\XXXXXXXXX\Arduino\ESP32\ALGYAN_Board\ALGYAN8_ES3_Test\Xiaogyan.hpp:14,
                 from D:\DEVELOP\XXXXXXXXX\Arduino\ESP32\ALGYAN_Board\ALGYAN8_ES3_Test\ALGYAN8_ES3_Test.ino:12:
d:\DEVELOP\XXXXXXXXX\Arduino\libraries\ArduinoEigen-master/ArduinoEigen/Eigen/src/SparseLU/SparseLU_gemm_kernel.h: In function 'void Eigen::internal::sparselu_gemm(Eigen::Index, Eigen::Index, Eigen::Index, const Scalar*, Eigen::Index, const Scalar*, Eigen::Index, Scalar*, Eigen::Index)':
d:\DEVELOP\XXXXXXXXX\Arduino\libraries\ArduinoEigen-master/ArduinoEigen/Eigen/src/SparseLU/SparseLU_gemm_kernel.h:31:3: error: expected primary-expression before 'enum'
   enum {
   ^~~~
d:\DEVELOP\XXXXXXXXX\Arduino\libraries\ArduinoEigen-master/ArduinoEigen/Eigen/src/SparseLU/SparseLU_gemm_kernel.h:40:20: error: 'RK' was not declared in this scope
   Index d_end = (d/RK)*RK;    // number of columns of A (rows of B) suitable for full register blocking
                    ^~
d:\DEVELOP\XXXXXXXXX\Arduino\libraries\ArduinoEigen-master/ArduinoEigen/Eigen/src/SparseLU/SparseLU_gemm_kernel.h:58:30: note: suggested alternative: 'B'
   for(Index ib=i0; ib<m; ib+=BM)
                              ^~
                              B
d:\DEVELOP\XXXXXXXXX\Arduino\libraries\ArduinoEigen-master/ArduinoEigen/Eigen/src/SparseLU/SparseLU_gemm_kernel.h:61:37: error: 'SM' was not declared in this scope
     Index actual_b_end1 = (actual_b/SM)*SM;                   // actual number of rows suitable for peeling
                                     ^~
d:\DEVELOP\XXXXXXXXX\Arduino\libraries\ArduinoEigen-master/ArduinoEigen/Eigen/src/SparseLU/SparseLU_gemm_kernel.h:41:20: error: 'RN' was not declared in this scope
   Index n_end = (n/RN)*RN;    // number of columns of B-C suitable for processing RN columns at once
                    ^~
d:\DEVELOP\XXXXXXXXX\Arduino\libraries\ArduinoEigen-master/ArduinoEigen/Eigen/src/SparseLU/SparseLU_gemm_kernel.h:61:37: note: suggested alternative: 'SS'
     Index actual_b_end1 = (actual_b/SM)*SM;                   // actual number of rows suitable for peeling
                                     ^~
                                     SS
d:\DEVELOP\XXXXXXXXX\Arduino\libraries\ArduinoEigen-master/ArduinoEigen/Eigen/src/SparseLU/SparseLU_gemm_kernel.h:41:20: note: suggested alternative: '_N'
   Index n_end = (n/RN)*RN;    // number of columns of B-C suitable for processing RN columns at once
                    ^~
                    _N
d:\DEVELOP\XXXXXXXXX\Arduino\libraries\ArduinoEigen-master/ArduinoEigen/Eigen/src/SparseLU/SparseLU_gemm_kernel.h:58:30: error: 'BM' was not declared in this scope
   for(Index ib=i0; ib<m; ib+=BM)
                              ^~
In file included from d:\DEVELOP\XXXXXXXXX\Arduino\libraries\ArduinoEigen-master/ArduinoEigen/Eigen/SparseLU:28:0,
                 from d:\DEVELOP\XXXXXXXXX\Arduino\libraries\ArduinoEigen-master/ArduinoEigen/Eigen/Sparse:29,
                 from d:\DEVELOP\XXXXXXXXX\Arduino\libraries\ArduinoEigen-master/ArduinoEigen/Eigen/Eigen:2,
                 from d:\DEVELOP\XXXXXXXXX\Arduino\libraries\ArduinoEigen-master/ArduinoEigen.h:10,
                 from D:\DEVELOP\XXXXXXXXX\Arduino\ESP32\ALGYAN_Board\ALGYAN8_ES3_Test\LedMatrix.hpp:11,
                 from D:\DEVELOP\XXXXXXXXX\Arduino\ESP32\ALGYAN_Board\ALGYAN8_ES3_Test\LedMatrix.cpp:10:
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
matsujirushi, 2023-03-17:
> こちらは、ピンの定義自体が無いらしく Xiaogyan 辺りで D0～D10 や A0 ～ A10 の使用箇所でエラーが出るのと、
> Eigen ライブラリコンパイル時に、別のエラーが多数出ますね。

ご確認ありがとうございます。
このissueとは違うので、新たにissueを起票願います。（1つのissueに混ぜて書いてあると、対応漏れしてしまうため）

> 取り急ぎの報告です。

こちらはissueではないので、、、Discussionに起票願います。

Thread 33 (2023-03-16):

xiaogyan_examplesでerror: 'D10' was not declared in this scope

matsujirushi, 2023-03-16:
> [元記事](https://github.com/algyan/XIAOGYAN/issues/7#issuecomment-1470078660)

とりま、実績のありそうな XIAO ESP32C3 でハードが問題無いかだけ動かしてみようかなと、
コンパイルかけてみるとなんか D10 が無いとか？のピン定義でそんなエラーを見たことないのでちょっとよくわかりませんが…

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

matsujirushi, 2023-03-16:
ボードの選択が間違っているように見えます。
`XIAO_ESP32C3`を選んで、再度確認願います。

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

### 参考リンク

* [Getting Started with Seeed Studio XIAO ESP32C3 - Software setup](https://wiki.seeedstudio.com/XIAO_ESP32C3_Getting_Started#software-setup)

TakSan0, 2023-03-16:
確かにボード設定ミスっていますね。
ちゃんとソースを元の状態に戻して、正しいボード設定ではコンパイル通ることが確認できました。
すみません、"参考リンク"に記載いただいた手順、ちゃんと見るべきでした。
ありがとうございます。

おかげで ESP32C3 版では、どのような動きになるかは確認できました。
一通り、マトリックスの動作、スピーカーからのTone再生、ボタン2つ組み合わせで３種類の音程が出る事、ジョグダイヤルで点滅速度が変わること、ジョグダイヤル内の LED が光る事が全て確認できました。
ありがとうございます。

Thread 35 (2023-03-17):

variant.h:46:16: error: lvalue required as unary '&' operand

matsujirushi, 2023-03-17:
> [元記事](https://github.com/algyan/XIAOGYAN/discussions/34)

ターゲットボードを`Seeed Studio XIAO nRF52840`でコンパイルすると、ArduinoEigenの部分でエラーが発生する。

```
C:\Users\XXXXXXXXXX\AppData\Local\Arduino15\packages\Seeeduino\hardware\nrf52\1.1.1\variants\Seeed_XIAO_nRF52840/variant.h:46:16: error: lvalue required as unary '&' operand
   46 | #define D0 (0ul)
      |                ^
d:\DEVELOP\XXXXXXXXX\Arduino\libraries\ArduinoEigen-master/ArduinoEigen/Eigen/src/Core/products/GeneralBlockPanelKernel.h:1270:73: note: in expansion of macro 'D0'
 1270 |           peeled_kc_onestep(1, blA, blB, traits, &A1, &rhs_panel, &T0, &D0, &D1, &D2, &D3);
      |                                                                         ^~
C:\Users\XXXXXXXXXX\AppData\Local\Arduino15\packages\Seeeduino\hardware\nrf52\1.1.1\variants\Seeed_XIAO_nRF52840/variant.h:47:16: error: lvalue required as unary '&' operand
   47 | #define D1 (1ul)
      |                ^
d:\DEVELOP\XXXXXXXXX\Arduino\libraries\ArduinoEigen-master/ArduinoEigen/Eigen/src/Core/products/GeneralBlockPanelKernel.h:1270:78: note: in expansion of macro 'D1'
 1270 |           peeled_kc_onestep(1, blA, blB, traits, &A1, &rhs_panel, &T0, &D0, &D1, &D2, &D3);
      |                                                                              ^~
C:\Users\XXXXXXXXXX\AppData\Local\Arduino15\packages\Seeeduino\hardware\nrf52\1.1.1\variants\Seeed_XIAO_nRF52840/variant.h:48:16: error: lvalue required as unary '&' operand
   48 | #define D2 (2ul)
      |                ^
d:\DEVELOP\XXXXXXXXX\Arduino\libraries\ArduinoEigen-master/ArduinoEigen/Eigen/src/Core/products/GeneralBlockPanelKernel.h:1270:83: note: in expansion of macro 'D2'
 1270 |           peeled_kc_onestep(1, blA, blB, traits, &A1, &rhs_panel, &T0, &D0, &D1, &D2, &D3);
      |                                                                                   ^~
C:\Users\XXXXXXXXXX\AppData\Local\Arduino15\packages\Seeeduino\hardware\nrf52\1.1.1\variants\Seeed_XIAO_nRF52840/variant.h:49:16: error: lvalue required as unary '&' operand
   49 | #define D3 (3ul)
      |                ^
d:\DEVELOP\XXXXXXXXX\Arduino\libraries\ArduinoEigen-master/ArduinoEigen/Eigen/src/Core/products/GeneralBlockPanelKernel.h:1270:88: note: in expansion of macro 'D3'
 1270 |           peeled_kc_onestep(1, blA, blB, traits, &A1, &rhs_panel, &T0, &D0, &D1, &D2, &D3);
      |                                                                                        ^~
C:\Users\XXXXXXXXXX\AppData\Local\Arduino15\packages\Seeeduino\hardware\nrf52\1.1.1\variants\Seeed_XIAO_nRF52840/variant.h:46:16: error: lvalue required as unary '&' operand
   46 | #define D0 (0ul)
      |                ^
d:\DEVELOP\XXXXXXXXX\Arduino\libraries\ArduinoEigen-master/ArduinoEigen/Eigen/src/Core/products/GeneralBlockPanelKernel.h:1272:73: note: in expansion of macro 'D0'
 1272 |           peeled_kc_onestep(3, blA, blB, traits, &A1, &rhs_panel, &T0, &D0, &D1, &D2, &D3);
      |                                                                         ^~
C:\Users\XXXXXXXXXX\AppData\Local\Arduino15\packages\Seeeduino\hardware\nrf52\1.1.1\variants\Seeed_XIAO_nRF52840/variant.h:47:16: error: lvalue required as unary '&' operand
   47 | #define D1 (1ul)
      |                ^
d:\DEVELOP\XXXXXXXXX\Arduino\libraries\ArduinoEigen-master/ArduinoEigen/Eigen/src/Core/products/GeneralBlockPanelKernel.h:1272:78: note: in expansion of macro 'D1'
 1272 |           peeled_kc_onestep(3, blA, blB, traits, &A1, &rhs_panel, &T0, &D0, &D1, &D2, &D3);
      |                                                                              ^~
C:\Users\XXXXXXXXXX\AppData\Local\Arduino15\packages\Seeeduino\hardware\nrf52\1.1.1\variants\Seeed_XIAO_nRF52840/variant.h:48:16: error: lvalue required as unary '&' operand
   48 | #define D2 (2ul)
      |                ^
d:\DEVELOP\XXXXXXXXX\Arduino\libraries\ArduinoEigen-master/ArduinoEigen/Eigen/src/Core/products/GeneralBlockPanelKernel.h:1272:83: note: in expansion of macro 'D2'
 1272 |           peeled_kc_onestep(3, blA, blB, traits, &A1, &rhs_panel, &T0, &D0, &D1, &D2, &D3);
      |                                                                                   ^~
C:\Users\XXXXXXXXXX\AppData\Local\Arduino15\packages\Seeeduino\hardware\nrf52\1.1.1\variants\Seeed_XIAO_nRF52840/variant.h:49:16: error: lvalue required as unary '&' operand
   49 | #define D3 (3ul)
      |                ^
d:\DEVELOP\XXXXXXXXX\Arduino\libraries\ArduinoEigen-master/ArduinoEigen/Eigen/src/Core/products/GeneralBlockPanelKernel.h:1272:88: note: in expansion of macro 'D3'
 1272 |           peeled_kc_onestep(3, blA, blB, traits, &A1, &rhs_panel, &T0, &D0, &D1, &D2, &D3);
      |                                                                                        ^~
```

matsujirushi, 2023-03-17:
**Adafruit_nRF52_Arduino**で`#define`している`D0`, `D1`, `D2`, `D3`が、**ArduinoEigen**の内部に影響している。

https://github.com/Seeed-Studio/Adafruit_nRF52_Arduino/blob/ccd02aa73be1a9a08fb3cbc88ca448a365e6729e/variants/Seeed_XIAO_nRF52840/variant.h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

https://github.com/hideakitai/ArduinoEigen/blob/f6447f87dfa120eb2bbc8c3d251ef916f014d730/ArduinoEigen/Eigen/src/Core/products/GeneralBlockPanelKernel.h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

案1. Adafruit_nRF52_Arduinoの`#define`を`constexpr`に変更。→問題無さそうだがこのプラットフォーム利用者全員に影響。OwnerはSeeed-Studio。
案2. ArduinoEigenの変数名を変更。→[2022/11のissue](https://github.com/hideakitai/ArduinoEigen/issues/2)が対応されていない。Ownerはhideakitai。
案3. ArduinoEigenの使用をやめる。→OwnerがALGYAN、かつ、Eigenの利用箇所は限定的なので改修は楽。

matsujirushi, 2023-03-17:
案1をこちらに用意した。
https://github.com/algyan/Adafruit_nRF52_Arduino

matsujirushi, 2023-03-17:
マージされました。
もし、問題があればreopenしてください。

TakSan0, 2023-03-17:
マージされたとのことで早速アップデートして試してみようとして、ボードマネージャーを開いて検索すると、
"Seeed nRF52 Boards by Seeed Studio" の最新は 1.1.1 となっており、最新が入っていると認識されているので
更新できませんでした。
一旦、バージョンを1.1.0 に戻して再度1.1.1 を更新したら変わるかなと試してみたのですが、該当ソースを見ると
修正されたはずの箇所は、マクロのままでした。

もしかして、上記更新方法は間違っていますでしょうか？
公式のボードとしては正式にはアップデートされていないので、手動でコピーしないといけないとかありますか？

余り、ボードマネージャーの更新の仕組みが判っていないので、的外れなことを言っていたら申し訳ないのですが、
[platform.txt](https://github.com/Seeed-Studio/Adafruit_nRF52_Arduino/blob/master/platform.txt)
にある、
`version=1.1.1
`
のあたりは更新する必要ないのでしょうか？

matsujirushi, 2023-03-17:
@TakSan0
まだリリースされていないので、ボードマネージャーからアップデートはできないです。
一旦、ボードマネージャーでインストールして、同一フォルダにGitHubから最新を取得して上書きすることで、GitHub上の最新を試すことができます。

```
cd C:\Users\takashi\AppData\Local\arduino15\packages\Seeeduino\hardware\nrf52
rmdir /S /Q 1.1.1
git clone https://github.com/Seeed-Studio/Adafruit_nRF52_Arduino 1.1.1
cd 1.1.1
git submodule init
git submodule update
```

TakSan0, 2023-03-18:
すみません。よくわかってなくて…

rmdir /S /Q 1.1.1
で、書き込み用のツールや設定やヘッダーを消してしまうからなのか
```
Alternatives for Adafruit_USBD_CDC.h: []
ResolveLibrary(Adafruit_USBD_CDC.h)
  -> candidates: []
In file included from D:\DEVELOP\TakSan\MicroComputer\Arduino\ESP32\ALGYAN_Board\ALGYAN8_ES3_Test\ALGYAN8_ES3_Test.ino:10:
C:\Users\TakSan\AppData\Local\Arduino15\packages\Seeeduino\hardware\nrf52\1.1.1\cores\nRF5/Arduino.h:65:10: fatal error: Adafruit_USBD_CDC.h: No such file or directory
   65 | #include "Adafruit_USBD_CDC.h"
      |          ^~~~~~~~~~~~~~~~~~~~~
compilation terminated.

exit status 1

Compilation error: exit status 1
```
といったエラーになって書き込み前くらいの所でエラーで止まってしまいました。

あと、そのまま教えていただいたコマンド
```
submodule init
submodule update

```
を実行しただけでは、なぜかファイルが更新されなかったので、結局
元の 1.1.1 配下のファイルをすべて元に戻したあと
一旦 ブラウザから .zip をダウンロードして解凍後　該当箇所に上書きしました。

その状態で Eigen に何も手を入れていない状態でも、コンパイルエラーとならずに
書き込み成功して動作することが確認できました。

matsujirushi, 2023-03-19:
@TakSan0
`fatal error: Adafruit_USBD_CDC.h: No such file or directory`の件、issue起票しました。 #39

Closed 2023-03-17.

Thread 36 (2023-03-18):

XIAOGYAN のライブラリを XIAO AMD21 向けでコンパイルするとピン定義な無くてエラーとなる。

TakSan0, 2023-03-18:
元記事 [#32](https://github.com/algyan/XIAOGYAN/issues/32#issuecomment-1473753129)

XIAOGYAN のライブラリを XIAO AMD21 向け ("Seeeduino XIAO") のボード設定でコンパイルすると、ピン定義関連のエラーが発生して下記の様なコンパイルエラーとなります。

```
In file included from D:\DEVELOP\XXXXXXXXX\Arduino\ESP32\ALGYAN_Board\ALGYAN8_ES3_Test\Xiaogyan.cpp:1:0:
D:\DEVELOP\XXXXXXXXX\Arduino\ESP32\ALGYAN_Board\ALGYAN8_ES3_Test\Xiaogyan.hpp: At global scope:
D:\DEVELOP\XXXXXXXXX\Arduino\ESP32\ALGYAN_Board\ALGYAN8_ES3_Test\Xiaogyan.hpp:22:51: error: 'D10' was not declared in this scope
     static constexpr uint8_t TM1640_DIN_PIN     = D10;
                                                   ^~~
D:\DEVELOP\XXXXXXXXX\Arduino\ESP32\ALGYAN_Board\ALGYAN8_ES3_Test\Xiaogyan.hpp:22:51: note: suggested alternative: 'A10'
     static constexpr uint8_t TM1640_DIN_PIN     = D10;
                                                   ^~~
                                                   A10
D:\DEVELOP\XXXXXXXXX\Arduino\ESP32\ALGYAN_Board\ALGYAN8_ES3_Test\Xiaogyan.hpp:23:51: error: 'D8' was not declared in this scope
     static constexpr uint8_t TM1640_SCLK_PIN    = D8;
                                                   ^~
D:\DEVELOP\XXXXXXXXX\Arduino\ESP32\ALGYAN_Board\ALGYAN8_ES3_Test\Xiaogyan.hpp:23:51: note: suggested alternative: 'A8'
     static constexpr uint8_t TM1640_SCLK_PIN    = D8;
                                                   ^~
                                                   A8
D:\DEVELOP\XXXXXXXXX\Arduino\ESP32\ALGYAN_Board\ALGYAN8_ES3_Test\Xiaogyan.hpp:24:51: error: 'D0' was not declared in this scope
     static constexpr uint8_t SPEAKER_PIN        = D0;
                                                   ^~
D:\DEVELOP\XXXXXXXXX\Arduino\ESP32\ALGYAN_Board\ALGYAN8_ES3_Test\Xiaogyan.hpp:24:51: note: suggested alternative: 'B0'
     static constexpr uint8_t SPEAKER_PIN        = D0;
                                                   ^~
                                                   B0
D:\DEVELOP\XXXXXXXXX\Arduino\ESP32\ALGYAN_Board\ALGYAN8_ES3_Test\Xiaogyan.hpp:25:51: error: 'D3' was not declared in this scope
     static constexpr uint8_t SPEAKER_ENABLE_PIN = D3;
                                                   ^~
D:\DEVELOP\XXXXXXXXX\Arduino\ESP32\ALGYAN_Board\ALGYAN8_ES3_Test\Xiaogyan.hpp:25:51: note: suggested alternative: 'A3'
     static constexpr uint8_t SPEAKER_ENABLE_PIN = D3;
                                                   ^~
                                                   A3
D:\DEVELOP\XXXXXXXXX\Arduino\ESP32\ALGYAN_Board\ALGYAN8_ES3_Test\Xiaogyan.hpp:26:51: error: 'D1' was not declared in this scope
     static constexpr uint8_t ENCODER_A_PIN      = D1;
                                                   ^~
D:\DEVELOP\XXXXXXXXX\Arduino\ESP32\ALGYAN_Board\ALGYAN8_ES3_Test\Xiaogyan.hpp:26:51: note: suggested alternative: 'B1'
     static constexpr uint8_t ENCODER_A_PIN      = D1;
                                                   ^~
                                                   B1
D:\DEVELOP\XXXXXXXXX\Arduino\ESP32\ALGYAN_Board\ALGYAN8_ES3_Test\Xiaogyan.hpp:27:51: error: 'D2' was not declared in this scope
     static constexpr uint8_t ENCODER_B_PIN      = D2;
                                                   ^~
D:\DEVELOP\XXXXXXXXX\Arduino\ESP32\ALGYAN_Board\ALGYAN8_ES3_Test\Xiaogyan.hpp:27:51: note: suggested alternative: 'A2'
     static constexpr uint8_t ENCODER_B_PIN      = D2;
                                                   ^~
                                                   A2
D:\DEVELOP\XXXXXXXXX\Arduino\ESP32\ALGYAN_Board\ALGYAN8_ES3_Test\Xiaogyan.hpp:28:51: error: 'D6' was not declared in this scope
     static constexpr uint8_t LED_PIN            = D6;
                                                   ^~
D:\DEVELOP\XXXXXXXXX\Arduino\ESP32\ALGYAN_Board\ALGYAN8_ES3_Test\Xiaogyan.hpp:28:51: note: suggested alternative: 'A6'
     static constexpr uint8_t LED_PIN            = D6;
                                                   ^~
                                                   A6
D:\DEVELOP\XXXXXXXXX\Arduino\ESP32\ALGYAN_Board\ALGYAN8_ES3_Test\Xiaogyan.hpp:29:51: error: 'D9' was not declared in this scope
     static constexpr uint8_t BUTTON_A_PIN       = D9;
                                                   ^~
D:\DEVELOP\XXXXXXXXX\Arduino\ESP32\ALGYAN_Board\ALGYAN8_ES3_Test\Xiaogyan.hpp:29:51: note: suggested alternative: 'A9'
     static constexpr uint8_t BUTTON_A_PIN       = D9;
                                                   ^~
                                                   A9
D:\DEVELOP\XXXXXXXXX\Arduino\ESP32\ALGYAN_Board\ALGYAN8_ES3_Test\Xiaogyan.hpp:30:51: error: 'D7' was not declared in this scope
     static constexpr uint8_t BUTTON_B_PIN       = D7;
                                                   ^~
D:\DEVELOP\XXXXXXXXX\Arduino\ESP32\ALGYAN_Board\ALGYAN8_ES3_Test\Xiaogyan.hpp:30:51: note: suggested alternative: 'A7'
     static constexpr uint8_t BUTTON_B_PIN       = D7;
                                                   ^~
                                                   A7
D:\DEVELOP\XXXXXXXXX\Arduino\ESP32\ALGYAN_Board\ALGYAN8_ES3_Test\Xiaogyan.hpp:45:33: error: could not convert template argument 'XiaogyanClass::LED_PIN' from 'const uint8_t {aka const unsigned char}' to 'int'
     static GpioOutputPin<LED_PIN> led;
                                 ^
D:\DEVELOP\XXXXXXXXX\Arduino\ESP32\ALGYAN_Board\ALGYAN8_ES3_Test\Xiaogyan.hpp:46:37: error: could not convert template argument 'XiaogyanClass::BUTTON_A_PIN' from 'const uint8_t {aka const unsigned char}' to 'int'
     static GpioInputPin<BUTTON_A_PIN> buttonA;
                                     ^
D:\DEVELOP\XXXXXXXXX\Arduino\ESP32\ALGYAN_Board\ALGYAN8_ES3_Test\Xiaogyan.hpp:47:37: error: could not convert template argument 'XiaogyanClass::BUTTON_B_PIN' from 'const uint8_t {aka const unsigned char}' to 'int'
     static GpioInputPin<BUTTON_B_PIN> buttonB;
                                     ^
D:\DEVELOP\XXXXXXXXX\Arduino\ESP32\ALGYAN_Board\ALGYAN8_ES3_Test\Xiaogyan.cpp:10:41: note: #pragma message: XIAO_SAMD21 selected
   #pragma message("XIAO_SAMD21 selected")
                                         ^
D:\DEVELOP\XXXXXXXXX\Arduino\ESP32\ALGYAN_Board\ALGYAN8_ES3_Test\Xiaogyan.cpp:35:37: error: could not convert template argument 'XiaogyanClass::LED_PIN' from 'const uint8_t {aka const unsigned char}' to 'int'
 GpioOutputPin<XiaogyanClass::LED_PIN> XiaogyanClass::led;
                                     ^
D:\DEVELOP\XXXXXXXXX\Arduino\ESP32\ALGYAN_Board\ALGYAN8_ES3_Test\Xiaogyan.cpp: In static member function 'static void XiaogyanClass::begin()':
D:\DEVELOP\XXXXXXXXX\Arduino\ESP32\ALGYAN_Board\ALGYAN8_ES3_Test\Xiaogyan.cpp:51:9: error: request for member 'begin' in 'XiaogyanClass::led', which is of non-class type 'int'
     led.begin();
         ^~~~~
D:\DEVELOP\XXXXXXXXX\Arduino\ESP32\ALGYAN_Board\ALGYAN8_ES3_Test\Xiaogyan.cpp:54:13: error: request for member 'begin' in 'XiaogyanClass::buttonA', which is of non-class type 'int'
     buttonA.begin(INPUT_PULLUP);
             ^~~~~
D:\DEVELOP\XXXXXXXXX\Arduino\ESP32\ALGYAN_Board\ALGYAN8_ES3_Test\Xiaogyan.cpp:55:13: error: request for member 'begin' in 'XiaogyanClass::buttonB', which is of non-class type 'int'
     buttonB.begin(INPUT_PULLUP);
             ^~~~~
In file included from D:\DEVELOP\XXXXXXXXX\Arduino\ESP32\ALGYAN_Board\ALGYAN8_ES3_Test\ALGYAN8_ES3_Test.ino:12:0:
D:\DEVELOP\XXXXXXXXX\Arduino\ESP32\ALGYAN_Board\ALGYAN8_ES3_Test\Xiaogyan.hpp: At global scope:
D:\DEVELOP\XXXXXXXXX\Arduino\ESP32\ALGYAN_Board\ALGYAN8_ES3_Test\Xiaogyan.hpp:22:51: error: 'D10' was not declared in this scope
     static constexpr uint8_t TM1640_DIN_PIN     = D10;
                                                   ^~~
D:\DEVELOP\XXXXXXXXX\Arduino\ESP32\ALGYAN_Board\ALGYAN8_ES3_Test\Xiaogyan.hpp:22:51: note: suggested alternative: 'A10'
     static constexpr uint8_t TM1640_DIN_PIN     = D10;
                                                   ^~~
                                                   A10
D:\DEVELOP\XXXXXXXXX\Arduino\ESP32\ALGYAN_Board\ALGYAN8_ES3_Test\Xiaogyan.hpp:23:51: error: 'D8' was not declared in this scope
     static constexpr uint8_t TM1640_SCLK_PIN    = D8;
                                                   ^~
D:\DEVELOP\XXXXXXXXX\Arduino\ESP32\ALGYAN_Board\ALGYAN8_ES3_Test\Xiaogyan.hpp:23:51: note: suggested alternative: 'A8'
     static constexpr uint8_t TM1640_SCLK_PIN    = D8;
                                                   ^~
                                                   A8
D:\DEVELOP\XXXXXXXXX\Arduino\ESP32\ALGYAN_Board\ALGYAN8_ES3_Test\Xiaogyan.hpp:24:51: error: 'D0' was not declared in this scope
     static constexpr uint8_t SPEAKER_PIN        = D0;
                                                   ^~
D:\DEVELOP\XXXXXXXXX\Arduino\ESP32\ALGYAN_Board\ALGYAN8_ES3_Test\Xiaogyan.hpp:24:51: note: suggested alternative: 'B0'
     static constexpr uint8_t SPEAKER_PIN        = D0;
                                                   ^~
                                                   B0
D:\DEVELOP\XXXXXXXXX\Arduino\ESP32\ALGYAN_Board\ALGYAN8_ES3_Test\Xiaogyan.hpp:25:51: error: 'D3' was not declared in this scope
     static constexpr uint8_t SPEAKER_ENABLE_PIN = D3;
                                                   ^~
D:\DEVELOP\XXXXXXXXX\Arduino\ESP32\ALGYAN_Board\ALGYAN8_ES3_Test\Xiaogyan.hpp:25:51: note: suggested alternative: 'A3'
     static constexpr uint8_t SPEAKER_ENABLE_PIN = D3;
                                                   ^~
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
matsujirushi, 2023-03-19:
### Note
#37

TakSan0, 2023-03-19:
ちょっとエラーの詳細みてみましたが解決できていません。

一番最初の、
```
d:\DEVELOP\XXXXXXXXXX\MicroComputer\Arduino\libraries\ArduinoEigen-master/ArduinoEigen/Eigen/src/SparseLU/SparseLU_gemm_kernel.h: In function 'void Eigen::internal::sparselu_gemm(Eigen::Index, Eigen::Index, Eigen::Index, const Scalar*, Eigen::Index, const Scalar*, Eigen::Index, Scalar*, Eigen::Index)':
d:\DEVELOP\XXXXXXXXXX\MicroComputer\Arduino\libraries\ArduinoEigen-master/ArduinoEigen/Eigen/src/SparseLU/SparseLU_gemm_kernel.h:31:3: error: expected primary-expression before 'enum'
   enum {
   ^~~~

```
が、全ての始まりみたいですが、該当箇所見ると、
```
void sparselu_gemm(Index m, Index n, Index d, const Scalar* A, Index lda, const Scalar* B, Index ldb, Scalar* C, Index ldc)
{
  using namespace Eigen::internal;

  typedef typename packet_traits<Scalar>::type Packet;
  enum {
    NumberOfRegisters = EIGEN_ARCH_DEFAULT_NUMBER_OF_REGISTERS,
    PacketSize = packet_traits<Scalar>::size,
    PM = 8,                             // peeling in M
    RN = 2,                             // register blocking
    RK = NumberOfRegisters>=16 ? 4 : 2, // register blocking
    BM = 4096/sizeof(Scalar),           // number of rows of A-C per chunk
    SM = PM*PacketSize                  // step along M
  };
  Index d_end = (d/RK)*RK;    // number of columns of A (rows of B) suitable for full register blocking
  Index n_end = (n/RN)*RN;    // number of columns of B-C suitable for processing RN columns at once
  Index i0 = internal::first_default_aligned(A,m);

  eigen_internal_assert(((lda%PacketSize)==0) && ((ldc%PacketSize)==0) && (i0==internal::first_default_aligned(C,m)));

```
の様になっており、テンプレート使用箇所のどこかで何かが不足していて、enum を正常に定義できずに発生しているという気はします。ただ、テンプレートが 絡むC++のエラーは、エラー箇所と原因が特定しにくくてちょっと苦手です...
ちゃんと解決するには Eigen のライブラリ実装方法をもう少し理解しないといけなくて、本筋から乖離していくかもですね。

因みに、 Eigen を使っている理由はソースを見る限りでは、 MatrixLED の描画データを回転させるためですよね？
で今の所回転したい角度は 90°単位のようですが、それよりも細かく設定できるようにしたかったという事でしょうか？
そうではなく90°単位でいいのであれば、２重ループで回して直接スワップ処理で実現しても問題ない気がします。
（改修時間の費用対効果的にはベターな気がします…）

matsujirushi, 2023-03-21:
> テンプレート使用箇所のどこかで何かが不足していて

`error: expected primary-expression before 'enum'`なので、`typedef typename packet_traits<Scalar>::type Packet;`が文法的に通っていないのでは？想像ですが、C++のバージョンが古いとか。

> Eigen を使っている理由はソースを見る限りでは

はい、回転と反転に使っています。

> 改修時間の費用対効果的にはベターな気がします

いまはハードウェアに影響するissueが最優先なので、Eigen絡みはざくっとコメントにして進めるのが良いと思います。

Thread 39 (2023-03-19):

fatal error: Adafruit_USBD_CDC.h: No such file or directory

matsujirushi, 2023-03-19:
> [元記事](https://github.com/algyan/XIAOGYAN/issues/35#issuecomment-1474941094)

```
Alternatives for Adafruit_USBD_CDC.h: []
ResolveLibrary(Adafruit_USBD_CDC.h)
  -> candidates: []
In file included from D:\DEVELOP\TakSan\MicroComputer\Arduino\ESP32\ALGYAN_Board\ALGYAN8_ES3_Test\ALGYAN8_ES3_Test.ino:10:
C:\Users\TakSan\AppData\Local\Arduino15\packages\Seeeduino\hardware\nrf52\1.1.1\cores\nRF5/Arduino.h:65:10: fatal error: Adafruit_USBD_CDC.h: No such file or directory
   65 | #include "Adafruit_USBD_CDC.h"
      |          ^~~~~~~~~~~~~~~~~~~~~
compilation terminated.

exit status 1

Compilation error: exit status 1
```

matsujirushi, 2023-03-19:
下記手順で環境構築して試したが再現せず。

### プラットフォームパッケージ
```
cd C:\Users\takashi\AppData\Local\arduino15\packages\Seeeduino\hardware\nrf52
rmdir /S /Q 1.1.1
git clone https://github.com/Seeed-Studio/Adafruit_nRF52_Arduino 1.1.1
cd 1.1.1
git submodule init
git submodule update
```

### [依存ライブラリ](https://github.com/algyan/xiaogyan_arduino/blob/main/library.json)
```
cd C:\Users\takashi\Documents\Arduino\libraries
git clone https://github.com/adafruit/Adafruit-GFX-Library
git clone https://github.com/adafruit/Adafruit_BusIO
git clone https://github.com/hideakitai/ArduinoEigen
```

### [xiaogyan_arduino](https://github.com/algyan/xiaogyan_arduino)
```
cd C:\Users\takashi\Documents\Arduino\libraries
git clone https://github.com/algyan/xiaogyan_arduino
```
* include/配下のファイルをsrc/配下へ移動。
* library.propertiesを作成。
* src/Speaker.cppの`ledcAttachPin()`と`ledcWriteTone()`をコメント。

### [xiaogyan_examples](https://github.com/algyan/xiaogyan_examples)
```
git clone https://github.com/algyan/xiaogyan_examples
```
* arduino/HardwareTest/src/main.cppをHardwareTest.inoに名前変更。

matsujirushi, 2023-03-19:
`Adafruit_USBD_CDC.h`はプラットフォームパッケージ内のlibrariesフォルダ配下にあります。
ファイルは存在していますか？
（ファイルが無いならば、git submodule init/updateが正常にできていないと思います。）

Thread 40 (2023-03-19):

xiaogyan_examplesやxiaogyan_arduinoをArduino IDEでコンパイルできない

matsujirushi, 2023-03-19:

matsujirushi, 2023-03-19:
当面、わたしはVisual Studio Code + Platform IO環境でフォローしようと考えています。
上記はどこにも書かれていないので、、、ドキュメントに記入します。

matsujirushi, 2023-03-20:
xiaogyan_arduinoを、Arduino IDE対応した。
https://github.com/algyan/xiaogyan_arduino/commit/91d825f4bbde359a38fda10549fbda40710ee2d2

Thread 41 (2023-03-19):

ES3->配布基板のissue

matsujirushi, 2023-03-19:
- [x] GNDビアを追加
- [x] 部品番号の振り直し->シルクの調整
- [x] R5,R6あたりのRとCの配置を変更
- [x] "A"と"B"のシルク位置を調整
- [x] U3に"label side"のシルクを追加
- [x] 部品表に部品を追加（[コメント](https://github.com/algyan/XIAOGYAN/issues/41#issuecomment-1485762724)、[コメント](https://github.com/algyan/XIAOGYAN/issues/41#issuecomment-1485977479)）

tatsu1225, 2023-03-21:
部品表とES3基板を確認しました．10KΩの抵抗は1608でFIXですか？
関連： 1608チップ抵抗の入手方法 #23

tatsu1225, 2023-03-21:
既に確認済みかもしれませんが，U10 のEC12E(Panel)[P-06357]ですが，ノンクリックタイプで良ければ在庫ありなようです
https://akizukidenshi.com/catalog/g/gP-06358/

tatsu1225, 2023-03-21:
ソケットは部品表に記載なしですが，公式的には直付けで付けたい人はご自由に．ですかね？
組立手順書を作る際にどちらにしようかと思ってます．

【ソケットありにすると...？】
　①部品代が安くなる
　**②他のXIAOに差し替えて遊べる**
　③ユニバーサル基板に回路拡張した際にXIAO壊したら交換できる
　④オペアンプは逆に半田付けしてしまった時の保険になる？
　⑤高さがでる　→　ロータリエンコーダの背が高いので何とも...

まとめてて⑤があまり強い理由にならないので，②の強みを推してソケットありを標準にしても良いかも．と思いました
あとは①との兼ね合いですかね

matsujirushi, 2023-03-22:
> 部品表とES3基板を確認しました．10KΩの抵抗は1608でFIXですか？ 関連： 1608チップ抵抗の入手方法 #23

1608とします。
こちらにも記入しました。 #23

matsujirushi, 2023-03-22:
> 既に確認済みかもしれませんが，U10 のEC12E(Panel)[P-06357]ですが，ノンクリックタイプで良ければ在庫ありなようです https://akizukidenshi.com/catalog/g/gP-06358/

触ってみるとわかるのですが、ノンクリックは回転トルクが大きすぎるんです...。

tatsu1225, 2023-03-22:
> > 既に確認済みかもしれませんが，U10 のEC12E(Panel)[P-06357]ですが，ノンクリックタイプで良ければ在庫ありなようです https://akizukidenshi.com/catalog/g/gP-06358/
>
> 触ってみるとわかるのですが、ノンクリックは回転トルクが大きすぎるんです...。

あー、確かに。手元に同型番の部品を持っていますが、確かにその通りですね。では、現行のU10を標準として考えます。

EC12E、基板の穴にもピッタリハマって収まりが良さそうなのに惜しい…🥲🥲🥲

y-ohe, 2023-03-26:
@matsujirushi さん
ES3基板のR7、R18は、10KΩ×2(=5KΩ)だとロータリーエンコーダのLEDが非常に暗いので、100Ω1個ぐらいにした方が良さそうです。
秋月電子通商に1608の100Ω抵抗はあるので、これを購入して使ってもらえば良いと思います。
↓
https://akizukidenshi.com/catalog/g/gR-11789/

matsujirushi, 2023-03-26:
@y-ohe さん、アドバイスありがとうございます。

[基板配布時に10Kを同封](https://github.com/algyan/XIAOGYAN/discussions/23#discussioncomment-5391956)するので、部品リストは10Kのままにしておき、改造ネタで100換装という扱いにしようと思います。 （業務連絡 > @tatsu1225 )

y-ohe, 2023-03-27:
LED1とR12もありますしね。
LED1には、手持ちの5mm赤LEDを実装して、ロータリーエンコーダーのLEDとの同時点灯を確認しました。

tatsu1225, 2023-03-27:
期日間に合わずスミマセン．遅くなりましたが，ES3の実装終わりました！以下の動作を確認済み．
  1. マトリクスLED
  2. ボタン(A,B)
  3. スピーカ
  4. エンコーダ
  5. Groveコネクタ(SHT31で動作を確認)

実装時に気になった確認事項は以下の通り．
  - JP1は3.3VをショートしましたがOKですか？
  - JP2はSPKEAKER-ENABLEをショートしましたがOKでしたか？
  - スピーカ鳴動時のボリュームですが，ツマミを真ん中付近にした時が最大音量．左右のどちらかに回しきる時が最小音量の認識でOKですか？

組立手順的な観点からの指摘事項は以下の点です．が，現状のままでも問題無い内容です．
 - 初学者向けに振るならば，JP1, JP2はデフォルトでショートさせても良いかも？ → 工程は増えるが組立手順で提示すれば問題なし
 - 0Ω抵抗はハンダのみでショートさせることは出来ないので，抵抗の足などを利用することが推奨 → 初学者向けには0Ω抵抗の購入がbetter
 - マトリクスLEDはシルクで向きが分かるようにしても良いかも？ → 組立手順の工夫で何とでもなる

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

tatsu1225, 2023-03-27:
しかし，U10の設計はお見事ですね!! クリッカブルなEC12E(Panel)が在庫切れなのが非常に惜しい...!!(組立手順には載せておこうと思っています
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

tatsu1225, 2023-03-27:
ES3基板の組立には写真を撮りながらでしたが，ザックリ3時間ぐらいでした．
手順書アリで組みなれた人なら2時間かからないぐらいかな？
どの程度の時間かかりました？ > @y-ohe @matsujirushi

y-ohe, 2023-03-27:
> 1. [ピンヘッダ　１×４０　（４０Ｐ）](https://akizukidenshi.com/catalog/g/gC-00167/)
> 2. [分割ロングピンソケット　１×４２　（４２Ｐ）](https://akizukidenshi.com/catalog/g/gC-05779/)

ここは、私は高さを押さえたくて、
1. [ロープロファイルピンヘッダ（低オス）　１×４０（４０Ｐ）　７．７ｍｍ](https://akizukidenshi.com/catalog/g/gC-02900/)
2. [シングルピンソケット　（低メス）　１×２０　（２０Ｐ）](https://akizukidenshi.com/catalog/g/gC-03138/)
を使っています。

> どの程度の時間かかりました？ > @y-ohe @matsujirushi

ちゃんと時間を計らなかったので、感覚的な数字になりますが、**1時間**ぐらいだったと思います。
やはり、マトリクスLEDは、組み付けの向きがそのままでは分からず、 @matsujirushi さんの組立て後の写真を見てサイドに部品のマーキングがなかったところから何とか間違わずにはんだ付けができました。

matsujirushi, 2023-03-27:
@tatsu1225
ご確認ありがとうございます！

> * JP1は3.3VをショートしましたがOKですか？

OKです。（データシートによるとU2は3.3V NGですが、、、動いているので3.3Vにしましょう。issueが上がったら対処ということで。）

> * JP2はSPKEAKER-ENABLEをショートしましたがOKでしたか？

OKです。

> * スピーカ鳴動時のボリュームですが，ツマミを真ん中付近にした時が最大音量．左右のどちらかに回しきる時が最小音量の認識でOKですか？

設計意図とは違いますが、誰からも指摘が無い&代案も無いので、振る舞いのとおりです。
v2までに、誰かが変更するのに期待しています。

> * 初学者向けに振るならば，JP1, JP2はデフォルトでショートさせても良いかも？ → 工程は増えるが組立手順で提示すれば問題なし

どちらを選択しているかを使用者に認識してほしいのでデフォルトでショートにしていません。

> * 0Ω抵抗はハンダのみでショートさせることは出来ないので，抵抗の足などを利用することが推奨 → 初学者向けには0Ω抵抗の購入がbetter

あとから改造しやすいように、0Ω抵抗としました。

> * マトリクスLEDはシルクで向きが分かるようにしても良いかも？ → 組立手順の工夫で何とでもなる

U3に"label side"のシルクを追加しました。

matsujirushi, 2023-03-27:
@tatsu1225

> ES3基板の組立には写真を撮りながらでしたが，ザックリ2.5時間ぐらいでした． 手順書アリで組みなれた人なら1時間かからないぐらいかな？ どの程度の時間かかりました？ > @y-ohe @matsujirushi

どうだろう？2時間くらいかな。（作業合間に実装を進めたので分からないです）

matsujirushi, 2023-03-27:
FYI
U3の"label side"のシルク。
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

matsujirushi, 2023-03-27:
@tatsu1225 ピンヘッダとピンソケット、どの部品にしますか？
https://github.com/algyan/XIAOGYAN/issues/41#issuecomment-1485762724
https://github.com/algyan/XIAOGYAN/issues/41#issuecomment-1485977479

わたしが気になる点としては、XIAO ESP32C3を使い回すことも想定するなら、ブレッドボードに差しやすい細ピンにしたほうが良いと思いました。

全てを満たすパーツは無いと思いますので、お任せします。

tatsu1225, 2023-04-03:
すんません、遅くなりました
@matsujirushi さん案の細ピンヘッダ＆細ピン用の分割ロングピンソケットでいきましょう！
https://akizukidenshi.com/catalog/g/gC-04398/
https://akizukidenshi.com/catalog/g/gC-10073/

610t, 2023-04-25:
> ES3基板の組立には写真を撮りながらでしたが，ザックリ2.5時間ぐらいでした． 手順書アリで組みなれた人なら1時間かからないぐらいかな？ どの程度の時間かかりました？ > @y-ohe @matsujirushi

今日作成しました。
表面実装は初めてだったのですが、1.5時間で作成完了でした。

Closed 2023-05-28.

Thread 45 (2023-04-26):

R7とC6を変更

matsujirushi, 2023-04-26:
### Discussed in https://github.com/algyan/XIAOGYAN/discussions/44

* R7=0 -> 10K
* C6=DNP -> 1000p

matsujirushi, 2023-04-26:
* R7=10K
* C6=1000p （チップ部品の手持ちが無かったので、リード部品で代用）

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

- [ ] [HardwareTest](https://github.com/algyan/xiaogyan_examples/tree/main/platformio/HardwareTest)、動作確認
- [ ] [PlayWave](https://github.com/algyan/xiaogyan_examples/tree/main/platformio/PlayWave)、動作確認
- [ ] [回路図変更](https://github.com/algyan/XIAOGYAN/blob/main/hardware/xiaogyan.v1.sch)の可否
- [ ] [部品リスト](https://github.com/algyan/XIAOGYAN/blob/main/hardware/xiaogyan.v1.xlsx)変更の可否
- [ ] 組立手順書（@tatsu1225）変更の可否

matsujirushi, 2023-04-26:
- [x] [回路図](https://github.com/algyan/XIAOGYAN/blob/main/hardware/xiaogyan.v1.sch)の変更
- [x] [部品リスト](https://github.com/algyan/XIAOGYAN/blob/main/hardware/xiaogyan.v1.xlsx)の変更
- [x] 組立手順書（@tatsu1225）の変更

Closed 2023-05-28.

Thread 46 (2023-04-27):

Arduinoで作ったプログラムで、コンパイル時にスピーカー関係のエラーが出る。

610t, 2023-04-27:
現在、XIAOGYANでScratch3(正確にはStretch3 https://stretch3.github.io/ のMicrobit More拡張機能)を使えるようにするXIAOGYANbitLess https://github.com/610t/XIAOGYANbitLess を作っています。

スピーカーのArduinoプログラムでの利用についてお聞きしたいのです。

PlatformIOでは、platformio.iniの中で、-D SPEAKER=1としてスピーカーの種類を渡しています。
Arduino用に、以下のようにして、プログラム中で強制的にSPEAKER 1を使うようにしています。
~~~
#if !defined(SPEAKER)
#define SPEAKER 1
#endif
#include <Xiaogyan.hpp>
~~~

実際にスピーカーを利用してる部分のコードはこんな感じです。
~~~
// Tone handler
void playToneTask(void *args) {
  uint16_t freq = 1000000 / duration;

  Xiaogyan.speaker.setTone(freq);
  delay(duration);
  Xiaogyan.speaker.setTone(0);
}
~~~

コンパイルエラーは以下の通りです。
undefined reference to `XiaogyanClass::speaker'となってしまいます。
~~~
/Users/mutoh/Library/Arduino15/packages/esp32/tools/riscv32-esp-elf-gcc/esp-2021r2-patch5-8.4.0/bin/../lib/gcc/riscv32-esp-elf/8.4.0/../../../../riscv32-esp-elf/bin/ld: sketch/main.cpp.o: in function `playToneTask(void*)':
/Volumes/mutoh/work/github/XIAOGYANbitLess/src/main.cpp:580: undefined reference to `XiaogyanClass::speaker'
/Users/mutoh/Library/Arduino15/packages/esp32/tools/riscv32-esp-elf-gcc/esp-2021r2-patch5-8.4.0/bin/../lib/gcc/riscv32-esp-elf/8.4.0/../../../../riscv32-esp-elf/bin/ld: /Volumes/mutoh/work/github/XIAOGYANbitLess/src/main.cpp:580: undefined reference to `XiaogyanClass::speaker'
/Users/mutoh/Library/Arduino15/packages/esp32/tools/riscv32-esp-elf-gcc/esp-2021r2-patch5-8.4.0/bin/../lib/gcc/riscv32-esp-elf/8.4.0/../../../../riscv32-esp-elf/bin/ld: /Volumes/mutoh/work/github/XIAOGYANbitLess/src/main.cpp:581: undefined reference to `XiaogyanClass::speaker'
collect2: error: ld returned 1 exit status
Multiple libraries were found for "BLEDevice.h"
  Used: /Users/mutoh/Library/Arduino15/packages/esp32/hardware/esp32/2.0.8/libraries/BLE
  Not used: /Users/mutoh/Documents/Arduino/libraries/Seeed_Arduino_rpcBLE
exit status 1

Compilation error: exit status 1
~~~

同じコードをPlatformIOでコンパイルすると、無事に終了します。

理由がわかる方、おられますでしょうか?

matsujirushi, 2023-04-27:
**Xiaogyan.cpp**をコンパイル時に`SPEAKER`がdefineされていないのが原因と思います。

https://github.com/algyan/xiaogyan_arduino/blob/55b46463c1de0b06da0e00ceb5f67c5adc5e81f4/src/Xiaogyan.cpp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

Arduinoスケッチだけで対処は無理じゃないかと思います。
以下、案です。

1. ライブラリの**Xiaogyan.hpp**に下記コードを追加する。
```cpp
#if !defined(SPEAKER)
#define SPEAKER 1
#endif
```
2. プラットフォームの**platform.txt**に`-D SPEAKER=1`を追加する。

610t, 2023-04-28:
2.の方法だと、グローバルな設定ファイルに`-D SPEAKER=1`を追加することになるんですよね?
リポジトリ内に置いたファイルを読み込んでくれるのなら、それでも良いかと思うのですが…

1.の方法で動くことは確認しました。
特に副作用などの問題が問題がないようでしたら、1の方向で対応してもらえないでしょうか?

matsujirushi, 2023-04-28:
Arduino IDEでエラーが発生する件は #47 で対応します。

matsujirushi, 2023-04-28:
@610t
#47 で対応完了しました。

Closed 2023-04-28.

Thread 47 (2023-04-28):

[Arduino IDE] undefined reference to `XiaogyanClass::speaker`

matsujirushi, 2023-04-28:
[xiaogyan_arduino](https://github.com/algyan/xiaogyan_arduino)でコンパイルエラーが発生する。

```
/Users/mutoh/Library/Arduino15/packages/esp32/tools/riscv32-esp-elf-gcc/esp-2021r2-patch5-8.4.0/bin/../lib/gcc/riscv32-esp-elf/8.4.0/../../../../riscv32-esp-elf/bin/ld: sketch/main.cpp.o: in function `playToneTask(void*)':
/Volumes/mutoh/work/github/XIAOGYANbitLess/src/main.cpp:580: undefined reference to `XiaogyanClass::speaker'
/Users/mutoh/Library/Arduino15/packages/esp32/tools/riscv32-esp-elf-gcc/esp-2021r2-patch5-8.4.0/bin/../lib/gcc/riscv32-esp-elf/8.4.0/../../../../riscv32-esp-elf/bin/ld: /Volumes/mutoh/work/github/XIAOGYANbitLess/src/main.cpp:580: undefined reference to `XiaogyanClass::speaker'
/Users/mutoh/Library/Arduino15/packages/esp32/tools/riscv32-esp-elf-gcc/esp-2021r2-patch5-8.4.0/bin/../lib/gcc/riscv32-esp-elf/8.4.0/../../../../riscv32-esp-elf/bin/ld: /Volumes/mutoh/work/github/XIAOGYANbitLess/src/main.cpp:581: undefined reference to `XiaogyanClass::speaker'
collect2: error: ld returned 1 exit status
Multiple libraries were found for "BLEDevice.h"
  Used: /Users/mutoh/Library/Arduino15/packages/esp32/hardware/esp32/2.0.8/libraries/BLE
  Not used: /Users/mutoh/Documents/Arduino/libraries/Seeed_Arduino_rpcBLE
exit status 1

Compilation error: exit status 1
```

Ref. #46

matsujirushi, 2023-04-28:
Fixed.
https://github.com/algyan/xiaogyan_arduino/commit/8fdc7fe54b6e8832188ff605dda0bccd0b334f15

Closed 2023-04-28.

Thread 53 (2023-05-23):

【誤記】組み立てマニュアル2.4.7のC6実装の写真(青枠)がC7を示している＆2.4.8のチップコンデンサ一覧(青枠)に漏れがある

y-ohe, 2023-05-23:
組み立てマニュアル2.4.7のC6実装の写真(青枠)がC7を示しています。
C6の場所はスピーカとボリュームの間の下側パッドになります。
青枠の位置を修正した写真に差し替えが必要です。
さらに、2.4.8のチップコンデンサの実装確認の写真において、C3、C4、C5、**C7**のみが青枠で囲まれていて、誤記があります。
正しくは、**C1**、**C2**、C3、C4、C5、**C6** を青枠で囲む必要があります。（C7は間違い！）

tatsu1225, 2023-05-23:
ありがとうございます．修正してプルリクを投げました！
https://github.com/algyan/XIAOGYAN/pull/54#issue-1722322287

yamati-kz, 2023-06-14:
@2.4.8のチップコンデンサ一覧(青枠)に漏れがある

C1とC2の青枠が漏れています。他は囲われています。

matsujirushi, 2023-06-14:
@tatsu1225 確認お願いしますー

tatsu1225, 2023-06-14:
@matsujirushi 承知です．確認します
@yamati-kz ご指摘ありがとうございます！青枠漏れてますね．というわけでサクッと修正しました．また何か気になる点などあればぜひ指摘頂ければと思います
https://github.com/algyan/XIAOGYAN/commit/f8f1ed80d11305f96bade13c57993fa9a335cee9

yamati-kz, 2023-06-14:
@tatsu1225 早々のご対応ありがとうございました。青枠の追記を確認いたしました。

Closed 2023-06-20.

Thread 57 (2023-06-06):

組立てマニュアル　JP1のはんだ付け順序

mnltake, 2023-06-06:
組立てマニュアル
2.3. 基板裏面のショートジャンパへのはんだ付け
https://github.com/algyan/XIAOGYAN/blob/main/manuals/assembly/README.md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
先に裏面にはんだ付けすると表面に部品を取り付けるときに基板が不安定になるので最後にしたほうがよさそう（個人の感想です）

tatsu1225, 2023-06-11:
すみません、コメント遅くなりました．組立マニュアルを作成した者です．
確かに，ハンダを多めに盛ってしまうとガタつく可能性がありますね．
最後に裏面のハンダですと，実装したマイコンやエンコーダなどの背の高い部品が邪魔になりそうです．

変更するとしたら, 2.3と2.4の入替でしょうか．表面の表面実装が終わった後に，裏面のショートジャンパのような流れ．
> 　2.3 基板裏面のショートジャンパへのはんだ付け
> 　2.4 表面実装品のはんだ付け
> 　2.5 挿入実装品のはんだ付け

mnltake, 2023-06-11:
ありがとうございます。そうですね表面に高い部品が付く前のほうがいいですね

ちょうどJP1が基板中央にあるのでピンセットで表面に置くような部品のときにガタつくのが気になったもので

Closed 2023-06-12.

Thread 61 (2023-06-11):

組み立てマニュアル Groveコネクタのはんだ付け

matsujirushi, 2023-06-11:
### Discussed in https://github.com/algyan/XIAOGYAN/discussions/58

<div type='discussions-op-text'>

<sup>Originally posted by **shoko93** June 11, 2023</sup>
Issueに書くか迷いましたがひとまずこちらに投稿しておきます。
組み立てマニュアルの2.5.4. Groveコネクタのはんだ付けについて。
秋月で購入したＬ型のGroveコネクタの場合そのままだと↓の写真の通りにはならないので、少し迷いました。
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
（私の場合はよくわからなかったので、L字の足を無理やりまっすぐにしました。。）</div>

tatsu1225, 2023-06-11:
これは私のやらかしですね．誤ってI字のGroveコネクタで実装してしまったようです．
全部の写真の差し替えは難しいですが，指摘頂いた箇所については撮影して修正します

tatsu1225, 2023-06-11:
こんな感じでどうでしょう？
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

Closed 2023-06-12.

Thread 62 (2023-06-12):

道具のドキュメントを追加

matsujirushi, 2023-06-12:
道具への投資の考え方（とりあえず安くとか、長く使いたいとか）がひとそれぞれだと思いますし、販売状況が変わったときのドキュメント更新が大変なので、、、
あくまで参考ということで組立マニュアルとは別に**道具のドキュメント**を用意しようと思います。

ご協力いただける詳しい方が出てきたら改訂してもらうことにしましょう。

_Originally posted by @matsujirushi in https://github.com/algyan/XIAOGYAN/discussions/60#discussioncomment-6157536_

Closed 2023-06-20.

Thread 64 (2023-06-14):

回路図のR7とC6の値が間違っている

matsujirushi, 2023-06-14:
@matsujirushi お手すきの時に[回路図](https://github.com/algyan/XIAOGYAN/blob/main/hardware/xiaogyan.v1.pdf)を更新いただけますと幸いです。他の関連ドキュメントは組立マニュアルの数値と合致してます。R7がゼロ、C6がDNPとなっています。

_Originally posted by @yamati-kz in https://github.com/algyan/XIAOGYAN/issues/63#issuecomment-1590761304_

Closed 2023-06-14.

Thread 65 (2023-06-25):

XIAOGYANやってみたよ！！ユーザー投稿

Mihokun, 2023-06-25:
### Discussed in https://github.com/algyan/XIAOGYAN/discussions/50

<div type='discussions-op-text'>

<sup>Originally posted by **matsujirushi** May 17, 2023</sup>

【成功 と 今後の心配を...】
* XIAOGYAN、ゲットしたぜ！
* VS Code & PlatformIO 環境構築したぜ！
* HardwareTest のビルドうまく動いたぞ！

けど、なんやかんやいって、いつもこううまくいくとは限らない。

失敗作=いらない プロジェクトの削除の仕方って立派な開発環境になればなるほど、悩む=怖いw

VS Code からプロジェクト選んで削除でいいの？か？
Windowsのエクスプローラから プロジェクト=フォルダ をゴミ箱にポイでいいの？か？

ご存知の方、私にわかりやすいように ^^; 教えてください ^^;

</div>

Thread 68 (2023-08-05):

2023/8/5現在 秋月電子でNJM2113Dが売り切れ中です

yak1ex, 2023-08-05:
その結果、「秋月電子通商 部品を買い物かごに入れる」のリンクを踏むと以下の表示が出ます。

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

別店舗での購入以外の手段としては、
* 回路図、部品表、基板を参照したところNJM2113M(I-10981)での代替を想定されているということでよろしいでしょうか？(※こちらも通販在庫数：12ですが)
* またこちらは自己責任かもしれませんがピン互換と思われるMC34119(I-17430)での対応もありでしょうか？ ref. http://tmj114.web.fc2.com/amp/miniamp.html

matsujirushi, 2023-08-05:
情報ありがとうございます！

* 代わりに、`NJM2113M(I-10981)`でもOKです。
* `MC34119(I-17430)`は未確認です。

（だれか`MC34119(I-17430)`で試したら、結果を教えてください...）

yamati-kz, 2023-08-06:
違和感ないです・MC34119(I-17430)を試しましたが聴いた感じでは...
本来の部品リスト上、NJM2113D(I-11192がが在庫不足ということで代替を試してみました。石が代わってもそれなりに動くのかなと思いつつ。オシロで違いを明示できればいいのですが、そんな技術者なく...
HardwareTest.binで試しています。平ピンICソケットなので載せ替えはすぐにできます。

yamati-kz, 2023-08-09:
・ご参考になるかわかりませんがオシロで波形を取ってみました。
 　　　部品リスト品 : [NJM2113D(I-11192)](https://akizukidenshi.com/catalog/g/gI-11192/)
　　　代替候補品 : [MC34119(I-17430)](https://akizukidenshi.com/catalog/g/gI-17430/)

・IC PinNo.8(VOUT2)とGND間の波形です。ボリュームはMAX(右側に回し切った状態)。

・NJM2113DでボタンＡを押したとき。
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

・NJM2113DでボタンBを押したとき。
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

・MC34119でボタンＡを押したとき。
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

・MC34119でボタンＢを押したとき。
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

matsujirushi, 2023-08-09:
@yamati-kz
すばらしい！確認ありがとうございます。

もし可能でしたら、[PlayWave](https://github.com/algyan/xiaogyan_examples/tree/main/platformio/PlayWave)も確認していただけませんか？（聴いた感じの比較で結構ですので）

yamati-kz, 2023-08-09:
@matsujirushi
聴いた感じ区別できません、私のような素人の耳では聞き分けできませんでした。
[PlayWave](https://github.com/algyan/xiaogyan_examples/tree/main/platformio/PlayWave)でのホワイトノイズの感じとか、とても可愛いお子ちゃまの声の感じとか、音量も違わないといいますか...

yak1ex, 2023-08-12:
在庫復活しておりました。
MC34119も買っていましたので安心して使用できます。ありがとうございます。

Closed 2023-08-12.

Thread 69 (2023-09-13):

糸はんだを変更すべきか？

matsujirushi, 2023-09-13:
先日のALGYANイベントで、糸はんだ0.8mmは辛そうだった。
変更すべきか？

https://github.com/algyan/XIAOGYAN/blob/main/manuals/equipment/README.md

tatsu1225, 2023-12-10:
返信が滞ってました．スミマセン．
0.8mmは確かにきつそうでしたね．ただ秋月電子には0.8mm未満で少量のハンダが売っていない点が悩ましいところですね．

- [秋月電子 T-09529　：1350円(100g入り)](https://akizukidenshi.com/catalog/g/gT-09529/)
- [Amazon SD-60　：602円(約11g)](https://amzn.asia/d/0d6yEac)

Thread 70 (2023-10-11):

XIAOGYANやってみたよ！！ユーザー投稿

Mihokun, 2023-10-11:
### Discussed in https://github.com/algyan/XIAOGYAN/discussions/50

<div type='discussions-op-text'>

<sup>Originally posted by **matsujirushi** May 17, 2023</sup>
* XIAOGYAN、ゲットしたぜ！
      [https://www.youtube.com/watch?v=aYTGTDFOVHw&t=4600s](url)
* はんだ付け一発成功だぜ！
      [https://www.youtube.com/watch?v=WzVGK7PBv9Q](url)
* 動作確認できたぞ！
      [https://github.com/algyan/XIAOGYAN/blob/main/manuals/test/README.md](url)

     esptool どうやって実行するんだ？と数分悩んだけど、
     あ！コマンドプロンプト で esptool.exe あるとこまでいって、
     esptool write_flash 0x0 HardwareTest.bin 実行するんだ！と閃いて ^^
     ゆっくりゆっくり、ここまできた ^^#

https://github.com/algyan/XIAOGYAN/assets/9550393/cdeb6616-b46b-43fd-b12d-a839eda673dc

</div>

Closed 2023-11-04.

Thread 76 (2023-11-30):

BOOTHからの基板入手

matsujirushi, 2023-11-30:
BOOTHから基板を購入できるが、
https://matsujirushi.booth.pm/items/5108023

ここに書かれていない。
https://github.com/algyan/XIAOGYAN/blob/main/manuals/order/README.md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

Closed 2023-11-30.

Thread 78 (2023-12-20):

外付けLCDにST7789を接続したいが、WiFiが不安定、繋がらない

kurokouji, 2023-12-20:
XIAOGYAN基板のLEDマトリックスの部分を液晶（240x240）ST7789に置き換えたバージョンを利用したいと思い
SPI接続でLovyanGFXで表示することができました。
さて、Wifi接続を試したところ、繋がったり、切れたり　一旦切れると繋がらなくなったりと不安定な動作をしています。
何か注意する点ありますでしょうか？

kurokouji, 2023-12-21:
不安定な原因を想定できました。ST7789の電源3.3VはXiao ESP32C3を経由して供給されています。しかし、Wifiを使用すると電源の負荷が上がり、内部温度が50度を超えてしまうようです。その結果、保護回路が働くためか不安定になるようです。
問題の解決策として、ST7789に供給される電源には、5Vから3.3Vに変換する三端子レギュレータを通す必要がありそうです。
部品を調達して正常に動作することが確認できたら、issueをクローズします。

kurokouji, 2023-12-23:
Seeed Studio XIAO 拡張ボードを購入してXiao ESP32S3を動作させたところ全く不安定さが無くなりました。
画像ではWifi接続状態で、CPU温度が30.7度になっています。
これまでは40～50度でしたので全然違います。
拡張ボードのCPUピンでいうところの5V（14番ピン）、GND（13番ピン）のみに　５Vを接続したところ、拡張基板内部に3.3Vが供給されていました。
今までは動作中のCPUが熱かったのですが、拡張基板と接続して動作させると30度程度、体温より低い温度なので熱さは感じなくなりました。
開発時のPCとのSerial接続の安定性も格段に向上しました。
XIAOGYAN基板もフリー領域に3.3Vの定電圧レギュレータをつけ、基板内供給する改造が必要そうです。

kurokouji, 2023-12-23:
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

kurokouji, 2023-12-23:
CPUクロック240MHz、ST7789接続、Wifi接続、BLEでSwitchBOT温湿度センサ読み取りを実行時のCPU温度です。
50度を超えても、動作は不安定になりませんでした。
動作不安定の原因は、Xiao ESP32S3の3.3V端子への過負荷のようです。
ctmp : 50.5 rssi : -58 time : 2023-12-23 17:50:15
ctmp : 50.9 rssi : -61 time : 2023-12-23 17:51:15
ctmp : 52.2 rssi : -62 time : 2023-12-23 17:52:15
ctmp : 52.7 rssi : -60 time : 2023-12-23 17:53:15
ctmp : 53.6 rssi : -72 time : 2023-12-23 17:54:15
ctmp : 53.6 rssi : -59 time : 2023-12-23 17:55:17
ctmp : 54.0 rssi : -62 time : 2023-12-23 17:56:17
ctmp : 54.4 rssi : -71 time : 2023-12-23 17:57:17
ctmp : 54.4 rssi : -71 time : 2023-12-23 17:58:17

Closed 2023-12-23.

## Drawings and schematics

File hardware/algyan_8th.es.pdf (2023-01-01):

U3 ROW1 | 9 ROW2 | 14 ROW3 | 8 ROW4 | 12 ROW5 | 1 ROW6 | 7 ROW7 | 2 ROW8 | 5

# ESC-BTN ⁵V 5V

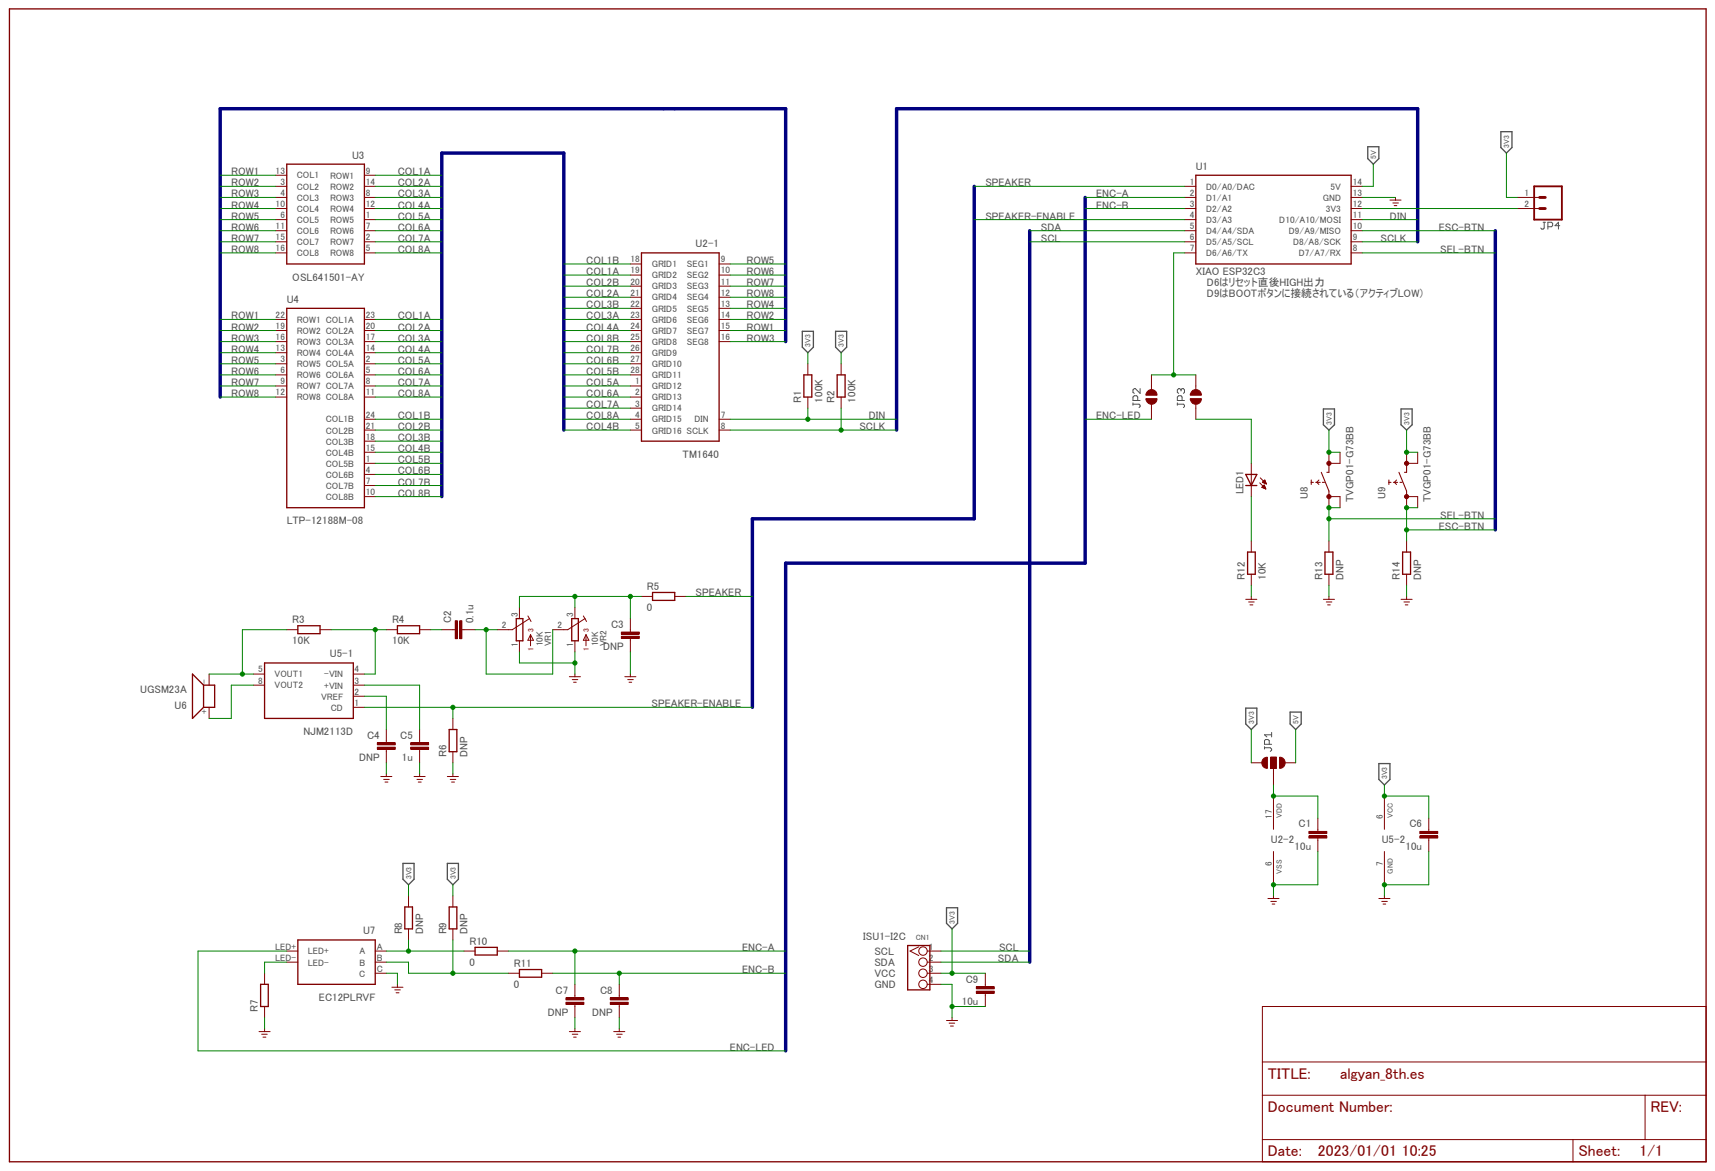
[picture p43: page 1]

COL2B | ROW7
COL2A | ROW8
COL3B | ROW4

ROW3 | COL4A | COL4A COL8B | ROW3

ROW4 | | COL7B
ROW5 | | COL6B
ROW7 | COL6A | COL6A
ROW8 | COL7A | COL7A

COL8A COL1B | COL8A

COL2B | | | SCLK

Document Number: | REV:

Date: 2023/01/01 10:25 | Sheet: 1/1

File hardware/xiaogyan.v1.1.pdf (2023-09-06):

U3ROW1 22 | ROW2 19 | ROW3 16 | ROW4 13 | ROW5 3 | ROW6 6 | ROW7 9 | ROW8 12
COL1A | 23 COL2A | 20 COL3A | 17 COL4A | 14 COL5A | 2 COL6A | 5 COL7A | 8 COL8A | 11 COL1B | 24 COL2B | 21 COL3B | 18 COL4B | 15 COL5B | 1 COL6B | 4 COL7B | 7 COL8B | 10

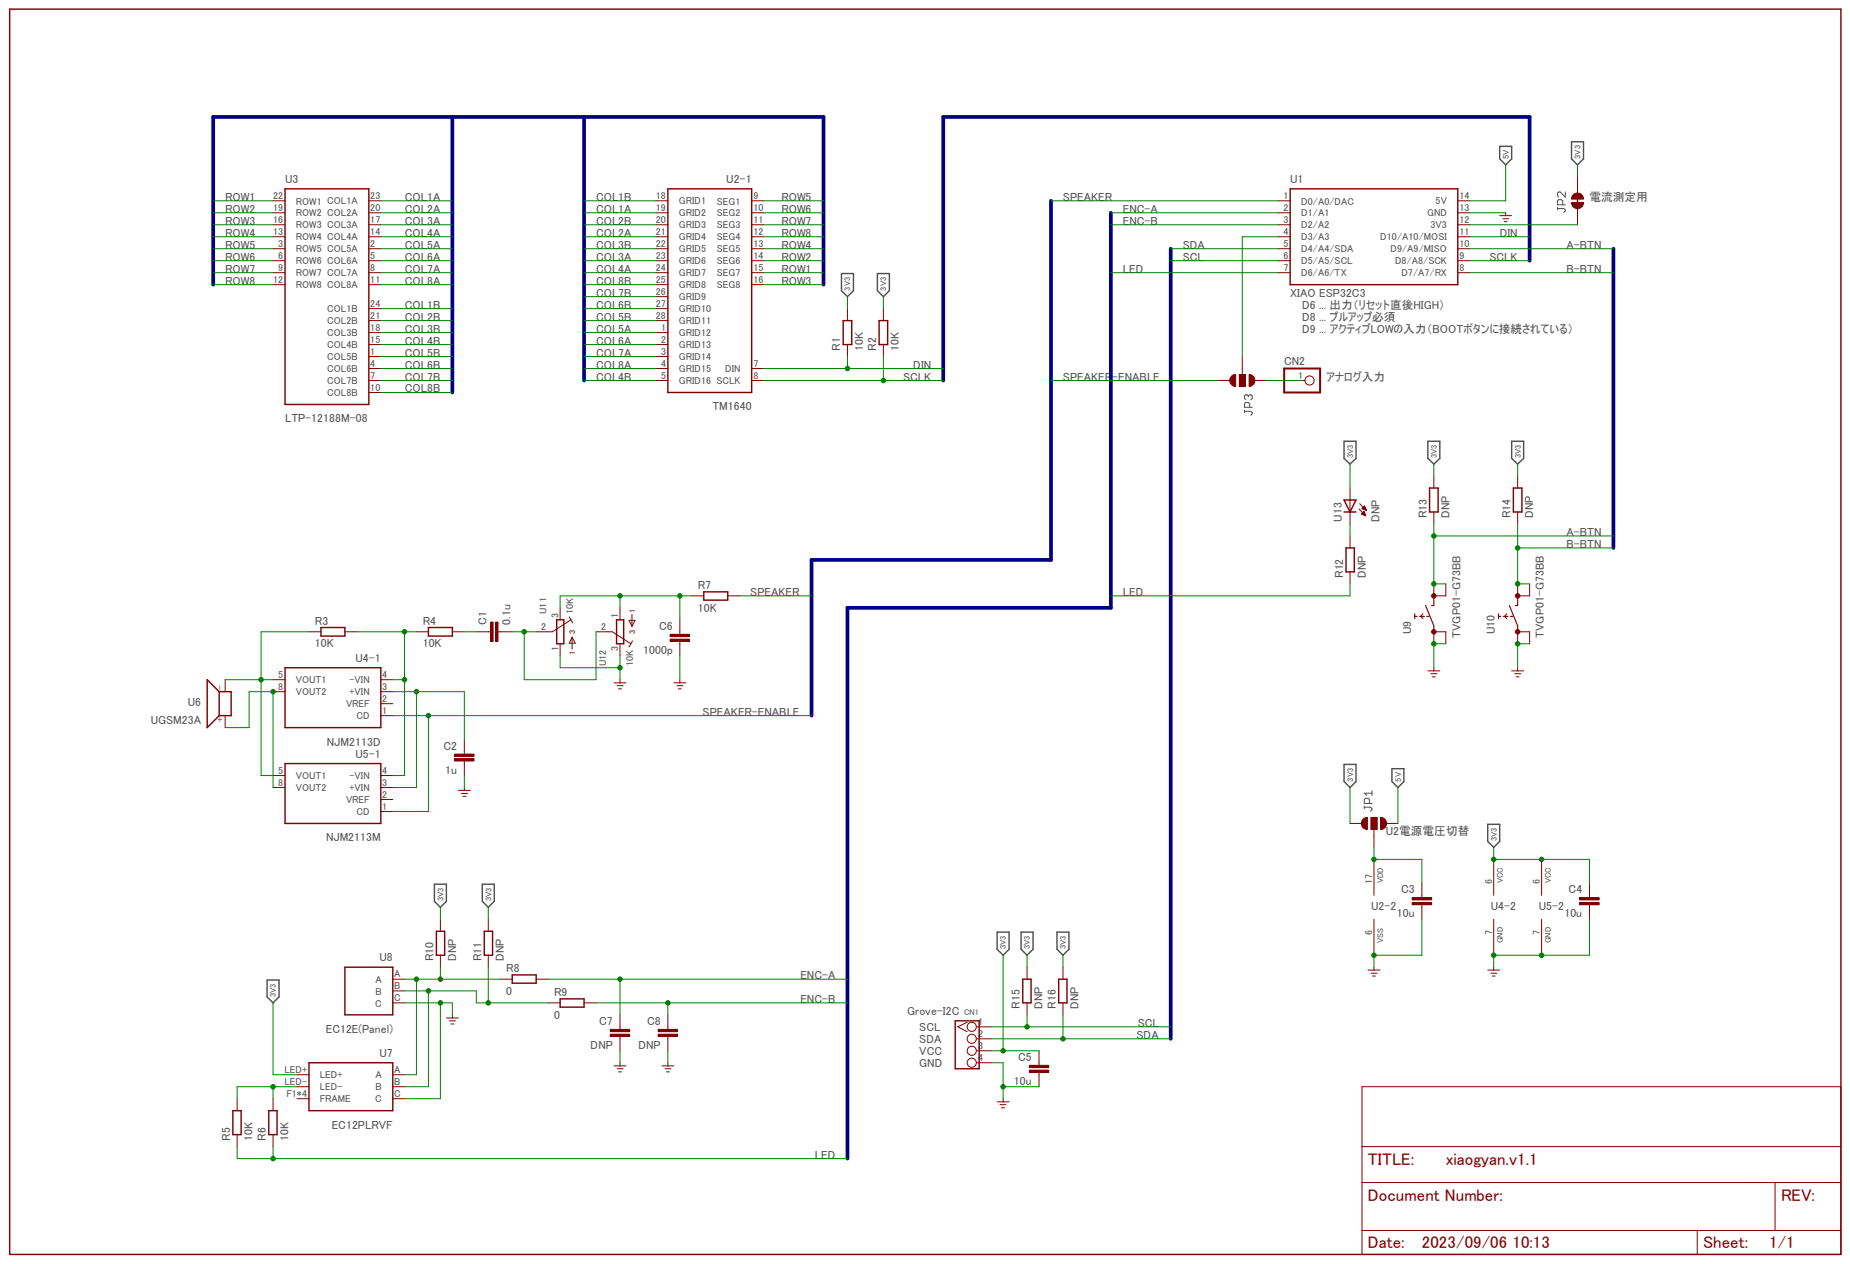
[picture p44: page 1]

Document Number: | REV:

Date: 2023/09/06 10:13 | Sheet: 1/1

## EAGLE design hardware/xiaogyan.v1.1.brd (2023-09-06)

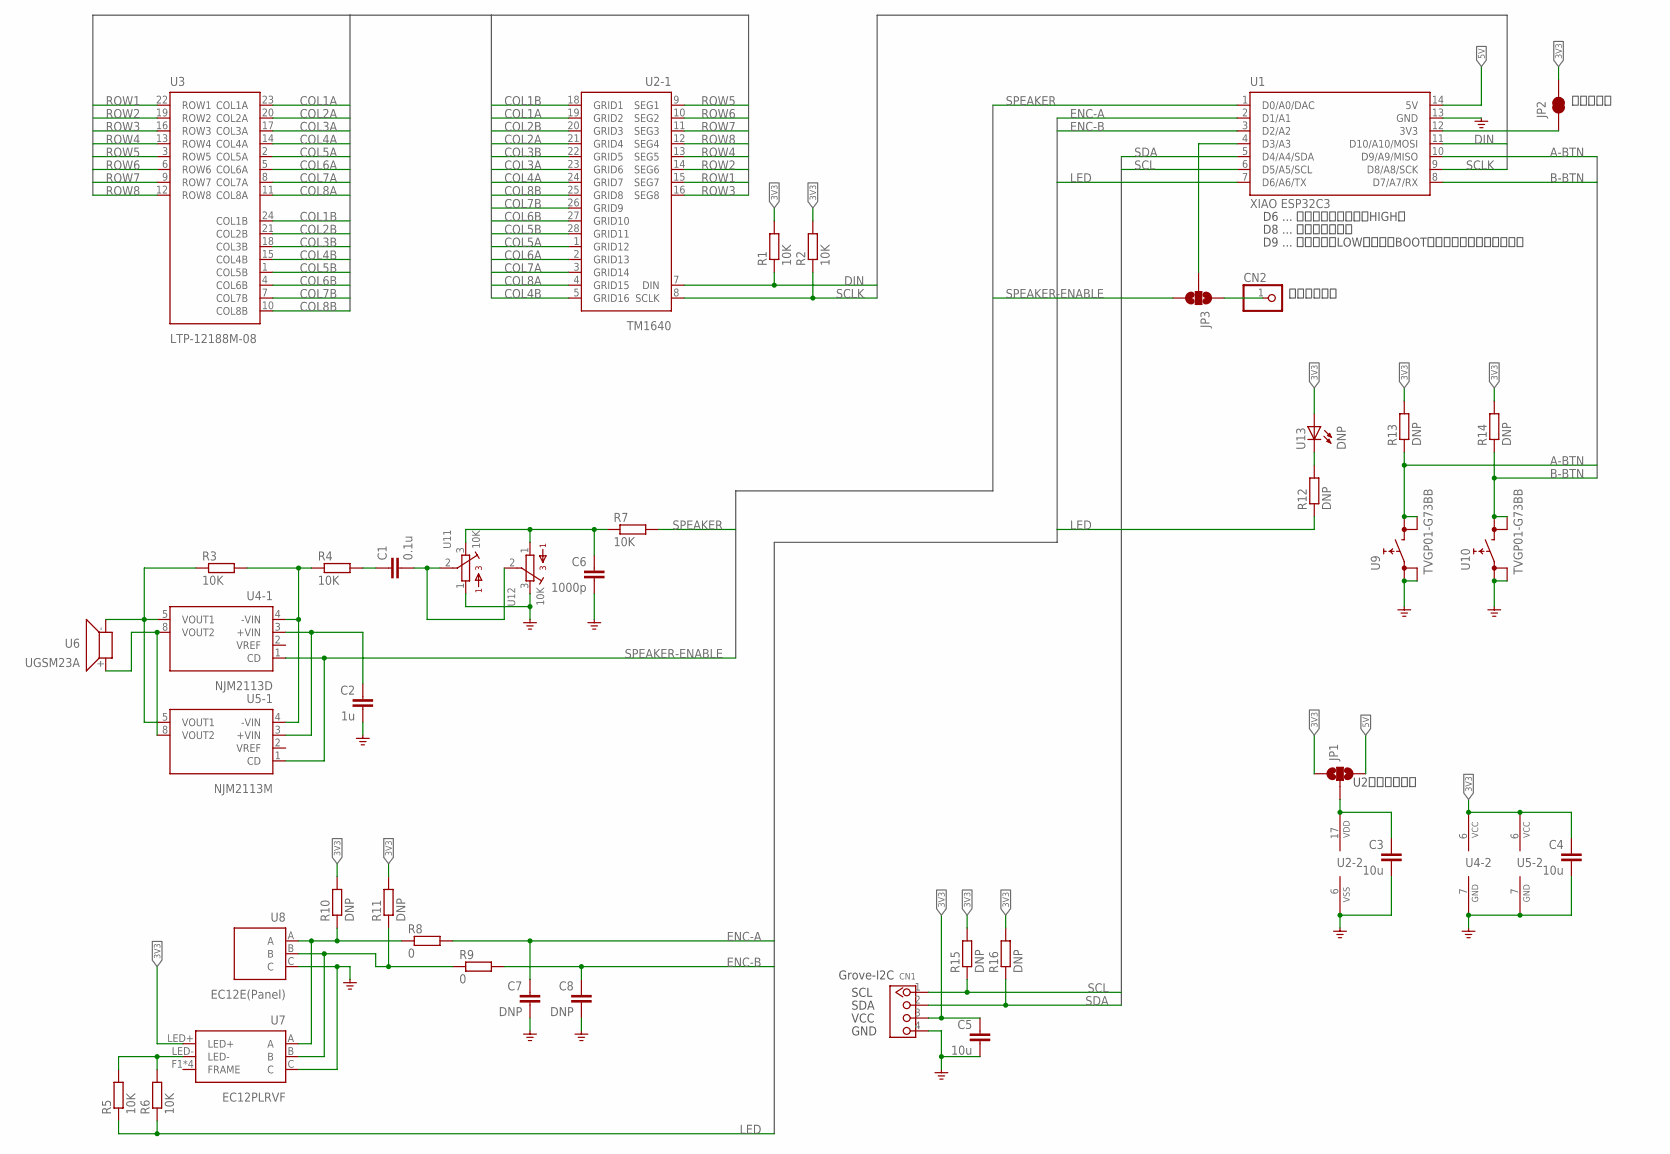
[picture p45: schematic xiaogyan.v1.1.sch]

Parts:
C1: 0.1u; C0603
C2: 1u; C0603
C3, C4, C5: 10u; C0603
C6: 1000p; C0805
C7, C8: DNP; C0603
CN1: 4P-2.0; HW4-2.0
CN2: PINHD-1X1; 1X01
JP1, JP3: JUMPER-SMT_3_NO_SILK; SMT-JUMPER_3_NO_SILK
JP2: JUMPER-SMT_2_NC_TRACE_SILK; SMT-JUMPER_2_NC_TRACE_SILK
R1, R2, R3, R4, R5, R6, R7: 10K; R0603
R8, R9: 0; R0603
R10, R11, R12, R13, R14, R15, R16: DNP; R0603
U1: XIAO ESP32C3; SEEEDUINOXIAO
U2: TM1640
U3: LTP-12188M-08; LTP-12188M
U4: NJM2113D; DIL08
U5: NJM2113M; SO08
U6: UGSM23A
U7: EC12PLRVF
U8: EC12E(Panel); EC12E_PANEL
U9, U10: TVGP01-G73BB
U11: 10K; 3386K
U12: 10K; 3386T
U13: DNP; LED5MM

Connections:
3V3: C4.1, C5.1, CN1.3, JP1.1, JP2.2, R1.2, R2.2, R10.2, R11.2, R13.2, R14.2, R15.2, R16.2, U4.6 (VCC), U5.6 (VCC), U7.LED+, U13.A
5V: JP1.3, U1.14 (5V)
A-BTN: R13.1, U1.10 (D9/A9/MISO), U9.3 (1), U9.4 (1)
B-BTN: R14.1, U1.8 (D7/A7/RX), U10.3 (1), U10.4 (1)
COL1A: U2.19 (GRID2), U3.23 (COL1A)
COL1B: U2.18 (GRID1), U3.24 (COL1B)
COL2A: U2.21 (GRID4), U3.20 (COL2A)
COL2B: U2.20 (GRID3), U3.21 (COL2B)
COL3A: U2.23 (GRID6), U3.17 (COL3A)
COL3B: U2.22 (GRID5), U3.18 (COL3B)
COL4A: U2.24 (GRID7), U3.14 (COL4A)
COL4B: U2.5 (GRID16), U3.15 (COL4B)
COL5A: U2.1 (GRID12), U3.2 (COL5A)
COL5B: U2.28 (GRID11), U3.1 (COL5B)
COL6A: U2.2 (GRID13), U3.5 (COL6A)
COL6B: U2.27 (GRID10), U3.4 (COL6B)
COL7A: U2.3 (GRID14), U3.8 (COL7A)
COL7B: U2.26 (GRID9), U3.7 (COL7B)
COL8A: U2.4 (GRID15), U3.11 (COL8A)
COL8B: U2.25 (GRID8), U3.10 (COL8B)
DIN: R1.1, U1.11 (D10/A10/MOSI), U2.7 (DIN)
ENC-A: C7.1, R8.2, U1.2 (D1/A1)
ENC-B: C8.1, R9.2, U1.3 (D2/A2)
GND: C2.2, C3.2, C4.2, C5.2, C6.2, C7.2, C8.2, CN1.4, U1.13 (GND), U2.6 (VSS), U4.7 (GND), U5.7 (GND), U7.C, U8.C, U9.1 (0), U9.2 (0), U10.1 (0), U10.2 (0), U11.1, U12.3
LED: R5.1, R6.1, R12.1, U1.7 (D6/A6/TX)
unnamed: R3.1, U4.5 (VOUT1), U5.5 (VOUT1), U6.- (2)
unnamed: R3.2, R4.1, U4.4 (-VIN), U5.4 (-VIN)
unnamed: U4.8 (VOUT2), U5.8 (VOUT2), U6.+ (1)
unnamed: C1.1, R4.2
unnamed: C2.1, U4.3 (+VIN), U5.3 (+VIN)
unnamed: R5.2, R6.2, U7.LED-
unnamed: R8.1, R10.1, U7.A, U8.A
unnamed: C1.2, U11.2, U12.2
unnamed: R9.1, R11.1, U7.B, U8.B
unnamed: C6.1, R7.1, U11.3, U12.1
unnamed: R12.2, U13.K (C)
unnamed: JP3.2, U1.4 (D3/A3)
unnamed: C3.1, JP1.2, U2.17 (VDD)
unnamed: JP2.1, U1.12 (3V3)
unnamed: CN2.1, JP3.1
ROW1: U2.15 (SEG7), U3.22 (ROW1)
ROW2: U2.14 (SEG6), U3.19 (ROW2)
ROW3: U2.16 (SEG8), U3.16 (ROW3)
ROW4: U2.13 (SEG5), U3.13 (ROW4)
ROW5: U2.9 (SEG1), U3.3 (ROW5)
ROW6: U2.10 (SEG2), U3.6 (ROW6)
ROW7: U2.11 (SEG3), U3.9 (ROW7)
ROW8: U2.12 (SEG4), U3.12 (ROW8)
SCL: CN1.1, R15.1, U1.6 (D5/A5/SCL)
SCLK: R2.1, U1.9 (D8/A8/SCK), U2.8 (SCLK)
SDA: CN1.2, R16.1, U1.5 (D4/A4/SDA)
SPEAKER: R7.2, U1.1 (D0/A0/DAC)
SPEAKER-ENABLE: JP3.3, U4.1 (CD), U5.1 (CD)

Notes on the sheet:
Grove-I2C
SCL
SDA
VCC
GND
D9 ... アクティブLOWの入力（BOOTボタンに接続されている）
D6 ... 出力（リセット直後HIGH）
電流測定用
アナログ入力
U2電源電圧切替
D8 ... プルアップ必須

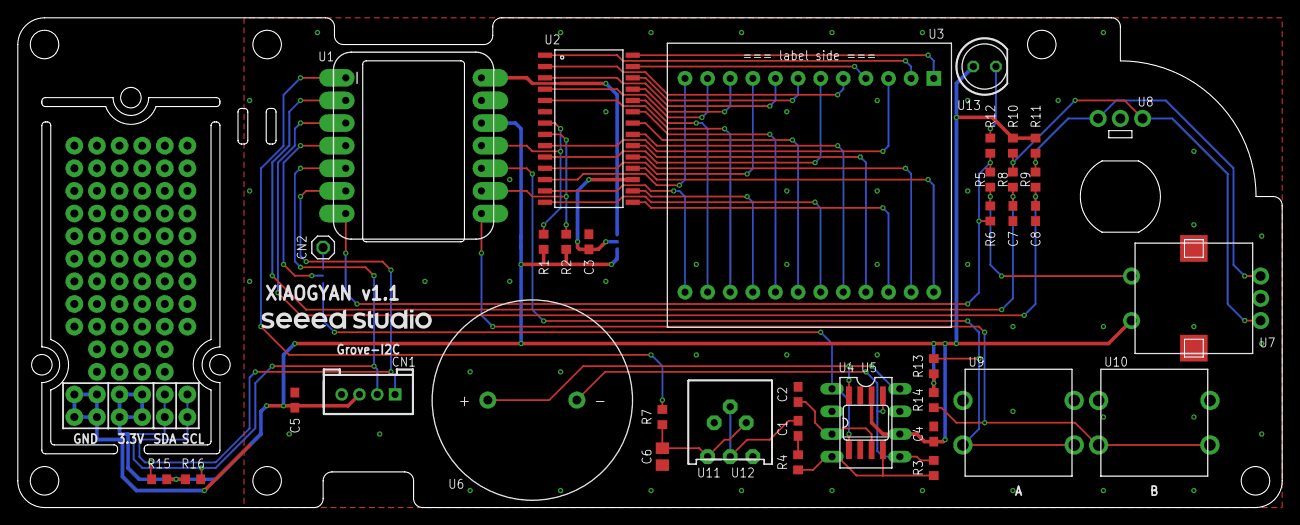
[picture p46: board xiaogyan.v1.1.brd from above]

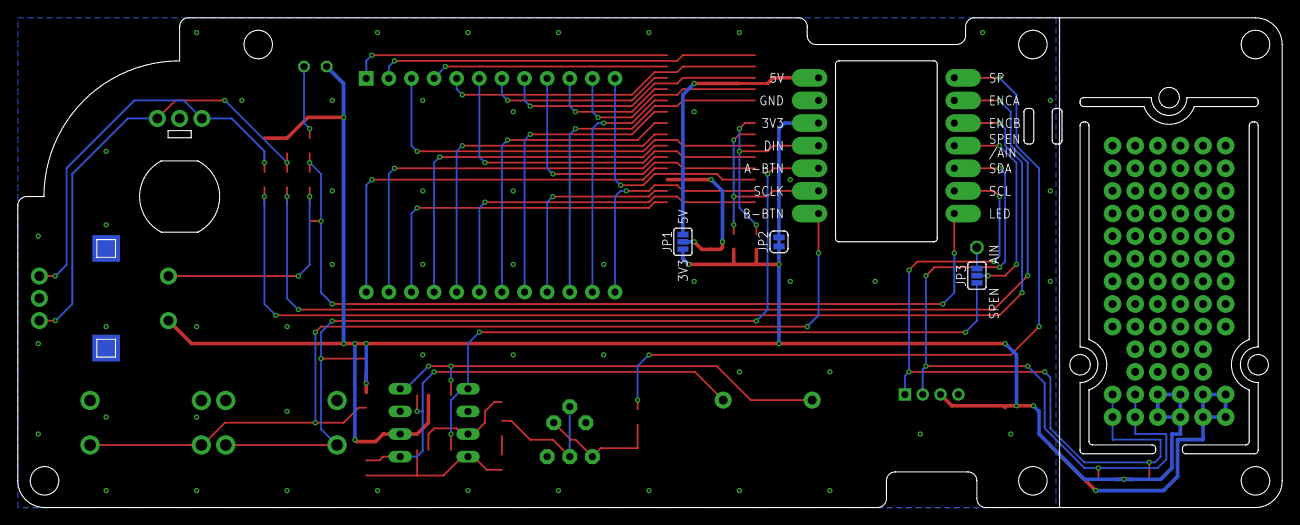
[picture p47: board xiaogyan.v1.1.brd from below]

Board: 2 copper layers, 142.0 x 55.0 mm, 42 parts (3 on the bottom side), 53 nets.

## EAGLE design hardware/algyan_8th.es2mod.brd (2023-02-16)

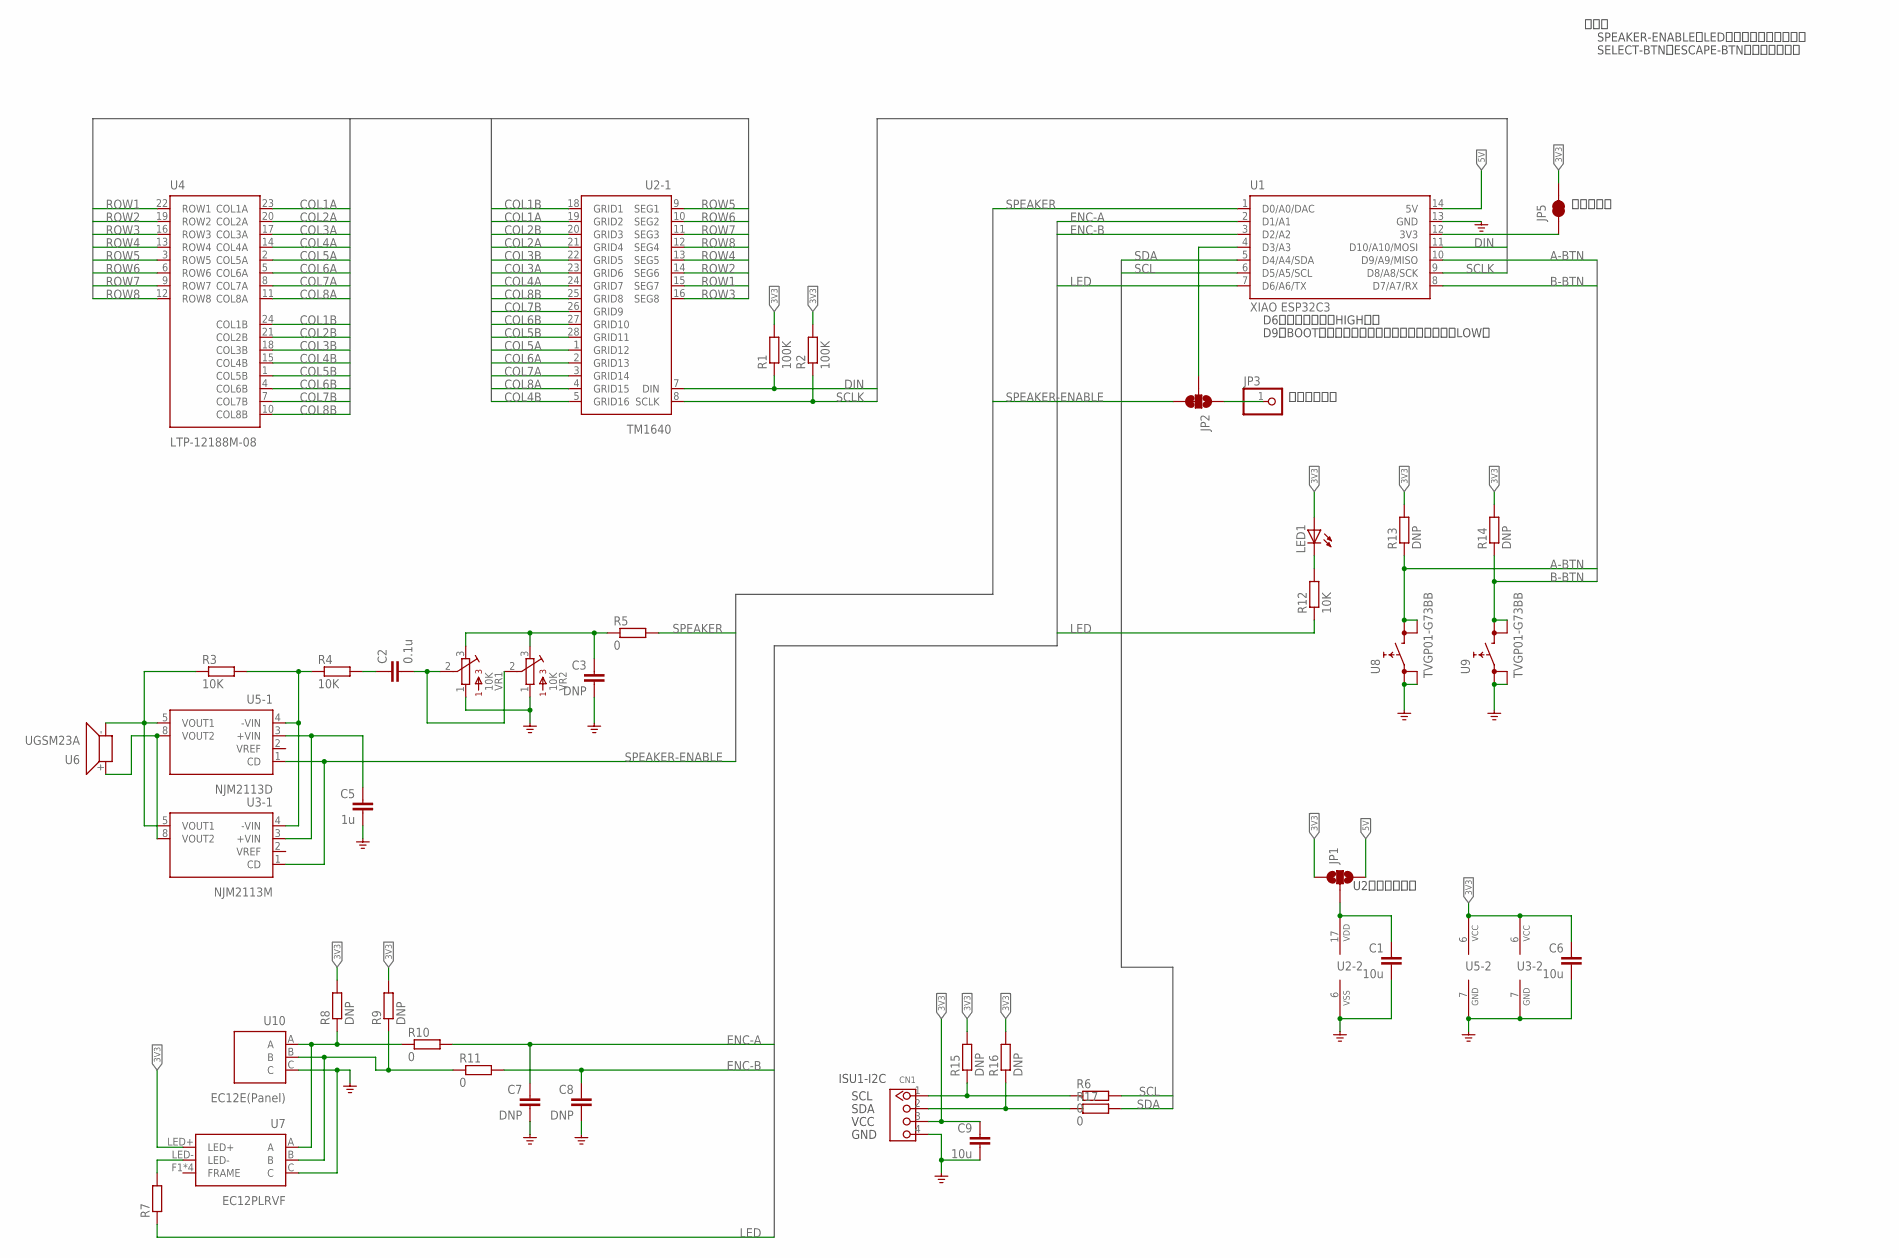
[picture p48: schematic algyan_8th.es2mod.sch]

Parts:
C1, C6, C9: 10u; C0603
C2: 0.1u; C0603
C3: DNP; C0805
C5: 1u; C0603
C7, C8: DNP; C0603
CN1: 4P-2.0; HW4-2.0
JP1: JUMPER-SMT_3_NO_SILK; SMT-JUMPER_3_NO_SILK
JP2: JUMPER-SMT_3_1-NC_TRACE_SILK; SMT-JUMPER_3_1-NC_TRACE_SILK
JP3: PINHD-1X1; 1X01
JP5: JUMPER-SMT_2_NC_TRACE_SILK; SMT-JUMPER_2_NC_TRACE_SILK
LED1: LED5MM
R1, R2: 100K; R0603
R3, R4, R12: 10K; R0603
R5, R6, R10, R11, R17: 0; R0603
R7: R-EU_R0603; R0603
R8, R9, R13, R14, R15, R16: DNP; R0603
U1: XIAO ESP32C3; SEEEDUINOXIAO
U2: TM1640
U3: NJM2113M; SO08
U4: LTP-12188M-08; LTP-12188M
U5: NJM2113D; DIL08
U6: UGSM23A
U7: EC12PLRVF
U8, U9: TVGP01-G73BB
U10: EC12E(Panel); EC12E_PANEL
VR1: 10K; 3386K
VR2: 10K; 3386T

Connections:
3V3: C6.1, C9.1, CN1.3, JP1.1, JP5.2, LED1.A, R1.2, R2.2, R8.2, R9.2, R13.2, R14.2, R15.2, R16.2, U3.6 (VCC), U5.6 (VCC), U7.LED+
5V: JP1.3, U1.14 (5V)
A-BTN: R13.1, U1.10 (D9/A9/MISO), U8.3 (1), U8.4 (1)
B-BTN: R14.1, U1.8 (D7/A7/RX), U9.3 (1), U9.4 (1)
COL1A: U2.19 (GRID2), U4.23 (COL1A)
COL1B: U2.18 (GRID1), U4.24 (COL1B)
COL2A: U2.21 (GRID4), U4.20 (COL2A)
COL2B: U2.20 (GRID3), U4.21 (COL2B)
COL3A: U2.23 (GRID6), U4.17 (COL3A)
COL3B: U2.22 (GRID5), U4.18 (COL3B)
COL4A: U2.24 (GRID7), U4.14 (COL4A)
COL4B: U2.5 (GRID16), U4.15 (COL4B)
COL5A: U2.1 (GRID12), U4.2 (COL5A)
COL5B: U2.28 (GRID11), U4.1 (COL5B)
COL6A: U2.2 (GRID13), U4.5 (COL6A)
COL6B: U2.27 (GRID10), U4.4 (COL6B)
COL7A: U2.3 (GRID14), U4.8 (COL7A)
COL7B: U2.26 (GRID9), U4.7 (COL7B)
COL8A: U2.4 (GRID15), U4.11 (COL8A)
COL8B: U2.25 (GRID8), U4.10 (COL8B)
DIN: R1.1, U1.11 (D10/A10/MOSI), U2.7 (DIN)
ENC-A: C7.1, R10.2, U1.2 (D1/A1)
ENC-B: C8.1, R11.2, U1.3 (D2/A2)
GND: C1.2, C3.2, C5.2, C6.2, C7.2, C8.2, C9.2, CN1.4, U1.13 (GND), U2.6 (VSS), U3.7 (GND), U5.7 (GND), U7.C, U8.1 (0), U8.2 (0), U9.1 (0), U9.2 (0), U10.C, VR1.1, VR2.1
LED: R7.1, R12.1, U1.7 (D6/A6/TX)
unnamed: R3.1, U3.5 (VOUT1), U5.5 (VOUT1), U6.- (2)
unnamed: R3.2, R4.1, U3.4 (-VIN), U5.4 (-VIN)
unnamed: U3.8 (VOUT2), U5.8 (VOUT2), U6.+ (1)
unnamed: C2.1, R4.2
unnamed: C5.1, U3.3 (+VIN), U5.3 (+VIN)
unnamed: R7.2, U7.LED-
unnamed: R8.1, R10.1, U7.A, U10.A
unnamed: C2.2, VR1.2, VR2.2
unnamed: R9.1, R11.1, U7.B, U10.B
unnamed: C3.1, R5.1, VR1.3, VR2.3
unnamed: LED1.K (C), R12.2
unnamed: JP2.2, U1.4 (D3/A3)
unnamed: C1.1, JP1.2, U2.17 (VDD)
unnamed: JP5.1, U1.12 (3V3)
unnamed: JP2.1, JP3.1
unnamed: CN1.1, R6.1, R15.1
unnamed: CN1.2, R16.1, R17.1
ROW1: U2.15 (SEG7), U4.22 (ROW1)
ROW2: U2.14 (SEG6), U4.19 (ROW2)
ROW3: U2.16 (SEG8), U4.16 (ROW3)
ROW4: U2.13 (SEG5), U4.13 (ROW4)
ROW5: U2.9 (SEG1), U4.3 (ROW5)
ROW6: U2.10 (SEG2), U4.6 (ROW6)
ROW7: U2.11 (SEG3), U4.9 (ROW7)
ROW8: U2.12 (SEG4), U4.12 (ROW8)
SCL: R6.2, U1.6 (D5/A5/SCL)
SCLK: R2.1, U1.9 (D8/A8/SCK), U2.8 (SCLK)
SDA: R17.2, U1.5 (D4/A4/SDA)
SPEAKER: R5.2, U1.1 (D0/A0/DAC)
SPEAKER-ENABLE: JP2.3, U3.1 (CD), U5.1 (CD)

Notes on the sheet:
ISU1-I2C
SCL
SDA
VCC
GND
D9はBOOTボタンに接続されている（アクティブLOW）
D6はリセット直後HIGH出力
電流測定用
アナログ入力
U2電源電圧切替
変更点
SPEAKER-ENABLEとLEDのピン割当を入れ替え
SELECT-BTNとESCAPE-BTNの信号名を変更

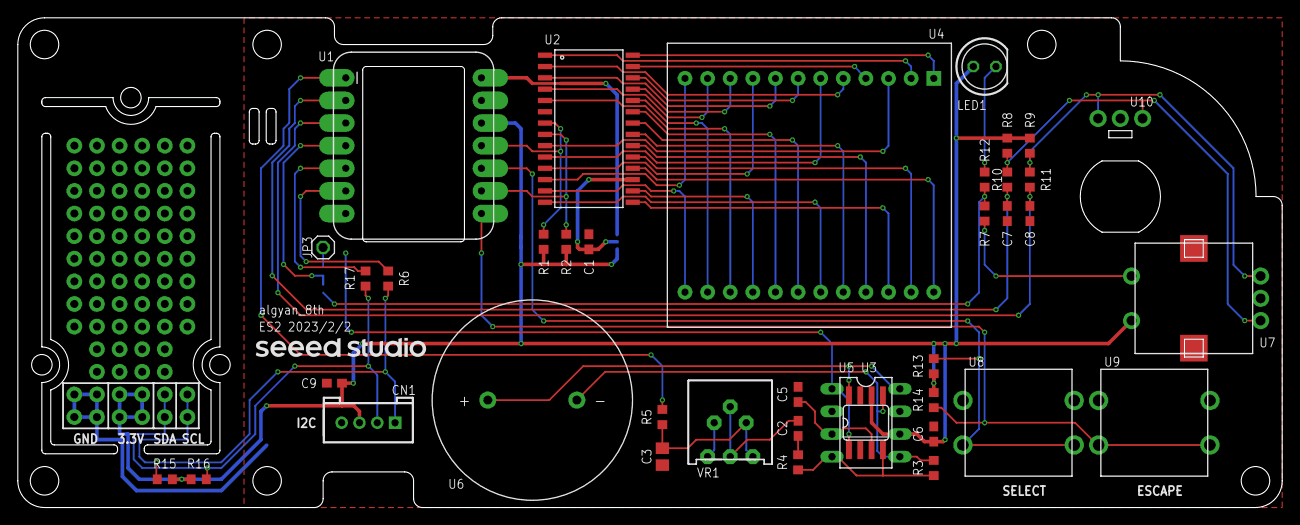
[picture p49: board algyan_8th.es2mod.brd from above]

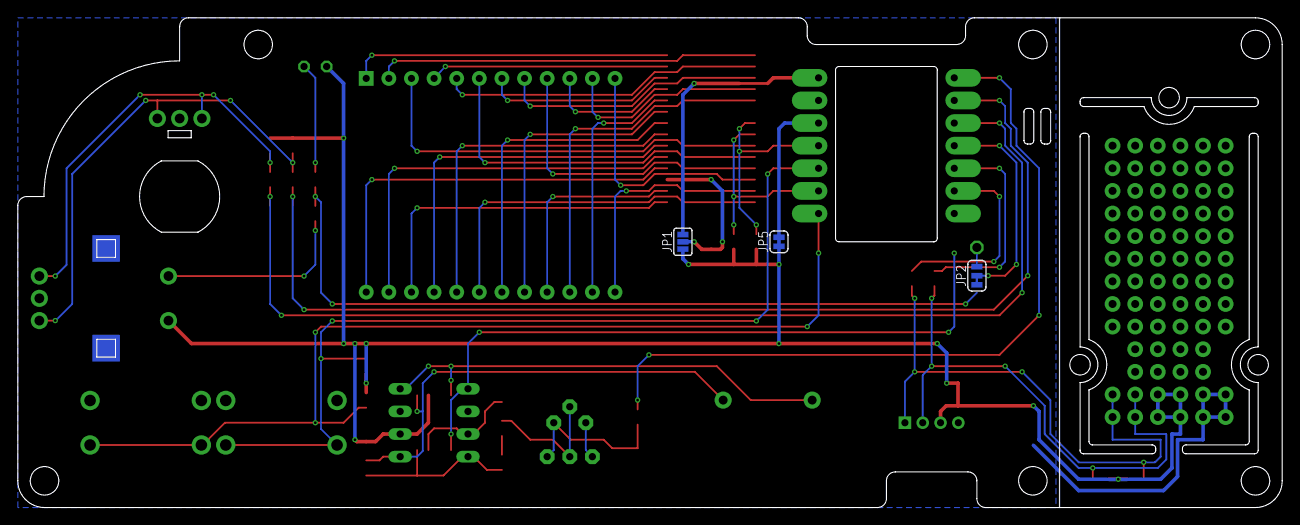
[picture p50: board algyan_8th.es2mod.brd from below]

Board: 2 copper layers, 142.0 x 55.0 mm, 43 parts (3 on the bottom side), 55 nets.

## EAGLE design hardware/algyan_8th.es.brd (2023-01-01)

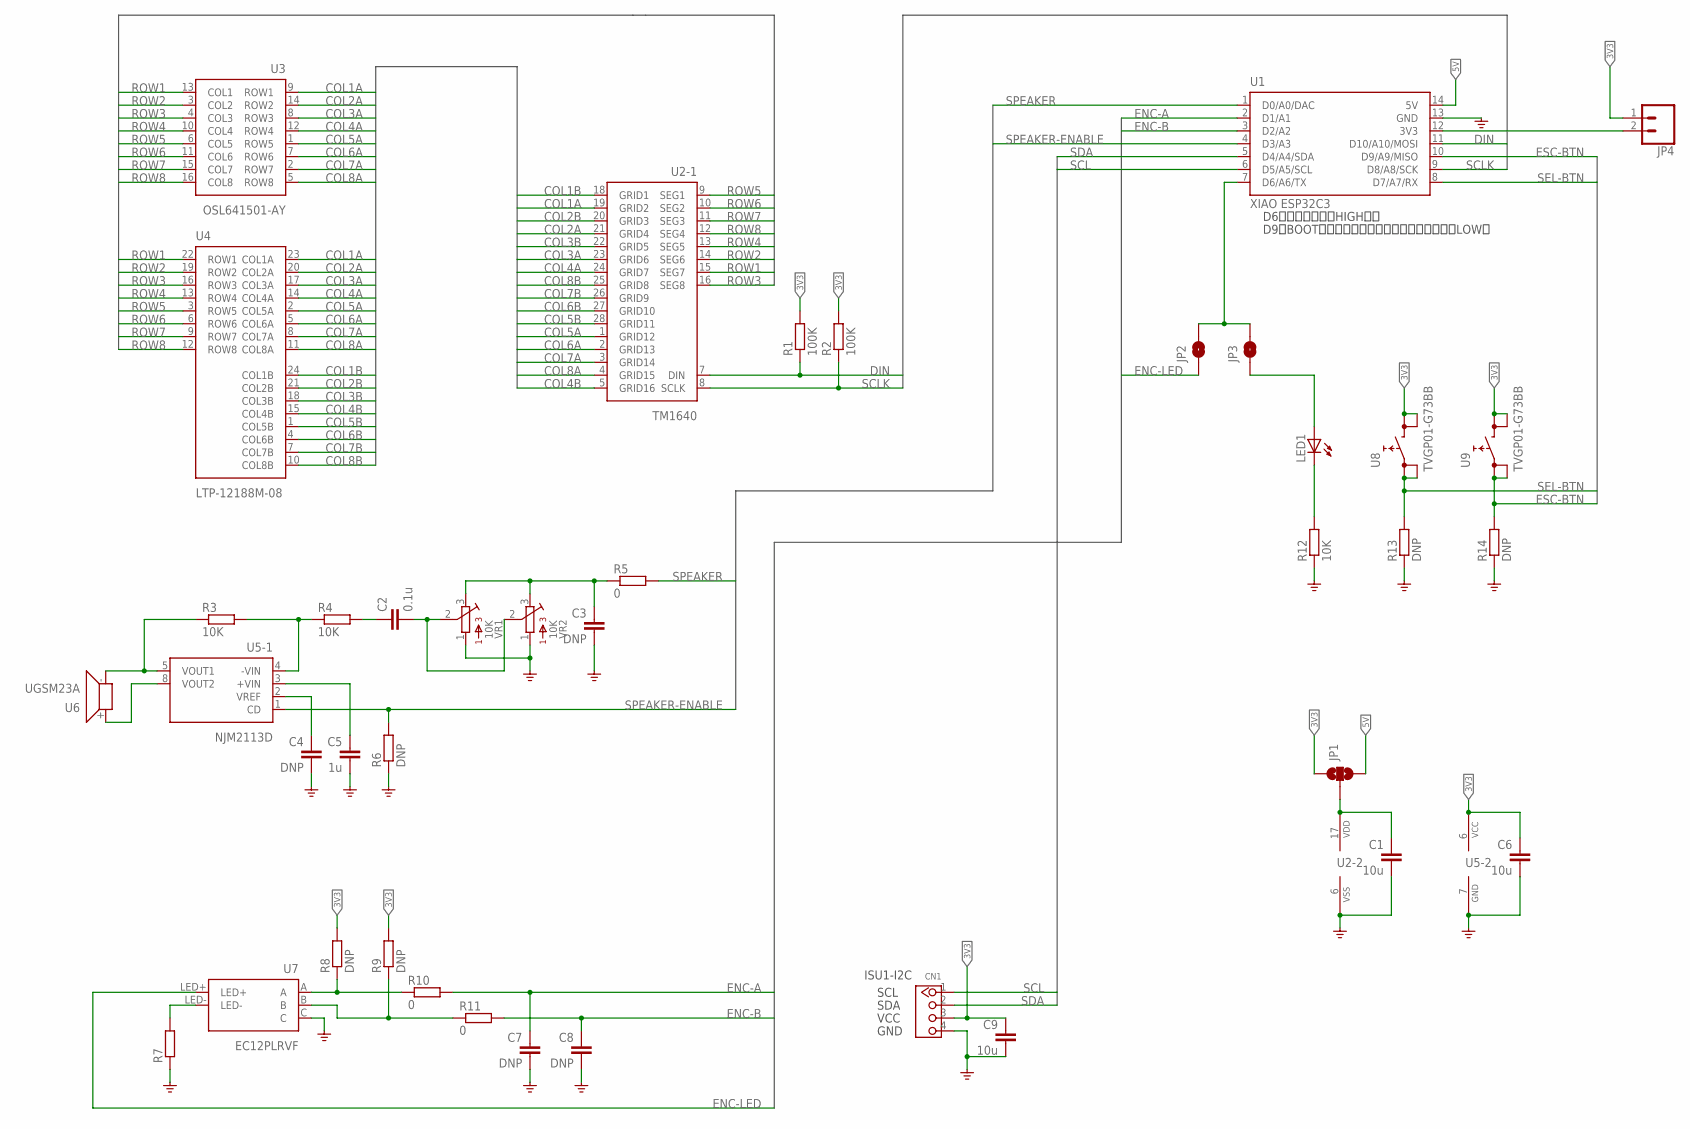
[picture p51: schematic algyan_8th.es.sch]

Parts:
C1, C6, C9: 10u; C0805
C2: 0.1u; C0603
C3, C4: DNP; C0805
C5: 1u; C0805
C7, C8: DNP; C0603
CN1: 4P-2.0; HW4-2.0
JP1: JUMPER-SMT_3_NO_SILK; SMT-JUMPER_3_NO_SILK
JP2, JP3: JUMPER-SMT_2_NO_SILK; SMT-JUMPER_2_NO_SILK
JP4: CONN_02; 1X02
LED1: LED5MM
R1, R2: 100K; R0603
R3, R4, R12: 10K; R0603
R5, R10, R11: 0; R0603
R6, R8, R9, R13, R14: DNP; R0603
R7: R-EU_R0603; R0603
U1: XIAO ESP32C3; SEEEDUINOXIAO
U2: TM1640
U3: OSL641501-AY; OSL641501
U4: LTP-12188M-08; LTP-12188M
U5: NJM2113D; DIL08
U6: UGSM23A
U7: EC12PLRVF
U8, U9: TVGP01-G73BB
VR1: 10K; 3386K
VR2: 10K; 3386T

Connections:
3V3: C6.1, C9.1, CN1.3, JP1.1, JP4.1, R1.2, R2.2, R8.2, R9.2, U5.6 (VCC), U8.3 (1), U8.4 (1), U9.3 (1), U9.4 (1)
5V: JP1.3, U1.14 (5V)
COL1A: U2.19 (GRID2), U3.9 (ROW1), U4.23 (COL1A)
COL1B: U2.18 (GRID1), U4.24 (COL1B)
COL2A: U2.21 (GRID4), U3.14 (ROW2), U4.20 (COL2A)
COL2B: U2.20 (GRID3), U4.21 (COL2B)
COL3A: U2.23 (GRID6), U3.8 (ROW3), U4.17 (COL3A)
COL3B: U2.22 (GRID5), U4.18 (COL3B)
COL4A: U2.24 (GRID7), U3.12 (ROW4), U4.14 (COL4A)
COL4B: U2.5 (GRID16), U4.15 (COL4B)
COL5A: U2.1 (GRID12), U3.1 (ROW5), U4.2 (COL5A)
COL5B: U2.28 (GRID11), U4.1 (COL5B)
COL6A: U2.2 (GRID13), U3.7 (ROW6), U4.5 (COL6A)
COL6B: U2.27 (GRID10), U4.4 (COL6B)
COL7A: U2.3 (GRID14), U3.2 (ROW7), U4.8 (COL7A)
COL7B: U2.26 (GRID9), U4.7 (COL7B)
COL8A: U2.4 (GRID15), U3.5 (ROW8), U4.11 (COL8A)
COL8B: U2.25 (GRID8), U4.10 (COL8B)
DIN: R1.1, U1.11 (D10/A10/MOSI), U2.7 (DIN)
ENC-A: C7.1, R10.2, U1.2 (D1/A1)
ENC-B: C8.1, R11.2, U1.3 (D2/A2)
ENC-LED: JP2.1, U7.LED+
ESC-BTN: R14.2, U1.10 (D9/A9/MISO), U9.1 (0), U9.2 (0)
GND: C1.2, C3.2, C4.2, C5.2, C6.2, C7.2, C8.2, C9.2, CN1.4, R6.1, R7.1, R12.1, R13.1, R14.1, U1.13 (GND), U2.6 (VSS), U5.7 (GND), U7.C, VR1.1, VR2.1
LED: JP3.1, LED1.A
unnamed: R3.1, U5.5 (VOUT1), U6.- (2)
unnamed: R3.2, R4.1, U5.4 (-VIN)
unnamed: U5.8 (VOUT2), U6.+ (1)
unnamed: C2.1, R4.2
unnamed: C5.1, U5.3 (+VIN)
unnamed: C4.1, U5.2 (VREF)
unnamed: R8.1, R10.1, U7.A
unnamed: C2.2, VR1.2, VR2.2
unnamed: R9.1, R11.1, U7.B
unnamed: C3.1, R5.1, VR1.3, VR2.3
unnamed: LED1.K (C), R12.2
unnamed: JP2.2, JP3.2, U1.7 (D6/A6/TX)
unnamed: C1.1, JP1.2, U2.17 (VDD)
unnamed: R7.2, U7.LED-
unnamed: JP4.2, U1.12 (3V3)
ROW1: U2.15 (SEG7), U3.13 (COL1), U4.22 (ROW1)
ROW2: U2.14 (SEG6), U3.3 (COL2), U4.19 (ROW2)
ROW3: U2.16 (SEG8), U3.4 (COL3), U4.16 (ROW3)
ROW4: U2.13 (SEG5), U3.10 (COL4), U4.13 (ROW4)
ROW5: U2.9 (SEG1), U3.6 (COL5), U4.3 (ROW5)
ROW6: U2.10 (SEG2), U3.11 (COL6), U4.6 (ROW6)
ROW7: U2.11 (SEG3), U3.15 (COL7), U4.9 (ROW7)
ROW8: U2.12 (SEG4), U3.16 (COL8), U4.12 (ROW8)
SCL: CN1.1, U1.6 (D5/A5/SCL)
SCLK: R2.1, U1.9 (D8/A8/SCK), U2.8 (SCLK)
SDA: CN1.2, U1.5 (D4/A4/SDA)
SEL-BTN: R13.2, U1.8 (D7/A7/RX), U8.1 (0), U8.2 (0)
SPEAKER: R5.2, U1.1 (D0/A0/DAC)
SPEAKER-ENABLE: R6.2, U1.4 (D3/A3), U5.1 (CD)

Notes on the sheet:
ISU1-I2C
SCL
SDA
VCC
GND
D9はBOOTボタンに接続されている（アクティブLOW）
D6はリセット直後HIGH出力

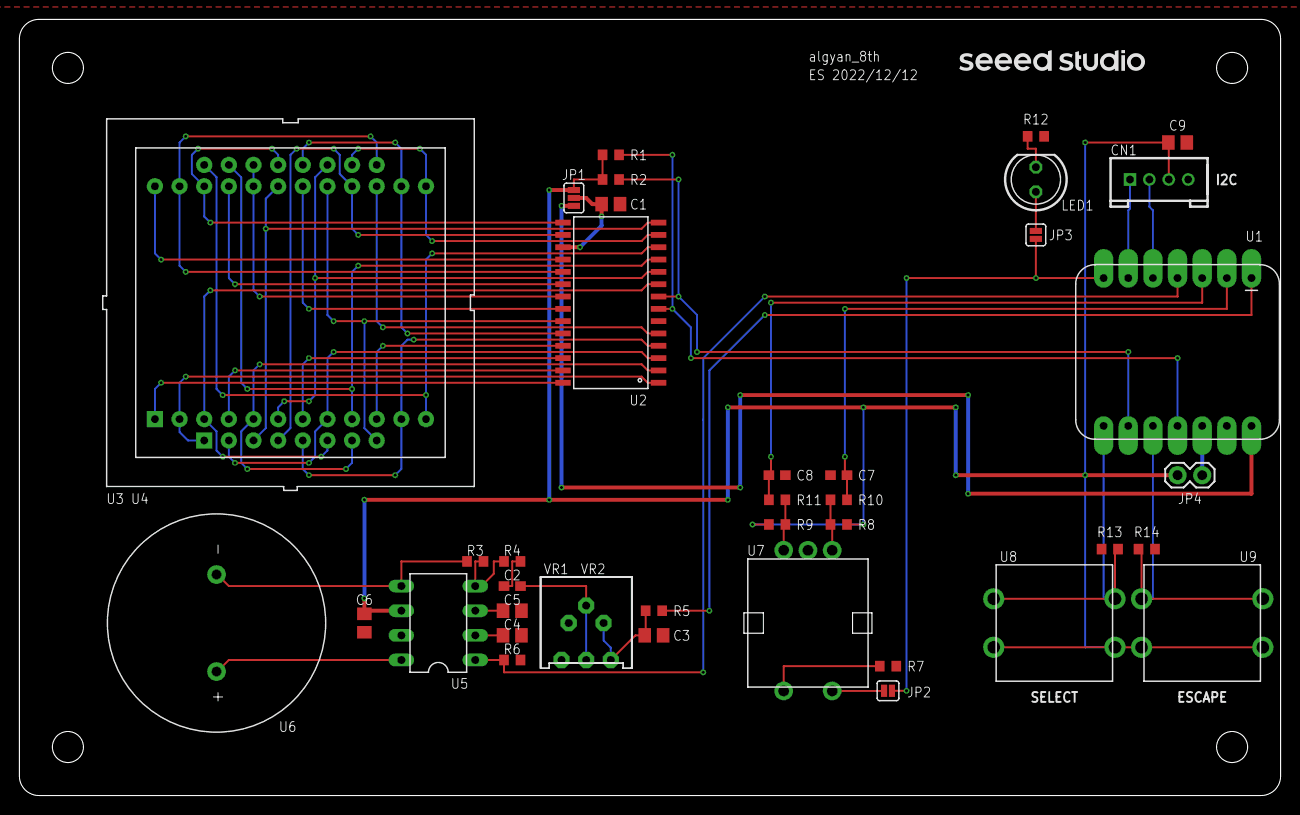
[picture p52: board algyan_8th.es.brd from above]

Board: 2 copper layers, 130.0 x 80.0 mm, 40 parts (0 on the bottom side), 54 nets.

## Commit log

2022-11-24 README更新
2022-12-05 LedMatrixTM1640追加
2022-12-05 LEDマトリックスを2色のものに変更
2022-12-06 Speaker追加
2022-12-12 ES基板のEAGLEファイルを追加
    [algyan_8th.es.brd, algyan_8th.es.sch]
2022-12-18 ES基板の回路図PDFを追加
2022-12-19 LedMatrixTM1640を改修
2022-12-20 Speaker2追加
2022-12-20 不要なファイルを削除
2022-12-21 Speaker2を改修
2022-12-21 Encoder追加
2022-12-25 ES基板の結線に変更
2022-12-26 ES基板の回路図に部品の値を記入
    [algyan_8th.es.brd, algyan_8th.es.sch]
2022-12-29 ButtonAndLed追加(WIP)
2023-01-01 ButtonAndLedを改修
2023-01-01 GroveAccelerometer16G追加
2023-01-07 ES2基板のEAGLEファイルと回路図PDFを追加
    [algyan_8th.es2.brd, algyan_8th.es2.sch]
2023-02-02 ES2基板のEAGLEファイルと回路図PDFを修正
    [algyan_8th.es2.brd, algyan_8th.es2.sch]
2023-02-02 ES2基板のBOMを追加
    [algyan_8th.es2.xlsx]
2023-02-10 Fix #25
    [algyan_8th.es2.brd, algyan_8th.es2.sch]
2023-02-16 ES2MOD基板に変更
    [algyan_8th.es2mod.brd, algyan_8th.es2mod.sch]
2023-02-16 サンプルコードを整理
2023-02-16 AnalogIn追加
2023-02-16 ES3基板のEAGLEファイルと回路図PDFを追加
    [algyan_8th.es3.brd, algyan_8th.es3.sch]
2023-02-17 コードを分離
2023-02-19 "XIAOGYAN"に名前変更
2023-02-19 ライブラリを別リポジトリへ
2023-03-06 ES3基板のBOMを追加
    [algyan_8th.es2.xlsx, algyan_8th.es3.xlsx]
2023-03-20 v1部品番号を記入
    [algyan_8th.es3.xlsx]
2023-03-27 xiaogyan.v1を追加
    [xiaogyan.v1.brd, xiaogyan.v1.sch, xiaogyan.v1.xlsx]
2023-04-08 部品を追加
    [xiaogyan.v1.xlsx]
2023-04-16 組立画像のアップロード
    まずは，基板と実装指示分のみ
2023-04-16 画像の埋め込みテスト
2023-04-16 画像の余白のトリミング
    白い余白付きの画像となってしまっていた為，トリミングして再アップ
2023-04-16 組立手順用の画像アップロード
2023-04-26 R7とC6を変更
    [xiaogyan.v1.brd, xiaogyan.v1.sch, xiaogyan.v1.xlsx]
2023-05-05 章立てを変更
2023-05-05 部品貼付台紙を追加
2023-05-05 ディレクトリ変更
2023-05-09 部品手配マニュアルを追加
2023-05-16 XIAOGYAN写真を差し替え
2023-05-17 動作確認マニュアルを追加
2023-05-17 esptoolのPythonバージョンを変更
2023-05-17 しおりを追加
2023-05-17 画像サイズを変更
2023-05-22 挿入実装品の組立用画像のアップロード
    オペアンプ，VR，ボタン，スピーカ，LEDマトリクス，エンコーダ
2023-05-22 挿入実装品の画像の更新
    Groveコネクタ，マイコン，ロータリエンコーダ
2023-05-22 C6とR7を実装に伴う変更
    1000pFは手元に無いため，図のみ変更で対応
2023-05-22 C6とR7を実装に伴う変更
    組立マニュアル側も変更
2023-05-22 R7とC6を変更(部品貼付台紙)
    部品貼付台紙のpdfを更新．合わせて原本であるxlsxを追加
    [xiaogyan_pasteboard.v1.xlsx]
2023-05-22 JP3 - SPENは無し
2023-05-23 C6 fixed
    C6を図示すべきところを誤ってC7を図示していた為
2023-05-23 Update README.md
    ・C6のリスト番号が誤っていた為に修正
    ・3.動作確認 を 3.チェック に変更
2023-05-28 guidebook更新
2023-06-11 チップコンデンサ(1000pF)のはんだ付け誤記修正
    リスト⑯の10uFとなっていたので修正
2023-06-12 Groveコネクタの取り付け画像の修正
    本来，L字コネクタのところI字のコネクタの写真としてしまっていた為に修正
    https://github.com/algyan/XIAOGYAN/issues/61
2023-06-12 Update README.md
    はんだ付けの順序の入替による更新
    https://github.com/algyan/XIAOGYAN/issues/57
2023-06-14 img45.PNGのC1とC2の青枠の漏れ修正
    https://github.com/algyan/XIAOGYAN/issues/53#issuecomment-1590338423
2023-06-20 ソフトウェア開発マニュアルを追加
2023-06-20 「ファームウェア」を「ソフトウェア」に変更
2023-06-20 画像ファイルの拡張子を訂正
2023-06-20 部品手配マニュアルに機材マニュアルへのリンクを追加
2023-09-06 PCB v1.1を追加
    [xiaogyan.v1.1.brd, xiaogyan.v1.1.sch]

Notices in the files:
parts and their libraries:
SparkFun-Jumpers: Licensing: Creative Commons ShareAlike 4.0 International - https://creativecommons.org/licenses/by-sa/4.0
